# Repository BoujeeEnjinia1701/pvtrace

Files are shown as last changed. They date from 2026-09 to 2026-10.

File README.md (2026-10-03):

# PVTrace

     

**Area:** CleanTech · **TRL:** 3 of 9 (proof of concept on paper) · **Prototype cost:** about USD 192 (value-engineering target USD 165) · **Difficulty:** 3 of 5

A handheld solar panel IV curve tracer that sweeps a panel's current and voltage in the field, flags shading, cracked cells and degraded strings, and helps grade second-life panels.

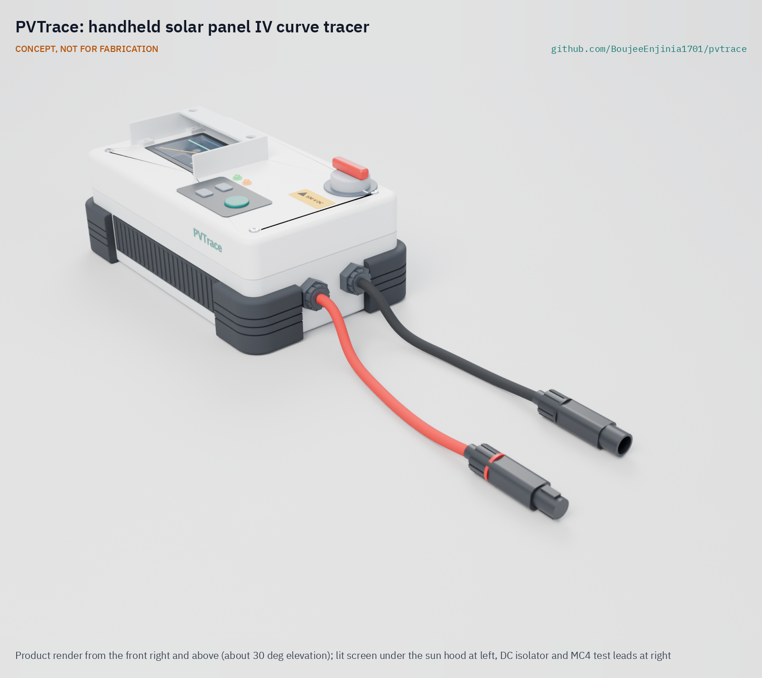
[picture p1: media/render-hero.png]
PVTrace: handheld solar panel IV curve tracer, product render


[Exploded render](media/render-exploded.png) · [Interactive 3D model](media/viewer.html) · [Concept blueprint (PDF)](media/concept-blueprint.pdf) · [General arrangement PVT-DWG-001 (PDF)](cad/drawings/PVT-DWG-001.pdf) · [Sizing calculations](docs/04-calcs/01-sizing.md) · [Prototype build plan](docs/05-build-plan.md) · [Design decisions](docs/06-design-decisions.md) · [Review note](docs/REVIEW.md)

## Concept rationale

An IV curve is the most informative single test of a solar module: one sweep from short circuit to open circuit shows its power, and the shape of the curve points to shading, a failed bypass diode, cracked cells, corroded connections or plain wear. PVTrace uses the simplest load that can trace that curve, a capacitor bank that the module charges in a few tens of milliseconds, as proven open designs such as [IV Swinger 2](https://github.com/csatt/IV_Swinger) and [Cáceres et al. (2020)](https://doi.org/10.3390/en13174320) have done. It adds what a field user needs: a handheld case with a screen, an irradiance reference cell and temperature probe, translation to standard test conditions and a transparent grading rule.

Keeping it open and garage-buildable matters because the people who most need to grade panels, small installers, repair shops and second-life programs in lower-income markets, are the least able to buy a commercial tracer. PVTrace stays below 100 V so it remains an extra-low-voltage instrument for single modules and short strings, uses about USD 178 of common parts, and writes every sweep to an open CSV file that anyone can check or reprocess.

## Burning platform

Solar is being installed faster than ever: global capacity rose to nearly 3 TW at the end of 2025, with about 698 GW added in that year ([IEA PVPS, 2026](https://iea-pvps.org/snapshot-reports/snapshot-2026/)). Panel waste could reach 78 million tonnes by 2050 ([IRENA and IEA PVPS, 2016](https://www.irena.org/publications/2016/Jun/End-of-life-management-Solar-Photovoltaic-Panels)), yet about 70 % of modules are taken down before the end of their 25 to 30 year design life ([Huang and Long, *Nature Communications*, 2026](https://www.nature.com/articles/s41467-026-69171-z)), and field data show a median power loss of only about 0.5 % a year ([Jordan and Kurtz, 2013](https://onlinelibrary.wiley.com/doi/abs/10.1002/pip.1182)). Many removed modules could work for years more.

The obstacle is trust. Refurbished modules exported to secondary markets show 10 to 20 % power loss and inconsistent quality ([Huang and Long, 2026](https://www.nature.com/articles/s41467-026-69171-z)), and a buyer cannot see that by eye. A commercial tracer that would show it costs thousands of dollars; a single-module kit lists at $3,799 ([Transcat](https://www.transcat.com/seaward-pv210-solar-kit-389a912)).

## Where it could be used

### By industry

| Industry | Use |
| --- | --- |
| Panel reuse and recycling | Grade removed modules as A, B, C or reject before resale or recycling, with a logged curve for each |
| Solar installation and maintenance | Find the underperforming module, bypass diode or connector in a small rooftop or off-grid array |
| Off-grid and mini-grid operators | Check modules on delivery and during annual maintenance in remote sites |
| Technical and vocational training | Teach how curve shape reveals faults, with an instrument students can build and repair |
| Research | Log low-cost outdoor curves over months for degradation studies |
| Used-panel trade and consumer protection | Let a buyer or inspector check a seller's power claim on the spot |

### By country or region

| Country or region | Why it matters there |
| --- | --- |
| Sub-Saharan Africa and the Middle East | Projected PV waste of about 1.6 and 1.7 million tonnes by 2050, over 90 % from imported modules, many of them second-hand ([Huang and Long, 2026](https://www.nature.com/articles/s41467-026-69171-z)). |
| India | Cumulative solar waste could reach up to 600 kilotonnes by 2030 ([CEEW, 2024](https://www.ceew.in/press-releases/robust-recycling-increasing-solar-waste-critical-indias-energy-security-ceew)); a large repair and resale trade can use cheap grading. |
| Australia | World-leading rooftop solar per person and about 280,000 tonnes of end-of-life panels by the end of 2025; researchers propose a resale certification with simple grades ([UniSA, 2025](https://unisa.edu.au/media-centre/Releases/2025/old-solar-panels-can-power-new-future/)). |
| United States | Up to 1 million tons of panel waste expected by 2030 and up to 10 million tons by 2050 ([US EPA](https://www.epa.gov/hw/end-life-solar-panels-regulations-and-management)); reuse programs need test data per module. |
| European Union | PV panels are category 4 equipment under the WEEE Directive ([Directive 2012/19/EU, Annex I and II](https://eur-lex.europa.eu/legal-content/EN/TXT/HTML/?uri=CELEX:32012L0019)), so a logged test per module helps decide between reuse and recycling. |

## What sparked the idea

The starting point was the hailstorm of March 15, 2024, which damaged thousands of modules at the 350 MW Fighting Jays solar farm in Fort Bend County, Texas ([*Newsweek*, 2024](https://www.newsweek.com/thousands-solar-panels-texas-destroyed-hailstorm-1883546); [VDE Americas, 2025](https://www.vde.com/en/vde-americas/newsroom/250114-reevaluating-fighting-jays)). Shattered glass is easy to see after a storm like that, but a module with intact glass can still carry cracked cells, and every module that comes off a damaged array needs a call: back on the rack, resale, or recycling. A glance or a single voltage reading cannot make that call; an IV curve taken at the module, with the result logged, can. PVTrace is sized for that job: one module or a short string at a time, on the ground next to the array or at a reuse yard.

## Problem

Installers and reuse programs judge panels by eye or by a single voltage reading, missing faults that an IV curve shows at once. Commercial tracers cost thousands of dollars.

Full problem statement: [docs/01-problem.md](docs/01-problem.md)

## Concept

A handheld tracer for single modules and short strings up to 100 V and 20 A. The module charges a 6.6 mF capacitor bank in about 20 to 68 ms (calculated) while the tracer samples 400 or more voltage and current pairs. A reference cell and a probe on the module back give irradiance and temperature, so the curve can be translated to standard test conditions (IEC 60891). A digital isolator separates the measurement side from the controller and USB port. The tracer flags shading or bypass diode steps, high series resistance, low shunt resistance and current loss, grades second-life modules against nameplate, and saves every sweep as CSV. A printed sun hood shades the display. Calculated mass is about 1.49 kg and battery life about 10 h. Value-engineering target: USD 165; estimated cost of the constructable design: USD 178 (USD 13 over the target).

Full design precis: [docs/02-concept.md](docs/02-concept.md) · Requirements: [docs/03-requirements.md](docs/03-requirements.md) · Sizing: [docs/04-calcs/01-sizing.md](docs/04-calcs/01-sizing.md) · Decisions: [docs/decisions/0001-trl2-review-decisions.md](docs/decisions/0001-trl2-review-decisions.md), [docs/decisions/0002-recommendations-accepted.md](docs/decisions/0002-recommendations-accepted.md), [docs/decisions/0003-design-for-construction.md](docs/decisions/0003-design-for-construction.md)

The 20 ms minimum sweep time for high-current modules is met on paper because the capacitors are measured at build and a bank of 6.45 mF or more is selected (Amish decided on 2026-10-02 on at least 6.4 mF and on 2026-10-03 that the minimum is 6.45 mF, because 6.4 mF gives 19.9 ms). Not met on paper at TRL 3: sunlight readability of the display (a sun hood is now fitted, but readability cannot be shown until a field check), and insulation screening of second-life modules (out of scope; use an insulation tester alongside). The estimated cost, USD 192 (with a keypad, status LEDs and a spare capacitor), is USD 27 over the USD 165 value-engineering target; savings worth trying are in the [design decisions register](docs/06-design-decisions.md). Details are in the [review note](docs/REVIEW.md).

## Key components

- Capacitive load: 3 x 2200 µF 160 V capacitors (6.6 mF), load and discharge MOSFETs, 22 ohm 50 W dump resistor
- Measurement board: 4 milliohm shunt, current-sense amplifier, voltage divider, dual 12-bit ADC
- Isolation barrier: digital isolator and isolated DC-DC converter between the measurement side and the controller
- Reference cell and module temperature probe in a clip-on sensor pod
- ESP32 controller with 2.8 in display, microSD logging and Wi-Fi export
- 20 A DC fuse, 2-pole DC isolator and MC4 test leads
- Protected 18650 Li-ion cell with USB-C charging and a temperature cut-off
- IP54 light grey handheld case, about 220 x 130 x 80 mm, with a printed display sun hood, a polycarbonate chassis plate inside and a USB-C charging socket

The priced bill of materials is in [bom/bom.csv](bom/bom.csv); the parametric model is `cad/src/model.py`, with STEP and STL exports in `cad/step` and `cad/stl`.

## Building the prototype

The prototype build plan ([docs/05-build-plan.md](docs/05-build-plan.md)) shows how to make and fit every component, with a making sketch for each made part, close-ups of the joints and a picture for each of the 12 assembly steps. Every part in the case body is screwed to a clear polycarbonate chassis plate that is built on the bench and lowered in as one unit; the display board hangs under the lid on the same four screws that hold the sun hood. Eight parts are made with hand tools and a 3D printer; the rest are bought. Making the concept buildable changed no function and is recorded in [PVT-DDR-003](docs/decisions/0003-design-for-construction.md). It is a plan only: building and testing to it is TRL 4 work.

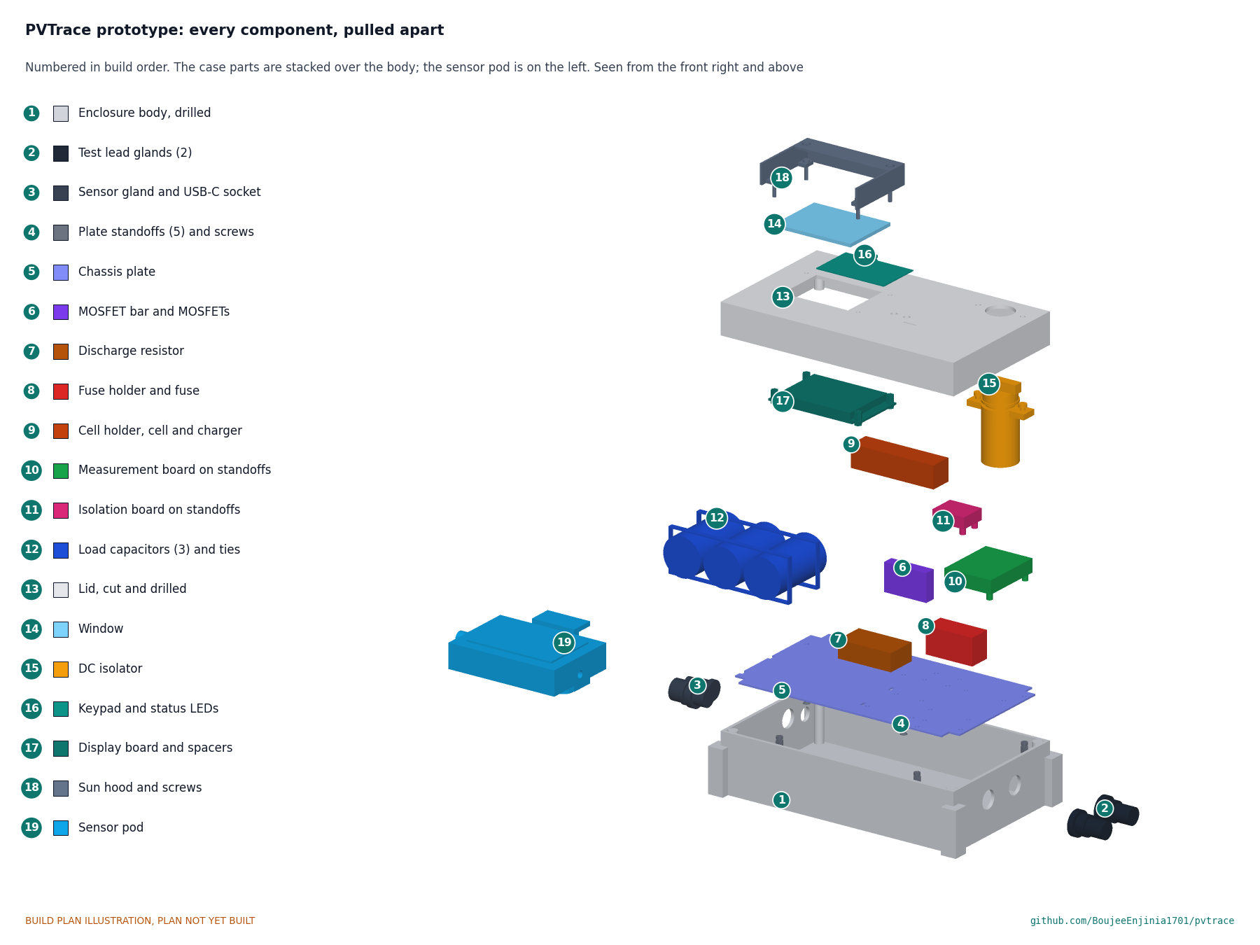
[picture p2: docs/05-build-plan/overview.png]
PVTrace prototype: every component, pulled apart and numbered in build order


## Safety

> Solar panels produce dangerous DC voltage whenever light falls on them and cannot be switched off. Rate leads and switching for the full voltage and current, mate and unmate MC4 connectors only with the isolator open, and never break a DC circuit under load. PVTrace is limited to 100 V DC; never connect it to a longer string. The load capacitors store up to 33 J and must be discharged before the case is opened. The instrument contains a Li-ion cell; charge it in shade on a non-flammable surface and not while connected to a module. In full sun the case can get hot inside; keep it in shade between sweeps. Handle modules with gloves: frames are sharp and broken glass can cut.

## Repository layout

| Folder | Contents |
| --- | --- |
| `docs/` | Problem, concept, requirements, calculations, prototype build plan and design decisions |
| `cad/src/` | build123d Python source, the source of truth for all geometry |
| `cad/step/`, `cad/stl/` | Exported models for FreeCAD, other CAD tools and printing |
| `cad/drawings/` | 2D sketches and dimensioned drawings |
| `bom/` | Bill of materials |
| `electronics/` | KiCad schematics and PCB layouts |
| `firmware/` | Microcontroller code |
| `media/` | Renders, perspectives and photos |
| `build-log/` | Dated prototyping notes |

## Documentation

Controlled documents follow the portfolio [documentation standard](.kit/STANDARDS.md). Each carries a document ID (PVT-PRC-001 for the precis), a version and a revision history. Branded PDFs are built with `python .kit/render.py` and attached to GitHub Releases when a document is tagged, for example `PVT-PRC-001/v1.0`.

## Credits

Designed by Amish Chadha. See [CONTRIBUTORS.md](CONTRIBUTORS.md) for roles. To cite this design, use [CITATION.cff](CITATION.cff) (GitHub shows it as "Cite this repository").

AI assistance (Claude) was used to accelerate concept renders, prototype documentation and first-pass sizing calculations. Design direction and all decisions are Amish Chadha's, recorded in this repository's decision records (`docs/decisions/`).

## Licenses

- **Hardware** (CAD, drawings, BOM, electronics): [CERN-OHL-S v2](LICENSE)
- **Software** (firmware, scripts, notebooks): [MIT](LICENSE-SOFTWARE)

A project of the [Design Molecule](https://designmolecule.com) lab.

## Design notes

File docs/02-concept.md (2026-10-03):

---
doc_id: PVT-PRC-001
title: PVTrace design precis
project: PVTrace
doc_type: Design precis
version: "0.8"
status: Draft
date: '2026-10-03'
author: Amish Chadha
license: CERN-OHL-S-2.0
revisions:
- version: "0.1"
  date: '2026-09-25'
  author: Amish Chadha
  change: Initial scaffold
- version: "0.2"
  date: '2026-09-25'
  author: Amish Chadha
  change: Concept for TRL 2; how it works, components, first-order numbers, proposed choices, safety, open questions
- version: "0.3"
  date: '2026-09-25'
  author: Amish Chadha
  change: TRL 3 update; design choices adopted per PVT-DDR-001 (6.6 mF, isolation barrier, TFT, reference cell, ESP32, grades); numbers from PVT-CAL-001; larger case; 33 J safety figure
- version: "0.4"
  date: '2026-09-25'
  author: Amish Chadha
  change: Recommendations accepted by Amish (DDR-002)
- version: "0.5"
  date: '2026-10-01'
  author: Amish Chadha
  change: "Constructable design (PVT-DDR-003): chassis plate, USB-C socket, fixings, pod clip; mass and cost updated; budget as a value-engineering target"
- version: "0.6"
  date: '2026-10-02'
  author: Amish Chadha
  change: 'Decisions of 2026-10-02 carried in (PVT-DEC-001 items 2 to 6): capacitor selection for R3, pod read on the controller side, mass margin, partner type, keypad and status LEDs'
- version: "0.7"
  date: '2026-10-02'
  author: Amish Chadha
  change: "Keypad and status LEDs added to the model and BOM (line 18); capacitor selection calculated (R3 met on paper); cost USD 192 (USD 27 over the target); mass margin about 6 g"
- version: "0.8"
  date: '2026-10-03'
  author: Amish Chadha
  change: "Capacitor bank minimum restated as 6.45 mF, decided by Amish on 2026-10-03; 'proposed, awaiting Amish' removed"
---

# PVTrace design precis

## Summary

PVTrace is a handheld, battery-powered IV curve tracer for single PV modules and short strings up to 100 V and 20 A. It sweeps the module from short circuit to open circuit by letting it charge a 6.6 mF capacitor bank in about 20 to 68 ms, samples several hundred voltage and current pairs, reads irradiance from a reference cell and temperature from a probe on the module back, translates the curve to standard test conditions (STC) and shows fault flags and a second-life grade on its screen. A digital isolator and an isolated DC-DC converter separate the measurement side from the controller and USB port. Every sweep is saved as an open CSV file. Value-engineering target: USD 165. Estimated cost of the constructable design: USD 178 (USD 13 over the target). The capacitive load follows proven open designs (IV Swinger 2; Cáceres et al., 2020, see PVT-PRB-001); what is new is a standalone field instrument with sensing, translation and a transparent grading rule.

The design choices in this precis were decided by Amish on 2026-09-25 (go with recommendation; PVT-DDR-001 and PVT-DDR-002). Sizing is in PVT-CAL-001; the general arrangement is drawing PVT-DWG-001. The design was made constructable on 2026-10-01 (PVT-DDR-003): every part now has a fixing, and the prototype build plan PVT-BLD-001 shows how to make and fit each one.

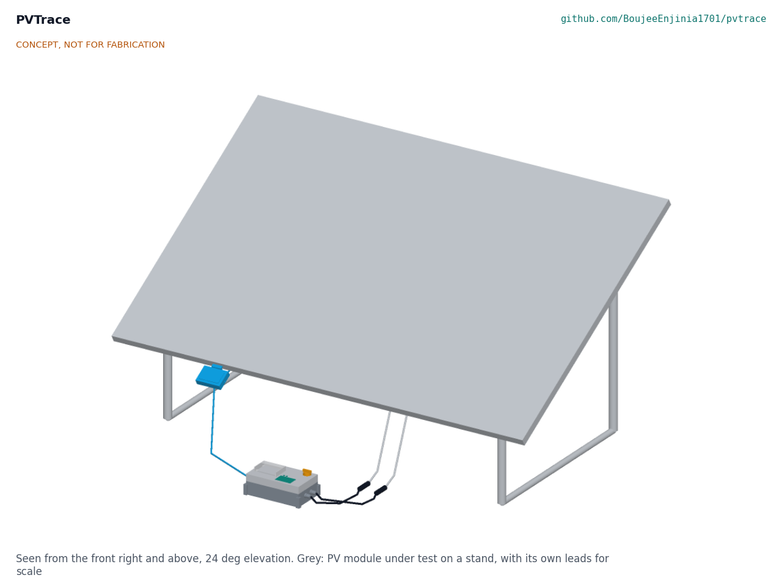
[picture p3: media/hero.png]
Figure 1. PVTrace in use: the tracer on the ground, test leads mated to the module's own MC4 leads and the sensor pod clipped to the lower frame edge.


Figure 1. PVTrace in use (concept massing model; grey module and stand for scale).

## How it works

1. **Connect.** The user mates the two MC4 test leads to the module's leads with the DC isolator open, clips the sensor pod to the module's lower frame so the reference cell lies in the module plane, and presses the probe onto the module back.
2. **Check.** With the isolator closed and the load switch off, the controller reads open-circuit voltage through the divider. It refuses to continue if the polarity is reversed or Voc exceeds 100 V.
3. **Sweep.** The load MOSFET closes onto the discharged capacitor bank. The module first delivers close to its short-circuit current, then the capacitor voltage rises through the knee to Voc. The ADC on the isolated measurement side samples voltage and current in pairs throughout and sends them to the controller through the digital isolator. The capacitor current decays toward zero near Voc; firmware keeps the MOSFET closed until the current is below 0.5 A, so it never opens a loaded DC circuit.
4. **Dump.** The load MOSFET opens and a second MOSFET discharges the bank through a 22 ohm aluminium-clad resistor, below 30 V in about 0.2 s. A permanent 10 kohm bleed resistor empties the bank if the controller fails.
5. **Analyze.** Firmware extracts Isc, Voc, Pmax, Vmp, Imp and fill factor, estimates series and shunt resistance from the slopes near Voc and Isc, and looks for steps that show bypass diode conduction.
6. **Translate and grade.** Using irradiance, module temperature and the datasheet coefficients the user selects, it translates the curve to STC with IEC 60891 procedure 1 and compares Pmax with nameplate to give a grade.
7. **Log.** The sweep, conditions, flags and grade go to microSD and can be exported by USB or to a phone over Wi-Fi.

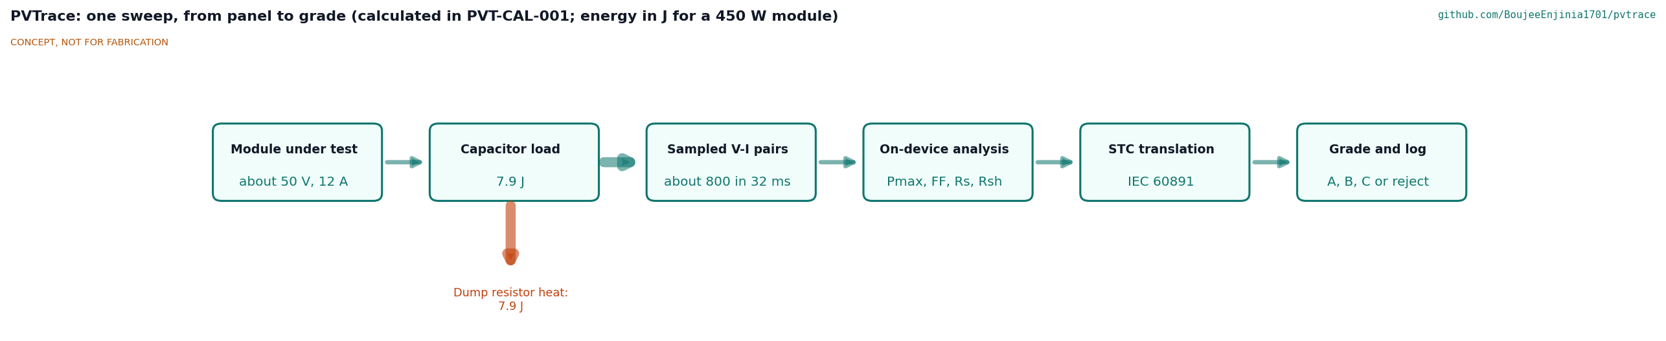
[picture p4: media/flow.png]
Figure 2. One sweep from module to grade, with estimated energy per sweep for the reference module.


Figure 2. Measurement and energy flow for one sweep (estimates).

## Main components

Numbers match `bom/bom.csv` and the exploded view (Figure 3).

Table 1. Main components

| No. | Component | Role |
| --- | --- | --- |
| 1 | Enclosure body, IP54 ABS handheld case about 220 x 130 x 80 mm, light grey, with rubber corner bumpers and three cable glands | Houses and protects the electronics |
| 2 | Enclosure lid with a 72 x 54 mm polycarbonate window bonded over a 62 x 46 mm opening | Closes the case; window for the display |
| 3 | Controller and 2.8 in display board (ESP32 class, microSD) | Runs the sweep, analysis, grading, logging, Wi-Fi export |
| 4 | Measurement board: 4 milliohm shunt, current-sense amplifier (INA240 class), voltage divider, dual 12-bit ADC with precision reference, MOSFET gate driver supply | Measures V and I during the sweep, on the PV side of the isolation barrier |
| 5 | Load capacitors, 3 x 2200 µF 160 V electrolytic (6.6 mF) | The sweep load |
| 6 | Load and discharge MOSFETs (150 V class) with gate driver on an aluminium bar | Connects and empties the load |
| 7 | Discharge resistor, 22 ohm 50 W aluminium clad, plus 10 kohm 3 W passive bleed | Absorbs the stored energy |
| 8 | DC fuse, 20 A gPV 10 x 38 mm, in a DC-rated holder | Protects the leads and switch from a fault |
| 9 | DC isolator, 2-pole, rated 20 A at 250 V DC or more | Separates the instrument from the module when not sweeping |
| 10 | Li-ion 18650 protected cell, holder, USB-C charger with temperature cut-off, 5 V boost and protection | Powers the controller, display and, through item 14, the measurement side |
| 11 | Test leads, 2 x 1 m, 4 mm² double-insulated PV cable with MC4 connectors | Connects to the module |
| 12 | Sensor pod: reference cell and shaded temperature probe, frame clip, 3 m cable | Measures irradiance and module temperature |
| 13 | Hardware and consumables (not modeled) | Screws, standoffs, wire, gaskets |
| 14 | Isolation barrier: 4-channel digital isolator and 1 W isolated DC-DC converter | Separates the PV-side measurement board from the controller, USB port and battery |
| 15 | Display sun hood, printed light grey PETG, 92 x 64 x 18 mm, three walls, a 20 mm roof lip and four screw tabs, open toward the user | Shades the display window to improve contrast in sun (PVT-DDR-002 item 12); its screws also hold the display board |
| 16 | Chassis plate, 1.5 mm polycarbonate on five standoffs | Carries every part in the case body; lifts out as one unit (PVT-DDR-003) |
| 17 | USB-C charging socket, IP65 with cap, in the left end | Charges the cell with the case closed (R14; PVT-DDR-003) |
| 18 | Keypad, 3-key membrane, and two status LEDs on the lid, controller side | Starts a sweep and steps through menus; shows ready and live DC (PVT-DEC-001 item 6) |

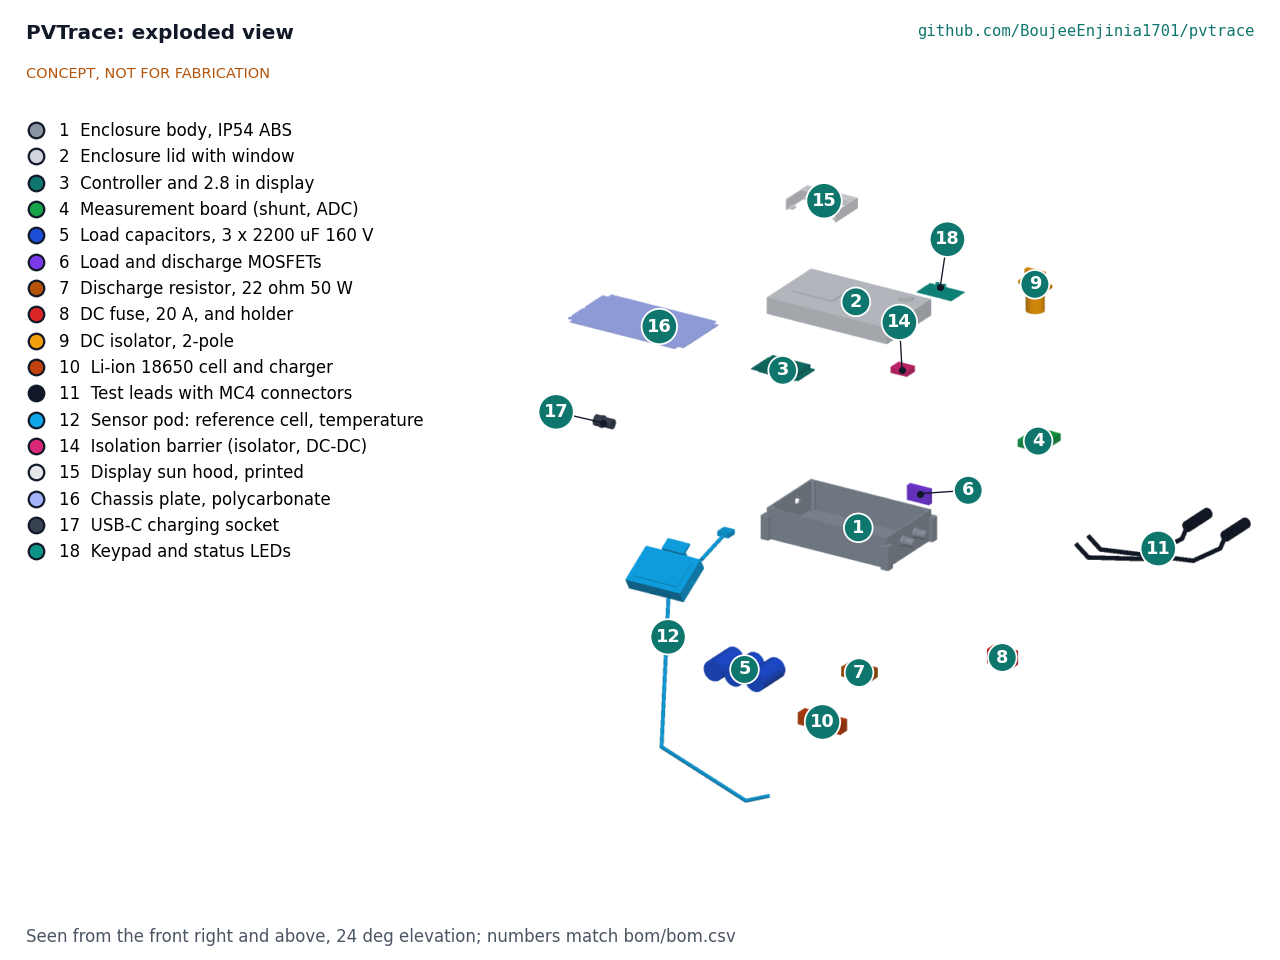
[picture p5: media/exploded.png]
Figure 3. Exploded view with BOM callouts.


Figure 3. Exploded view; callouts match Table 1.

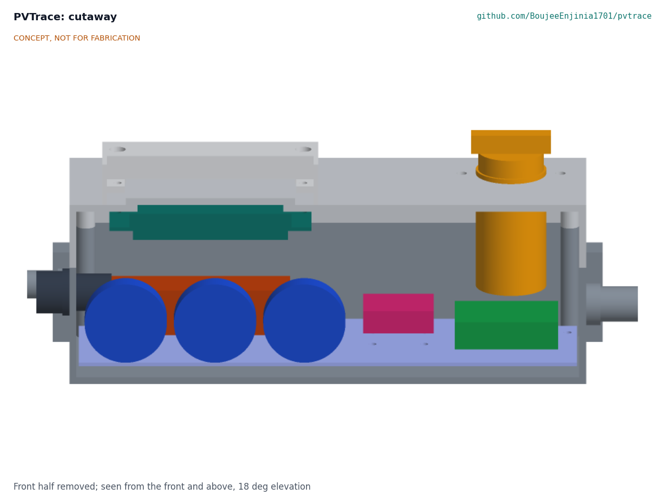
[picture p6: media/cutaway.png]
Figure 4. Section through the enclosure.


Figure 4. Cutaway looking toward the back wall: the three capacitors (blue) in front of the battery (orange), isolation board (pink) and measurement board (green) on the floor, DC isolator (amber) through the lid, controller and display (teal) under the window.

## Key numbers

All values are calculated in PVT-CAL-001 and are estimates for a paper design.

Table 2. Sweep with a 6.6 mF load (single-diode model, time from 0 V to 99 % of Voc)

| Case | Voc (V) | Isc (A) | Sweep, nominal (ms) | Sweep, -20 % capacitance (ms) | Energy stored (J) |
| --- | --- | --- | --- | --- | --- |
| 36-cell 100 W | 22.0 | 6.0 | 28.9 | 23.1 | 1.6 |
| 108 half-cell 410 W (high current) | 37.5 | 13.9 | 20.5 | 16.4 | 4.5 |
| 144 half-cell 450 W (reference) | 49.5 | 11.6 | 32.2 | 25.8 | 7.9 |
| 2 x 60-cell 250 W in series (high voltage) | 75.2 | 8.9 | 67.5 | 54.0 | 18.3 |
| Rating limit | 100 | 20 | 37.7 | 30.1 | 33 at 100 V |

Assumptions: datasheet-class values; 56.6 mΩ loop resistance; module capacitance ignored (see PVT-CAL-001 section 2).

- **Sweep time.** The high-current case meets the 20 ms lower bound of R3 at nominal capacitance (20.5 ms) but not at -20 % tolerance (16.4 ms). R3 is not met with capacitors as bought. Amish decided on 2026-10-02 (PVT-DEC-001, item 4) that each capacitor is measured at build and a set giving at least 6.4 mF is selected; because 6.4 mF gives 19.9 ms, Amish decided on 2026-10-03 that the minimum is 6.45 mF, which holds about 20 ms (20.05 ms on the high-current case, PVT-CAL-001 v0.5). R3 is met on paper with the selected bank; the 20 ms bound is relaxed later only if TOPCon and HJT capacitance data justify it.
- **Samples.** At 25,000 pairs per second a sweep yields 410 pairs or more (R4). Firmware interpolates each voltage to the time of its current sample, which removes up to 0.16 % error in Pmax.
- **Resolution.** Voltage full scale 109.1 V, 26.6 mV per count; current full scale 20.48 A, 5.00 mA per count. After calibration about ±0.2 % of reading ±0.03 % of full scale (R5).
- **Discharge.** 22 ohm with 6.6 mF gives a 145 ms time constant: 100 V falls below 30 V in 0.21 s with +20 % capacitance. Peak dump power is 455 W for milliseconds; at one sweep every 5 s the average is 1.6 W for the reference module and 6.6 W at 100 V. The 10 kohm bleed takes 100 V below 60 V in 40 s and draws 10 mA at 100 V, which firmware subtracts.
- **Opening current.** At 99 % of Voc the module still delivers up to 2.5 A, so the load switch stays closed up to 6 ms longer until the current is below 0.5 A.
- **Battery.** 0.85 W at 5 V (controller, display and isolated side), 0.94 W from the cell: about 10.3 h from a 3,000 mAh 18650.
- **Heat.** In full sun at 45 °C ambient the inside of a light grey case reaches about 56 °C, a dark case about 73 °C. The case is therefore light grey, the charger has a temperature cut-off, a printed hood shades the display, and the tracer should stay in shade between sweeps.
- **STC uncertainty.** Root-sum-square ±3.7 to ±5.4 %; R8 (±5 %) needs a reference cell calibrated within ±4.5 %.
- **Mass.** About 1.49 kg with leads, sensor pod, sun hood and chassis plate (R12 met, about 6 g to spare after the keypad and LEDs).
- **Cost.** Value-engineering target: USD 165 (`budget_usd`, a hypothetical control target, not a limit). Estimated cost of the constructable design: USD 192 (USD 27 over the target; see `bom/bom.csv`), including a spare load capacitor for selection and the keypad and status LEDs.

## Fault flags and grading (draft rules)

Table 3. Draft fault rules

| Flag | Curve symptom | Draft rule |
| --- | --- | --- |
| Shading or bypass diode active | Step or plateau in the curve | Local minimum in dI/dV, or current drop of 10 % or more within 3 % of Voc, below Vmp |
| High series resistance | Shallow slope near Voc | Estimated Rs more than 1.5 times the model value for the module type |
| Low shunt resistance | Steep slope near Isc | Estimated Rsh below 10 times Vmp/Imp |
| Current deficit (soiling, degradation, cracks) | Isc low against irradiance | Isc at STC below 90 % of nameplate |
| Missing substring | Voc about one third low | Voc at STC below 70 % of nameplate |

Grades from STC Pmax against nameplate (decided by Amish, PVT-DDR-001 item 8): A 90 % or more, B 80 to 90 %, C 70 to 80 %, reject below 70 % or with any safety defect found by visual inspection (broken glass, burnt junction box, delaminated backsheet). Grades are indicative; they are not a certification.

## Key design choices

Items 1 to 8 were decided by Amish on 2026-09-25: go with recommendation (PVT-DDR-001, PVT-DDR-002). The options considered are in PVT-PRC-001 v0.2 and `docs/REVIEW.md`.

1. **Load type.** Capacitive load: simple, fast, low heat, proven in open designs.
2. **Voltage and current rating.** 100 V, 20 A: single modules and two in series, below the 120 V DC extra-low-voltage limit. Two 450 W modules in series exceed it when cold and are refused.
3. **Load capacitance.** 6.6 mF with three capacitors. It meets R3 at nominal capacitance but not at -20 % tolerance; the capacitors are measured at build and a set of at least 6.45 mF is selected (decided 2026-10-02 at 6.4 mF and restated to 6.45 mF on 2026-10-03, PVT-DEC-001 item 4).
4. **Isolation of the controller from the PV side.** Option B: a digital isolator and isolated DC-DC converter between the measurement board and the controller, so a laptop on USB is not tied to PV potential.
5. **Display and interface.** 2.8 in TFT plus phone export. A printed sun hood is fitted (item 12, decided); readability in direct sun is still not shown on paper (R13).
6. **Irradiance sensing.** A small reference cell measured at short circuit and calibrated once against a pyranometer.
7. **Controller.** ESP32 display board.
8. **Grade thresholds.** As in the grading rules above, held in an editable table and still to be agreed with a second-life partner; the first candidate type to approach is a refurbisher or recycler that tests used modules in volume (decided 2026-10-02, PVT-DEC-001 item 5).

Also decided by Amish on 2026-09-25: the $165 budget (a value-engineering target since 2026-10-01), the sun hood and the 220 x 130 x 80 mm case (items 9, 12 and 13). Decided by Amish on 2026-10-02 (PVT-DEC-001): the first co-design partner type (item 10) and the R3 shortfall at tolerance (item 11, capacitor selection at build). Also decided then: the pod is read on the controller side of the isolation barrier, the 14 g mass margin is accepted, and a keypad and status LEDs (BOM line 18, lid slot and two holes) are added for input, since the display's touch screen sits behind the bonded window.

## Links to other lab projects

- **CellCheck** grades salvaged lithium cells for rebuilt packs; PVTrace applies the same measure, grade and log approach to modules. A shared grade-label and CSV format would help both.
- **CalRig** can check PVTrace's module temperature probe from 10 to 40 °C (its reference is ±0.2 °C). It does not reach module temperatures of 60 °C or more and does not provide irradiance references, so the reference cell needs a separate calibration route.
- PVTrace does not use a SwapCell pack; a single 18650 cell is enough.

## Safety

> **Safety:** PV modules are live whenever light falls on them. The tracer handles up to 100 V DC and 20 A, which can cause burns and sustained DC arcs. Mate and unmate MC4 connectors only with the isolator open and never under load. Use brand-matched MC4 connectors from one maker; mixed brands can overheat.

> **Safety:** The load capacitors store up to 33 J at 100 V. Active and passive discharge paths are required; treat the capacitors as charged until the display reads below 30 V, and never open the case with the leads connected.

> **Safety:** The discharge resistor and MOSFET bar get hot under repeated sweeps; firmware limits the sweep rate to one every 5 s.

> **Safety:** The instrument contains a Li-ion cell. Use a protected cell, charge it only with the isolator open, in shade, on a non-flammable surface, within 0 to 45 °C, and never leave it charging unattended in a hot vehicle. In full sun the inside of the case can pass 45 °C (PVT-CAL-001); the charger's temperature cut-off must not be bypassed.

> **Safety:** Handling modules involves sharp frame edges, heavy glass (about 20 to 25 kg for large modules) and work at height on rooftops. Broken modules can cut and may still be live. Wear gloves and eye protection, and follow local rules for work at height.

> **Safety:** Do not connect PVTrace to a string of an installed grid-connected system unless the owner has isolated it from the inverter and the string Voc is below 100 V.

## Open questions

- [ ] Is 20 ms the right lower bound on sweep time for TOPCon and HJT modules, or is a longer sweep needed? Until capacitance data justify a change, the bound stays and the capacitor bank is selected to at least 6.45 mF (PVT-DEC-001, item 4).
- [x] How to capture true Isc: extrapolate from the first samples, which start 1 to 2 % of Voc above zero (PVT-CAL-001); no negative pre-charge.
- [ ] Which reference cell and calibration route give ±3 % or better at low cost?
- [ ] Is a commodity TFT with the sun hood readable in sun, or is a transflective display needed? (Field check, TRL 4.)
- [ ] What grade label format would buyers and a certification scheme accept?
- [ ] Should the firmware support two modules in parallel (current to 20 A at lower voltage) as well as in series?

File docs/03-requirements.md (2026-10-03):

---
doc_id: PVT-REQ-001
title: PVTrace requirements
project: PVTrace
doc_type: Requirements
version: "0.8"
status: Draft
date: '2026-10-03'
author: Amish Chadha
license: CERN-OHL-S-2.0
revisions:
- version: "0.1"
  date: '2026-09-25'
  author: Amish Chadha
  change: Initial scaffold
- version: "0.2"
  date: '2026-09-25'
  author: Amish Chadha
  change: First measurable requirements with concept status for TRL 2
- version: "0.3"
  date: '2026-09-25'
  author: Amish Chadha
  change: Status from PVT-CAL-001; decisions from PVT-DDR-001 (6.6 mF, isolation, grade thresholds); R10 and R17 wording; 33 J stored energy
- version: "0.4"
  date: '2026-09-25'
  author: Amish Chadha
  change: Recommendations accepted by Amish (DDR-002)
- version: "0.5"
  date: '2026-10-01'
  author: Amish Chadha
  change: Constructable design (PVT-DDR-003); R12 mass 1.49 kg; R17 reported against the value-engineering target
- version: "0.6"
  date: '2026-10-02'
  author: Amish Chadha
  change: R3 and R12 status notes record the 2026-10-02 decisions (PVT-DEC-001, items 3 and 4); no status changed
- version: "0.7"
  date: '2026-10-02'
  author: Amish Chadha
  change: "R3 now met on paper with the capacitor bank selected at build (PVT-CAL-001 v0.5); R17 restated to USD 192, USD 27 over the target; R12 margin about 6 g"
- version: "0.8"
  date: '2026-10-03'
  author: Amish Chadha
  change: "R3 wording: selected capacitor bank minimum of 6.45 mF decided by Amish on 2026-10-03"
---

# PVTrace requirements

These requirements are proposals for review, not yet agreed with users, and will be revised after co-design (see PVT-PRB-001). The status column gives the design's position against each target from the calculations in PVT-CAL-001 (TRL 3). Two requirements are **not met** on paper (R13 display readability, R16 out of scope), ten are met including R3 with the capacitor bank selected at build, two are at risk (R7, R8) and two cannot be verified until hardware exists (R6, R9). R17 is reported against the value-engineering target (`budget_usd`, USD 165, a hypothetical control target, not a limit; Amish, 2026-10-01): the constructable design of PVT-DDR-003 with the keypad, status LEDs and a spare capacitor is estimated at USD 192, USD 27 over the target. The design choices were decided by Amish on 2026-09-25 (go with recommendation; PVT-DDR-001 and PVT-DDR-002).

The **reference module** is a 144 half-cell module of about 450 W: open-circuit voltage (Voc) about 49.5 V, short-circuit current (Isc) about 11.6 A. The **high-current case** is a 108 half-cell 182 mm module of about 410 W (Voc about 37.5 V, Isc about 13.9 A). The **high-voltage case** is two older 60-cell 250 W modules in series (Voc about 75 V, Isc about 8.9 A).

Table 1. Requirements

| ID | Requirement | Target | Verification (TRL 3 or later) | Status (PVT-CAL-001) |
| --- | --- | --- | --- | --- |
| R1 | Voltage range | 0 to 100 V DC open circuit, including cold-weather Voc rise; hard limit below 120 V | Component ratings; calculation | Met by design review: high-voltage case 83 V at -10 °C; 160 V capacitors, 150 V MOSFETs. Two 450 W modules in series (109 V cold) are refused |
| R2 | Current range | 0 to 20 A short circuit | Shunt and switch ratings | Met by design review: 20.48 A full scale; shunt 1.6 W of 3 W |
| R3 | Sweep duration, to limit capacitive error in high-efficiency cells | 20 to 200 ms from Isc to Voc for any module in range | Sweep model; later bench sweep | **Met on paper with a selected bank** (changed from not met on 2026-10-02): Amish decided to measure the capacitors at build and select a set of at least 6.4 mF (PVT-DEC-001, item 4); on 2026-10-03 he decided the minimum is 6.45 mF. The high-current case then sweeps in 20.1 ms at 6.45 mF (19.9 ms at exactly 6.4 mF); longest 81 ms. Capacitors as bought reach only 16.4 ms at -20 % |
| R4 | Curve resolution | 200 or more V-I pairs per sweep | Sample-rate calculation | Met: 410 pairs or more |
| R5 | Measurement accuracy after calibration | Voltage and current within ±1 % of reading ±0.1 % of full scale | Error budget; later check against a calibrated meter | Met on paper: about ±0.2 % of reading ±0.03 % of full scale after calibration |
| R6 | Repeatability | Pmax within ±1 % over 3 consecutive sweeps at stable irradiance (±1 % change) | Later field test | Not verifiable at TRL 3; instrument noise about 0.08 % per sample |
| R7 | Irradiance and temperature | Plane-of-array irradiance within ±5 % from a reference cell; module back temperature within ±2 °C | Calibration plan; CalRig for the temperature probe | At risk: needs a reference cell calibrated within ±4.6 % |
| R8 | STC translation | Pmax translated to STC per IEC 60891 with an expanded uncertainty of ±5 % or better at 700 W/m² or more | Uncertainty budget | At risk: ±3.7 to ±5.4 %; met if the reference cell is within ±4.5 % |
| R9 | Fault flags | Flag steps from bypass diode conduction (loss of one substring or more), raised series resistance, lowered shunt resistance and an Isc deficit against irradiance; shown within 5 s of the sweep | Rule definitions; later tests on modules with known faults | Not verifiable at TRL 3; about 7 or more samples per volt resolve a substring step |
| R10 | Second-life grading | Grade A, B, C or reject from STC Pmax against nameplate, with thresholds held in an editable table that a partner can change | Rule review with partner | Met by design review; thresholds decided by Amish (PVT-DDR-001 item 8); a partner can still tune the table |
| R11 | Safe connection and disconnection | Reverse polarity and over-voltage detected before the load connects; the circuit is never opened above 0.5 A; load capacitors below 30 V within 2 s after each sweep and below 60 V within 60 s if the controller fails | Circuit review; discharge calculation | Met: 0.21 s to 30 V; 40 s passive to 60 V; load switch held up to 6 ms past 99 % of Voc so it opens below 0.5 A |
| R12 | Handheld | Mass 1.5 kg or less including leads and sensor pod; enclosure 250 x 150 x 100 mm or less | Mass estimate; model | Met: 1.49 kg for the constructable design (PVT-DDR-003), about 6 g to spare after the keypad and LEDs (was 14 g), accepted by Amish on 2026-10-02 with the prototype weighed at TRL 4 (PVT-DEC-001, item 3); 234 x 144 x 80 mm over bumpers, 98 mm to the knob and hood tops |
| R13 | Field conditions | Operate at 0 to 45 °C ambient in full sun; IP54 when closed; display readable in direct sun | Datasheets; heat model; later field check | IP54 met by design; **display readability not met** on paper: sun hood fitted (PVT-DDR-002), readability to be shown in a field check (TRL 4); heat at risk (about 56 °C inside a light case at 45 °C in sun) |
| R14 | Battery life | 8 h of field use or 200 sweeps per charge; USB-C charging | Power budget | Met: 10.3 h |
| R15 | Open data | Every sweep saved as CSV (raw V-I pairs, irradiance, temperature, time, module ID, flags, grade); export by USB or Wi-Fi to a phone | Design review (no firmware at TRL 3) | Met by design review |
| R16 | Second-life safety screening | Detect insulation faults (cracked backsheet, wet leakage) before a module is resold | Not in this instrument | **Not met**: out of scope; an insulation tester is needed alongside PVTrace |
| R17 | Cost | Parts for one prototype against the value-engineering target in `budget_usd` (USD 165) | Priced BOM (`bom/bom.csv`) | Value-engineering target: USD 165. Estimated cost of the constructable design: USD 192 (USD 27 over the target) |

## Assumptions

- Module curves are modeled with a single-diode model fitted to datasheet Voc, Isc, Vmp and Imp; sweep times are the time for a 6.6 mF load (±20 %) to reach 99 % of Voc, with 56.6 mΩ loop resistance (PVT-CAL-001).
- The ADC delivers at least 25,000 V-I pairs per second in practice (half the rated rate of a 100 kS/s two-channel converter, to allow for SPI and firmware overhead).
- The reference cell is calibrated once against a pyranometer or a module of known power under clear sky; its uncertainty (about ±3 to 5 %) dominates R8.
- The 20 ms lower bound in R3 is a working figure for high-efficiency (PERC, TOPCon, HJT) cells, whose capacitance distorts fast sweeps; it could not be checked against literature at TRL 3 and stays a working figure. PVT-CAL-001 shows the capacitive current error is about C_module / C_load, so it depends on the load capacitance more than on the sweep time.
- 700 W/m² follows IEC 61829 guidance for converting to STC ([Seaward](https://www.seaward.com/gb/support/solar/faqs/29495-curve-tracing-faq-s/)).

> **Safety:** The tracer connects directly to energized PV modules at up to 100 V DC and 20 A, and stores up to 33 J in its load capacitors. R11 exists to keep the user safe; it must not be relaxed to meet cost.

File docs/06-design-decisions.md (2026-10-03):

---
doc_id: PVT-DEC-001
title: PVTrace design decisions register
project: PVTrace
doc_type: Design decisions register
version: "0.4"
status: Draft
date: '2026-10-03'
author: Amish Chadha
license: CERN-OHL-S-2.0
revisions:
  - version: "0.1"
    date: '2026-10-01'
    author: Amish Chadha
    change: Register opened with the open decisions from the review note, the decision records and the build plan work; budget treated as a value-engineering target
  - version: "0.2"
    date: '2026-10-02'
    author: Amish Chadha
    change: Amish approved the recommendations of open items 1 to 6 on 2026-10-02; all moved to decisions made; capacitor selection added to the items to confirm; keypad cost noted
  - version: "0.3"
    date: '2026-10-02'
    author: Amish Chadha
    change: "Cost USD 192 (USD 27 over the target) with the keypad and status LEDs (BOM line 18) and a spare capacitor; R3 met on paper with the selected bank"
  - version: "0.4"
    date: '2026-10-03'
    author: Amish Chadha
    change: "Selected capacitor bank minimum recorded as 6.45 mF, accepted by Amish on 2026-10-03; row added; item 9 of the parts to confirm updated"
---

# PVTrace design decisions register

Every design decision still to be made, and every decision made, in one place. Each decision is argued in full in its decision record under `docs/decisions/`; this register is the index Amish works from. The build plan (`docs/05-build-plan.md`) describes the design as it stands and does not list open decisions.

## Open decisions

None. All open decisions were decided on 2026-10-02.

## To confirm when parts are bought

| # | What to confirm | Why it matters | Source |
| --- | --- | --- | --- |
| 1 | The case model: outside size, flat floor, corner pillar positions and size, lid depth of at least 25 mm inside | Sets the plate size and notches, the floor holes and the room for the display and isolator | PVT-DDR-003 C5, C6 |
| 2 | The display board's size (86 x 50 mm), hole centres (79 x 43 mm) and screen height above the board | Sets the four lid holes and the 7 mm spacer length | PVT-DDR-003 C4 |
| 3 | The DC isolator's panel cut-out, flange and screw pattern, and depth below the lid (47 mm or less) | Sets the lid holes and the 2.5 mm clearance above the measurement board | PVT-DDR-003 C8, C9 |
| 4 | The discharge resistor's free-air (unmounted) rating is at least 7 W; if not, mount it on a small aluminium heat spreader | The resistor now sits on a plastic plate; average dump power is 6.6 W at 100 V and one sweep every 5 s | PVT-DDR-003 Table 2; PVT-CAL-001 section 5 |
| 5 | The fuse holder's base is 44 x 20 mm or less and its DC rating covers 100 V | It sits between the discharge resistor, a corner pillar and the gland nuts with 0.5 to 2 mm to spare | PVT-DDR-003 C1, C6 |
| 6 | The isolation barrier parts' working voltage and test rating | The barrier must withstand module voltage with margin; checked by the 500 V insulation test | `docs/REVIEW.md`, TRL 3 safety concerns |
| 7 | The USB-C socket has an M16 thread, IP65 or better with a tethered cap | Sets the left end hole and keeps IP54 | PVT-DDR-003 C10 |
| 8 | The modules to be tested have frames 30 to 40 mm deep with a bottom flange | The pod clip grips the frame between its top jaw and thumb screw | PVT-DDR-003 C11 |
| 9 | The three load capacitors, measured one by one, give at least 6.45 mF together; if not, select others from a larger batch | R3 at the 20 ms lower bound (decided 2026-10-02) | Decision of 2026-10-02 (open item 4); PVT-CAL-001 section 2 |

## Value engineering

Value-engineering target: USD 165 (a hypothetical control target, not a limit). Estimated cost of the constructable design: USD 192 (USD 27 over the target). Main cost drivers and savings worth trying:

- The largest lines are the display board with its ADC module (USD 21), the four load capacitors, three fitted and one spare (USD 24), the DC isolator (USD 16), the measurement board parts (USD 16), the test leads (USD 16) and the sensor pod (USD 16).
- The decisions of 2026-10-02 added USD 14: the keypad and status LEDs (open item 6, new BOM line 18, USD 8) and a spare load capacitor for selecting the bank (open item 4, USD 6).
- Making the design constructable added USD 14: the chassis plate (USD 3), the USB-C socket (USD 5), the pod ADC module (USD 3), the pod clip and gland (USD 1) and fixings (USD 2).
- Savings worth trying: a fused two-pole DC isolator in one body in place of the separate fuse holder and isolator (about USD 5 to 8, if one fits the lid); test leads made from one 2 m pair of PV cable with crimped MC4 connectors (about USD 4); buying the ESP32 board and ADC module as one bundle (about USD 2).

## Decisions made

| Date | Decision | Decided by | Record |
| --- | --- | --- | --- |
| 2026-09-25 | TRL 2 review items 1 to 8: capacitive load; 100 V, 20 A rating; 6.6 mF; isolation option B; 2.8 in TFT plus phone export; once-calibrated reference cell; ESP32 controller; grade thresholds A 90 %, B 80 %, C 70 % | Amish: "i accept all your recommendations, go with them across all repos." | PVT-DDR-001, PVT-DDR-002 |
| 2026-09-25 | `budget_usd` set to 165 (item 9); display sun hood and light grey case (item 12); 220 x 130 x 80 mm case (item 13); pitch and problem unchanged | Amish, same instruction | PVT-DDR-002 |
| 2026-09-26 | PVTrace chosen for the first batch of product renders | Amish | `docs/REVIEW.md`, 2026-09-26 session |
| 2026-10-01 | `budget_usd` is a value-engineering target, not a limit | Amish: "the budgets are a hypothethical control target to ensure we are thinking along a value engineering lens. its ok to ensure wording reflects that the hypothesis budget was x - the real cost being accrued is y" | `.kit/STANDARDS.md` section 18; this register |
| 2026-10-01 | Design changed so it can be built (PVT-DDR-003 C1 to C11), under Amish's 2026-09-30 instruction: "If you are realising that the design cannot be built as per concept - fix the design assumptions to match and be physically feasible as you draw the illustrations." Accepted on 2026-10-02 (below) | Made under Amish's instruction | PVT-DDR-003 |
| 2026-10-02 | Open item 1: design for construction accepted: C1 to C11 and their knock-on changes, as made | Amish: "i approve your recommendations for all 555 open decisions." | PVT-DDR-003, Tables 1 and 2 |
| 2026-10-02 | Open item 2: the sensor pod is read on the controller side of the isolation barrier through its own 16-bit ADC (about USD 3, as modelled) | Amish: "i approve your recommendations for all 555 open decisions." | PVT-DDR-003, A1 |
| 2026-10-02 | Open item 3: the R12 mass margin of about 14 g is accepted, and the prototype is weighed at TRL 4 | Amish: "i approve your recommendations for all 555 open decisions." | PVT-DDR-003, A2 |
| 2026-10-02 | Open item 4: R3 at worst-case tolerance: each capacitor is measured at build and a set is selected that gives at least 6.4 mF (restated as 6.45 mF on 2026-10-03, below); the 20 ms bound is relaxed later only if TOPCon and HJT capacitance data justify it | Amish: "i approve your recommendations for all 555 open decisions." | PVT-DDR-001 item 11; PVT-DDR-002 Table 2 |
| 2026-10-02 | Open item 5: first co-design partner, the first candidate type to approach (not yet agreed): a second-life panel refurbisher or recycler that tests used modules in volume, with a TVET solar course as a good second partner for the teaching use | Amish: "i approve your recommendations for all 555 open decisions." | PVT-DDR-001 item 10; PVT-DDR-002 Table 2 |
| 2026-10-02 | Open item 6: the case shape items of the appearance model are accepted (corner radii, corner boots, side grips, USB-C flap, labels, lead routing, pod fillets); the keypad and status LEDs are kept, and a BOM line is added for them | Amish: "i approve your recommendations for all 555 open decisions." | `docs/REVIEW.md`, 2026-09-26 session, items 1 to 4 |
| 2026-10-03 | Selected load capacitor bank of 6.45 mF or more (the 6.4 mF minimum of 2026-10-02 gives 19.9 ms on the high-current case against the 20 ms bound; 6.45 mF gives 20.05 ms), as recommended | Amish: "TIght Margins - i accept the margins" | PVT-DEC-001 item 4 of 2026-10-02; PVT-CAL-001 section 2; [REVIEW.md](REVIEW.md), session 2026-10-03 |

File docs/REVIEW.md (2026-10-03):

# Review note: PVTrace

## Session 2026-09-25: /populate to a strong TRL 2

### What was done

- `docs/01-problem.md` (PVT-PRB-001 v0.2): problem with cited evidence, users and context, prior work (IV Swinger 2, Cáceres et al. 2020, González et al. 2021, commercial tracers), constraints, out of scope, co-design checklist, open questions, safety.
- `docs/03-requirements.md` (PVT-REQ-001 v0.2): 17 measurable requirements (R1 to R17) with targets, verification and a concept status column, plus assumptions.
- `docs/02-concept.md` (PVT-PRC-001 v0.2): how it works, 13 numbered components, sweep time and energy table, resolution, discharge, battery, STC uncertainty, mass and cost estimates, draft fault and grading rules, proposed design choices, links to CellCheck and CalRig, safety, open questions.
- `cad/src/concept_media.py`: massing model of the handheld tracer (case, lid, controller and display, measurement board, capacitors, MOSFET bar, dump resistor, fuse, isolator, cell, MC4 leads, sensor pod). A grey 1,722 x 1,134 mm module on a 30° stand, with its own leads, is the context part for scale instead of the 1.75 m person, because the tracer is handheld.
- `media/`: hero, blueprint sheet (PNG, PDF, SVG), exploded view with callouts 1 to 12, cutaway, sweep flow diagram, `model.glb` and `viewer.html`. The script removes the temporary `_views` folders.
- `bom/bom.csv` (13 lines, indicative prices, numbered to match the exploded view) and `bom/bom-notes.md`.
- `README.md`: hero and links line; concept rationale, burning platform, industry and region tables and trigger expanded with cited sources; concept, key components and safety updated.
- `docs/pdf/`: branded PDFs of the three controlled documents.

### Key results (estimates, to be checked at TRL 3)

| Quantity | Estimate | Requirement |
| --- | --- | --- |
| Range | 0 to 100 V, 0 to 20 A | R1, R2 met by design |
| Sweep time, 4.4 mF load | about 13 ms (410 W high-current) to 43 ms (2 x 250 W in series) | **R3 not met** for high-current, lower-voltage modules |
| V-I pairs per sweep | about 325 to 1,070 | R4 met |
| Stored energy per sweep | 1.1 to 12.4 J typical; 22 J at the 100 V limit | |
| Discharge | below 30 V in about 0.12 s active; below 60 V in about 23 s passive | R11 met |
| STC Pmax uncertainty | about ±5 to 6 % | R8 at risk |
| Mass | about 1.35 kg | R12 met |
| Battery life | about 16 h | R14 met |
| Parts cost | about $149 | R17 met, margin about $1 |

Requirements not met or at risk:

- **R3 (sweep 20 ms or longer) not met** for high-current modules (about 13 ms). A third capacitor would fix it (item 3 below) but breaks the budget.
- **R13 sunlight readability not met** with a commodity TFT (unverified; the display type is item 5).
- **R16 insulation screening not met**; it is out of scope for this instrument, and second-life resale also needs an insulation test.
- **R8 at risk** until the reference cell calibration route (item 6) is chosen; R5 to R7 and R9 are unverified.

### Proposed at TRL 2

Items 1 to 9 and 11: Decided by Amish, 2026-09-25: go with recommendation (PVT-DDR-002). Item 10: still proposed, awaiting Amish.

1. **Load type.** Capacitive (recommended), electronic MOSFET load, or relay-switched resistor bank.
2. **Rating.** 100 V, 20 A (recommended; stays below the 120 V DC extra-low-voltage limit), 60 V, 15 A single-module only, or high-voltage strings (not recommended).
3. **Load capacitance.** 4.4 mF (baseline, fits budget, misses R3) or 6.6 mF (recommended, about +$6).
4. **Galvanic isolation** of the controller and USB from the PV side. Option A procedural lockout (baseline), option B digital isolator and isolated DC-DC (recommended, about +$8).
5. **Display.** 2.8 in TFT plus phone export (recommended), phone only, or transflective display (about +$10).
6. **Irradiance reference.** Reference cell calibrated once against a pyranometer (recommended), silicon pyranometer, or known-good module.
7. **Controller.** ESP32 display board (recommended) or RP2040 with a separate display.
8. **Grade thresholds.** A 90 % or more of nameplate, B 80 to 90 %, C 70 to 80 %, reject below 70 % or with a visible safety defect; to be agreed with a partner.
9. **Budget.** Items 3 and 4 together take parts to about $163. Proposed: raise `budget_usd` from 150 to 165. Decided by Amish, 2026-09-25: go with recommendation; `budget_usd` is now 165.
10. **First partner** for co-design: a second-life panel refurbisher or recycler, or a TVET solar course.
11. `pitch` and `problem` in `project.yaml` were left unchanged; the evidence supports them.

### Safety concerns

- Live DC at up to 100 V and 20 A from a source that cannot be switched off; sustained DC arcs if a connector is pulled under load. The design only opens the circuit near zero current and uses a DC-rated isolator and fuse.
- Up to 22 J stored in the load capacitors; active and passive discharge are both required.
- Without isolation (item 4), the controller ground is the PV negative, so a laptop on USB could be exposed to PV potential; option A relies on a firmware lockout.
- Li-ion cell inside a case that may sit in full sun.
- Mixed-brand MC4 connectors can overheat; heavy, sharp and possibly broken modules; rooftop work at height.

### Problems and notes

- The kit places the context part only in the hero, so the blueprint's orthographic views show the tracer with its leads and sensor pod and are small at the sheet scale; the isometric view shows the full scene.
- The cutaway excludes the leads and sensor pod so the section centers on the enclosure.
- The flow diagram's only numeric value is the energy per sweep for the reference module (5.4 J); the kit scales arrow widths from it, so the arrow after the capacitor is drawn wider.
- The legacy `cad/src/model.py` placeholder is untouched (TRL 3 work).
- The EU WEEE Directive text could not be fetched in this session. Its coverage of PV panels is cited from the EUR-Lex entry but was not re-read; check it at TRL 3. The Jordan and Kurtz figure was confirmed from the NREL research hub record.
- The web search budget ran out partway through research, so the Pakistan and Kenya used-panel markets were not added to the region table.

### Recommended next step

Review this note and the media, then decide items 2 to 4, 6 and 9. If approved, run `/advance-trl3` to check the sweep model with cell capacitance, the discharge and thermal loads, the error budget and the grading rules by calculation, and to produce the parametric model and drawing sheet.

## Session 2026-09-25: TRL 3

### What was done

- `docs/decisions/0001-trl2-review-decisions.md` (PVT-DDR-001 v0.1): items 1 to 8 of the TRL 2 review were adopted for TRL 3 pending Amish's review; items 9 to 13 stayed open. (Since then Decided by Amish, 2026-09-25: go with recommendation for items 1 to 9, 12 and 13; see PVT-DDR-002.)
- `docs/04-calcs/01-sizing.md` (PVT-CAL-001 v0.1) with `docs/04-calcs/sizing.py` and `docs/04-calcs/results.csv`: single-diode sweep model with loop resistance and capacitor tolerance, range and cold Voc, resolution and error budget, STC uncertainty, discharge and opening current, heat in sun, battery, mass and cost. The script reads `cad/src/model.py` and `bom/bom.csv`.
- `cad/src/model.py`: parametric build123d model (case, lid and window, controller, measurement board, isolation board, three capacitors, MOSFET bar, dump resistor, fuse, isolator, battery, lead stubs, sensor pod) with an interference check (no clashes). Exports `cad/step/` and `cad/stl/` for the assembly, the enclosure and the sensor pod.
- `cad/src/sheets.py` and `cad/drawings/PVT-DWG-001` (SVG, PDF, PNG): general arrangement at Rev P1, marked "CONCEPT, NOT FOR FABRICATION" and "PRELIMINARY, NOT FOR FABRICATION". The concept blueprint keeps PVT-DWG-010, so DWG-001 was free.
- `bom/bom.csv`: 14 lines, all priced with supplier types; third capacitor, new line 14 (isolation barrier), light grey case, charger with temperature cut-off. `bom/bom-notes.md` updated.
- `cad/src/concept_media.py` now builds from `model.py`; all media refreshed (hero, blueprint Rev P2, exploded with callouts 1 to 12 and 14, cutaway, flow at 7.9 J, `model.glb`, `viewer.html`). No `_views` folders remain.
- PVT-PRB-001, PVT-PRC-001 and PVT-REQ-001 at v0.3; `README.md` and `project.yaml` (trl 3, trl_target 3, evidence list) updated. PDFs in `docs/pdf/`.

### Requirements (PVT-CAL-001)

Nine met, four not met, two at risk, two not verifiable at TRL 3.

| ID | Status | Value |
| --- | --- | --- |
| R3 | **Not met** (worst-case tolerance) | High-current module 20.5 ms at 6.6 mF nominal, 16.4 ms at -20 % |
| R13 | **Not met** (display readability); heat at risk | About 56 °C inside a light case, 73 °C dark, at 45 °C in sun |
| R16 | **Not met** (out of scope) | No insulation test |
| R17 | **Not met** at $150 | $163; met at the proposed $165 |
| R7, R8 | At risk | STC ±3.7 to ±5.4 %; needs a reference cell within ±4.5 % |
| R6, R9 | Not verifiable at TRL 3 | Instrument noise 0.08 %; about 7 or more samples per volt |
| R1, R2, R4, R5, R10, R11, R12, R14, R15 | Met (R1, R2, R10, R15 by design review; R5 on paper) | 410 pairs minimum; 0.21 s to 30 V, 40 s passive to 60 V; 1.41 kg; 10.3 h |

Corrections to TRL 2 figures: stored energy at 100 V is now 33 J (6.6 mF); battery life is 10.3 h, not 16 h, with the isolated side and boost counted; mass 1.41 kg, not 1.35 kg; the case grows to 220 x 130 x 80 mm; the module still delivers up to 2.5 A at 99 % of Voc, so the load switch must stay closed up to 6 ms longer to open below 0.5 A. The 4.4 mF sweep times from TRL 2 were reproduced within 2 ms.

### Decisions recorded

Decided by Amish, 2026-09-25: go with recommendation (was adopted for TRL 3 pending his review): capacitive load; 100 V, 20 A rating; 6.6 mF; isolation option B; 2.8 in TFT plus phone export; once-calibrated reference cell; ESP32 controller; grade thresholds A 90 %, B 80 %, C 70 %. Pitch and problem are unchanged, as the TRL 2 review recommended.

### Still awaiting Amish (as of the TRL 3 session)

- Budget: $165 recommended (PVT-DDR-001 item 9). Decided by Amish, 2026-09-25: go with recommendation; `budget_usd` now 165.
- First co-design partner: no preference stated (item 10). Still proposed, awaiting Amish.
- R3 at tolerance: fourth capacitor, capacitor selection, or relaxing the bound (item 11, no recommendation yet). Still proposed, awaiting Amish.
- Heat and sun: sun hood for the display (item 12). Decided by Amish, 2026-09-25: go with recommendation; hood added.
- Larger case, 220 x 130 x 80 mm (item 13). Decided by Amish, 2026-09-25: go with recommendation.

### Safety concerns

- 33 J stored at 100 V; both discharge paths are required, and the switch must not open a loaded DC circuit (hold until below 0.5 A).
- Inside temperature in sun can pass the Li-ion charging limit; charge only in shade with the isolator open; keep the temperature cut-off.
- Two 450 W modules in series reach about 109 V when cold; the 100 V check must refuse them and the manual must say so.
- The isolation barrier's working voltage and test rating must be confirmed from datasheets before any build.
- Unchanged from TRL 2: live DC that cannot be switched off, DC arcs, mixed MC4 brands, heavy and broken modules, work at height.

### Problems and notes

- Citations: the EU WEEE coverage of PV panels was verified with WebFetch against the directive text (Article 5(1), Annex I and II category 4) and the link updated. The 20 ms lower bound in R3 and the capacitance of TOPCon and HJT modules could not be checked (WebSearch exhausted), so R3's bound stays a working figure.
- CalRig covers the temperature probe only from 10 to 40 °C; PVTrace modules run at 60 °C or more. This is a range limit, not an interface conflict; CalRig was not edited.
- The kit's cutaway still cuts near the origin; the model is centered on the case, so the section passes through the capacitors. The leads and sensor pod stay excluded from the cutaway.
- The kit's concept sheet shows only the current revision row, so the blueprint shows Rev P2 without its P1 row.
- No TRL 4 material exists in the repo; none was created.

### Recommended next step

TRL 4 is on hold by Amish's instruction. Review PVT-DDR-001 and decide items 9 to 13, especially the budget and the R3 option. For the record only, TRL 4 would need a bench prototype, a lab test report (TST, `environment: lab`) covering sweep time against a known module, discharge, accuracy against a calibrated meter and isolation, and build log entries.

## Session 2026-09-25: recommendations accepted

### Decisions applied

Amish wrote on 2026-09-25: "i accept all your recommendations, go with them across all repos." Twelve PVTrace items are now "Decided by Amish, 2026-09-25: go with recommendation", recorded in `docs/decisions/0002-recommendations-accepted.md` (PVT-DDR-002 v0.1), with statuses updated in PVT-DDR-001 v0.2:

- Items 1 to 8 (capacitive load; 100 V, 20 A; 6.6 mF; isolation option B; TFT plus phone export; once-calibrated reference cell; ESP32; grade thresholds A 90 %, B 80 %, C 70 %) and item 13 (220 x 130 x 80 mm case): already in the design; status wording only.
- Item 9, budget: `budget_usd` in `project.yaml` from **150 to 165**. R17 from not met ($163 against $150) to **met** ($164 against $165, $1 margin).
- Item 12, heat and sun: printed PETG display sun hood added as `bom/bom.csv` line 15 ($1.00). Parts **$163 to $164**; mass **1.41 to 1.43 kg** (R12 still met); hood top at 98 mm, level with the isolator knob, so the envelope is unchanged. Model (`cad/src/model.py`, no clashes), STEP and STL, PVT-DWG-001 **Rev P1 to P2**, concept media (callout 15, blueprint PVT-DWG-010 Rev P3) and PVT-CAL-001 **v0.1 to v0.2** updated.
- TRL 2 note item 11: `pitch` and `problem` unchanged, as recommended.

Documents bumped: PVT-PRB-001 v0.4, PVT-PRC-001 v0.4, PVT-REQ-001 v0.4, PVT-CAL-001 v0.2, PVT-DDR-001 v0.2. README: budget line, concept paragraph, not-met list, and a rewritten "What sparked the idea" (the March 2024 Fighting Jays hailstorm in Fort Bend County, Texas, cited). The old personal-site domain in generated files was replaced with designmolecule.com by re-rendering all PDFs, the drawing and the media.

### Requirement status (PVT-CAL-001 v0.2)

- **Not met (3):** R3 sweep time at -20 % capacitor tolerance (16.4 ms against 20 ms); R13 display readability in sun (sun hood fitted; readability can only be shown in a field check), heat at risk (about 56 °C inside at 45 °C in sun); R16 insulation screening (out of scope).
- **At risk (2):** R7, R8 (reference cell calibration within ±4.5 %).
- **Not verifiable at TRL 3 (2):** R6, R9.
- **Met (10):** R1, R2, R4, R5, R10, R11, R12 (1.43 kg), R14 (10.3 h), R15, R17 ($164 of $165).

### Still awaiting Amish

- Item 10, first co-design partner: no preference stated.
- Item 11, R3 at worst-case tolerance: fourth capacitor (about +$6, which would break the $165 budget), capacitor selection, or relaxing the 20 ms bound. No recommendation was made.

### Cross-repo actions

None for PVTrace. The CalRig temperature range limit (10 to 40 °C) remains a note, not a requested change.

### TRL 4

TRL 4 remains on hold by Amish's instruction. `trl: 3` and `trl_target: 3` are unchanged. The reference cell calibration and the display readability field check follow from the decisions but are TRL 4 work and were not started.

## Session 2026-09-26: sources strengthened

- "What sparked the idea" (README): replaced the trade-press source Renewable Energy World (2024) with *Newsweek* (2024), which reports the March 15, 2024 hailstorm, the 350 MW Fighting Jays farm near Needville in Fort Bend County and the thousands of damaged panels. The VDE Americas (2025) analysis stays as the second source. The inspiration event is unchanged.
- No other weak sources were flagged; all region rows already carry citations. `docs/01-problem.md` did not cite the replaced source, so no controlled document changed.

## Session 2026-09-26: product appearance model and photoreal renders

Amish chose this repo for the first batch of product renders on 2026-09-26.

### What was done

- New `cad/src/product_model.py`: `product_parts()` returns 68 appearance parts (30 shell, 25 internal, 4 accessory, 9 context) with colour, material, BOM line, group and explode offset, plus `TITLE` and three `RENDER_VIEWS` (hero, exploded, in-use). It imports `PARAMS` and `build_parts()` from `cad/src/model.py`; `model.py` has no `derived()` function, so its envelopes are used directly. Every shape is valid and tessellates.
- Appearance detail added: filleted case and lid with a parting-line groove at Z 52; wrap-around rubber corner boots; ribbed rubber side grips; fluted M16 and M12 cable glands; a clear polycarbonate display window over a lit 2.8 in screen showing an IV curve, a power curve, a grade tile and the maximum power point; the printed sun hood with softened edges; a membrane keypad with a teal sweep key, two menu keys and green and amber status LEDs; lid screws; a raised "PVTrace" mark and a yellow "100 V DC" warning label; the DC isolator with base ring, ON/OFF ticks, grey knob and red handle; red and black PV test leads swept to the floor and ending in MC4 connectors; a USB-C port flap.
- Internals for the exploded view: controller board and display module, measurement board with shunt, isolation board, MOSFETs on an aluminium bar with fins, aluminium-clad discharge resistor, fuse holder with a 10 x 38 fuse, three blue capacitors with end discs, 18650 cell in its holder, isolator body. The sensor pod (item 12) is an accessory beside the case.
- Context for the "in-use" view only: the shared clay forearm and hand (grip pose) carrying the tracer by its -X end, fingers under the case floor and thumb round the front corner, beside a small framed 12-cell PV module lying face up; the module's own leads end in MC4 connectors mated to the tracer's leads. The hero view shows the tracer and its leads without context.
- README: hero image now points to `media/render-hero.png`, with an "Exploded render" link added; the orchestrator produces the render files.

### Differences from model.py (Proposed, awaiting Amish)

1. **Plan corner radius.** `model.py` has a square case; the appearance model rounds the vertical edges to R10 and adds top and bottom fillets. Recommendation: accept; real IP54 handheld cases have radiused corners and the main dimensions are unchanged.
2. **Corner bumpers.** `model.py` has 14 mm square bumpers centred on each vertical edge, 40 mm high. The appearance model uses wrap-around boots that stand the same 7 mm proud and reach 24 mm along each face. Recommendation: accept as the look to aim for when a case is chosen.
3. **Additions not in model.py:** keypad and status LEDs, side grips, USB-C flap, labels and the lead routing to the floor (model.py shows 60 mm straight stubs). Recommendation: accept as appearance only; the keypad and LEDs would need a line in the BOM (item 13 or a new line) if they survive to TRL 4.
4. **Sensor pod shape.** The pod keeps the `model.py` envelope, reference cell and clip size, with fillets and a slot in the clip. Recommendation: accept.

### Status

This is an appearance model only: no tolerances, no fabrication detail, nothing past TRL 3. `trl: 3` is unchanged, and TRL 4 remains on hold by Amish's instruction.
- The `in-use` view (clay hand carrying the tracer beside a module) is defined in RENDER_VIEWS but not published: the hand pose read poorly in the render. To revisit with a better carrying pose.

## Session 2026-09-27: kit 1.5.0 and image quality

- Kit 1.5.0 synced: STANDARDS v1.5 (sections 12 to 15: product renders, storefront images and image quality, public release, authorship and signing), `.kit/cards.py`, `.kit/image_qc.py`, `.kit/release_gate.py`, issue templates, and the `/render-product` and `/release` commands. `CLAUDE.md` now matches `.kit/CLAUDE.md`.
- Every `media/render-*.png` recaptioned from its original render with the new layout: the title, concept label and repository sit in a band above the render and the view note in a band below it, each line wrapped to the image width, so no text overlaps other text or the render or runs off the image. `media/card.png` and `media/social-preview.png` regenerated with the same rules.
- `python .kit/image_qc.py` and `python .kit/release_gate.py` pass. trl stays 3.

## Session 2026-10-01: design for construction and prototype build plan (kit 1.7.0)

### What was done

- Kit 1.7.0 installed (`.kit/`, `.claude/commands/`); `CLAUDE.md` now matches `.kit/CLAUDE.md`.
- Constructability review of every part with build123d checks, and the design made buildable under Amish's 2026-09-30 instruction ("If you are realising that the design cannot be built as per concept - fix the design assumptions to match and be physically feasible as you draw the illustrations."). Recorded in `docs/decisions/0003-design-for-construction.md` (PVT-DDR-003 v0.1, Draft, open for Amish's review).
- `cad/src/model.py` rewritten as the constructable design: `build_components()` and `build_pod()` give every part and fixing; `python cad/src/model.py --check` runs 183 checks (overlaps, contacts, clearances, screwdriver access, lid lift-off, R12 envelope); all pass. `build_parts()` is kept for `concept_media.py` and `product_model.py`. STEP (assembly, enclosure, sensor pod, chassis plate) and STL regenerated.
- `bom/bom.csv`: lines 1 to 4, 12, 13 and 15 respecified; new lines 16 (chassis plate) and 17 (USB-C socket). `bom/bom-notes.md` updated.
- `docs/04-calcs/sizing.py` and PVT-CAL-001 v0.3: mass 1.49 kg, cost USD 178; R17 reported against the value-engineering target. PVT-REQ-001 v0.5 and PVT-PRC-001 v0.5 updated to match.
- `cad/drawings/PVT-DWG-001` Rev P3 (general arrangement); new making sketches PVT-DWG-101 to 108 (body, chassis plate, MOSFET bar, lid, window, sun hood, pod housing, pod clip). Concept media regenerated (blueprint PVT-DWG-010 Rev P4, exploded view with callouts 16 and 17).
- `cad/src/build_plan_media.py`: overview, 8 making sketches, 3 hole layouts (case, plate, lid), 8 joint close-ups, 12 step pictures and the block wiring diagram, all drawn from the model.
- `docs/05-build-plan.md` (PVT-BLD-001 v0.1) and `docs/06-design-decisions.md` (PVT-DEC-001 v0.1) written; `project.yaml` has `design_state: constructable` and both in `trl_evidence`; README links line, cost wording and a "Building the prototype" section.

### Design changes made for construction (PVT-DDR-003)

1. C1. Gland holes and inside locknuts; lead glands 18 mm (was 20) each side of centre, sensor gland 45 mm (was 35) toward the back, so the locknuts clear the fuse holder.
2. C2. Window 72 x 54 mm bonded on top of the lid over a 62 x 46 mm opening (it floated in a same-size opening).
3. C3. Sun hood given four inside screw tabs, widened to 92 mm outside, with screwdriver holes in the roof lip (it had no fixing).
4. C4. Display board modelled at its real 86 x 50 mm and hung on four 7 mm spacers on the hood screws.
5. C5. Polycarbonate chassis plate, 1.5 mm, on five standoffs; every internal part screwed to it; boards on 6 mm standoffs.
6. C6. Bought case's corner pillars added; capacitor bank moved clear of them; plate corners notched; fuse holder specified at 44 mm long and moved 2.5 mm forward.
7. C7. Capacitors held by a silicone bed and two cable ties through plate slots.
8. C8. MOSFET bar drilled and tapped, MOSFETs on insulating pads; isolator given its maker's flange and screws; two screws for each holder.
9. C9. Measurement board turned 90 degrees and moved to clear the gland nuts, MOSFET bar and isolator.
10. C10. IP65 USB-C charging socket added in the left end (R14 had no port through the case).
11. C11. Sensor pod given a C-clip with an M6 thumb screw, heat-set inserts and an M12 gland; the reference cell read by a 16-bit ADC on the controller side.

### Key results

- Requirements: R12 met at 1.49 kg (about 14 g to spare). R17: value-engineering target USD 165, estimated cost USD 178 (USD 13 over the target). Not met as before: R3 at worst-case tolerance, R13 display readability, R16 out of scope. At risk: R7, R8. Not verifiable at TRL 3: R6, R9. Sweep, discharge, heat and battery results unchanged.

### Proposed, awaiting Amish (see PVT-DEC-001)

- Accept the design-for-construction changes C1 to C11 (recommended).
- Sensor pod on the controller side through its own ADC (recommended) or on the PV side (PVT-DDR-003 A1).
- Accept the 14 g mass margin and weigh at TRL 4 (recommended) (A2).
- Still open from earlier: R3 at tolerance (no recommendation), first co-design partner, the appearance model differences of 2026-09-26.

### Stale on Amish's Mac

The design changed visibly (wider sun hood with tabs, smaller window, USB-C socket on the left end, glands moved, chassis plate and new internal layout, pod clip). These are now stale and are made on Amish's Mac: `media/render-*.png`, `media/card.png`, `media/social-preview.png`, and the appearance model `cad/src/product_model.py` (it still draws the concept internals and the narrower hood, although it imports the new `PARAMS`).

### Safety concerns

- Unchanged: live DC to 100 V and 20 A that cannot be switched off, 33 J in the capacitors, a Li-ion cell in a case that can pass 45 °C inside in sun.
- New from this work: the MOSFET tabs are live and sit on an aluminium bar, so the insulating pads and bushings are safety parts (checked at stop S2); the discharge resistor now sits on a plastic plate, so its free-air rating must be confirmed (register item to confirm 4); the sensor pod must stay on the controller side (A1). The build plan has eight safety stops, with the first live connection on a small module only after bench checks.

### Recommended next step

Review PVT-DDR-003 and the design decisions register, decide open decisions 1 to 3, then update the renders on the Mac. TRL 4 (building to this plan) stays on hold until Amish says otherwise.

## Session 2026-10-02 (later): approved follow-ups carried out

Amish approved on 2026-10-02 that every follow-up action from the open-decision sign-off be carried out. Of the 6 follow-ups listed in the section below, 5 are done and 1 is not done (reason given).

### Approved follow-ups carried out

1. Decision 4, rerun the R3 calculation: done. `docs/04-calcs/sizing.py` now calculates the selected bank; `results.csv`, PVT-CAL-001, PVT-REQ-001 and the README are updated. R3 changes from not met to met on paper (20.1 ms high-current case at 6.45 mF), and R4 is 501 pairs.
2. Decision 4, spare capacitors: done. BOM line 5 buys four 2200 µF capacitors (one spare, USD 6, basis: the existing USD 6 unit price) and fits the best three. Three parts need an average of 2150 µF each, 2.3 % below rated, so one spare gives a reasonable choice; buy more from the same batch if no three reach 6.45 mF.
3. Decision 6, BOM line for the keypad and status LEDs: done. New line 18, USD 8, with the price basis in the notes column and in `bom/bom-notes.md`. The total is USD 192.
4. Decision 6, keypad and status LEDs in the model and drawings: done. `cad/src/model.py` has the keypad (bonded on the lid, tail through a 12 x 1.6 mm slot), two LEDs in 5.4 mm lid holes with clips and nuts, and 23 new constructability checks (206 of 206 pass). STEP and STL regenerated. Redrawn: PVT-DWG-001 Rev P4, the lid making sketch PVT-DWG-104, the lid hole layout, the overview (19 components), step 9, steps 10 and 11, and the wiring diagram. `docs/05-build-plan.md` v0.3 has the slot and holes in section 3.5, wiring item 11 and the bought-parts list.
5. Decision 6, appearance model: done. `cad/src/product_model.py` now stands the boards on the 1.5 mm chassis plate (plate and standoffs added), hangs the display board at its constructable height and takes the keypad and LED positions from the model; the wider hood already came from the model. Render scenes exported (below); the photoreal renders, card and social preview are made on Amish's Mac next.
6. Decision 3, weigh the prototype at TRL 4 against R12: not done, because TRL 4 is on hold by Amish's instruction.

### Key results

- Requirement status changes: R3 not met to met on paper with the selected bank; R4 value 410 to 501 pairs. R12 stays met but the margin falls from about 14 g to about 6 g (1,494 g) with the keypad and LEDs (8 g). No other change.
- Value-engineering target: USD 165. Estimated cost of the constructable design: USD 192 (USD 27 over the target); it was USD 178 (USD 13 over). The USD 14 rise is the keypad line (USD 8) and the spare capacitor (USD 6).
- Documents changed: PVT-CAL-001 v0.5, PVT-REQ-001 v0.7, PVT-PRC-001 v0.7, PVT-BLD-001 v0.3, PVT-DEC-001 v0.3, PVT-DDR-003 v0.3; `bom/bom.csv`, `bom/bom-notes.md`, `README.md`.
- Render scenes exported to `/home/claude/renders/pvtrace`: hero, exploded and in-use.

### Proposed, awaiting Amish

- Selected capacitor bank of 6.45 mF or more instead of 6.4 mF. At exactly 6.4 mF the high-current module sweeps in 19.9 ms, 0.1 ms short of the 20 ms bound; 6.44 mF is the break-even. Options: keep 6.4 mF and accept 19.9 ms (R3 then misses by 0.5 %), or use 6.45 mF (recommended; the same three capacitors, a slightly stricter selection).
- Mass margin is now about 6 g. If it matters, a thinner pod housing or shorter leads recover mass; otherwise weigh at TRL 4 as already decided.
- Appearance deviations from model.py: LED domes, key shapes and the screen artwork are drawn for realism and are not in the engineering model.

### Cross-repo actions

None for this repo.

### Not done

Item 6 above. TRL 4 remains on hold.

## Session 2026-10-02: open decisions decided

On 2026-10-02 Amish approved every recommendation written for the open decisions: "i approve your recommendations for all 555 open decisions." trl stays 3; nothing was built or tested.

### Decisions recorded

6 decisions recorded in the design decisions register (PVT-DEC-001, Decisions made, dated 2026-10-02): PVT-DDR-003 accepted as made (1); sensor pod read on the controller side through its own ADC (2); 14 g mass margin accepted, weighed at TRL 4 (3); capacitors measured and selected to at least 6.4 mF for R3 (4); first partner type (5), the first candidate to approach and not an agreed partner; case shape items accepted, keypad and status LEDs kept with a new BOM line (6).

### Documents changed

- `docs/06-design-decisions.md` (PVT-DEC-001 v0.2): all 6 open items moved to Decisions made; Open decisions now reads "None"; capacitor selection added to "To confirm when parts are bought" (item 9); keypad cost noted under Value engineering.
- `docs/decisions/0003-design-for-construction.md` (PVT-DDR-003 v0.2): status line and Table 3 record acceptance of Tables 1 and 2 and A1 and A2; status stays Draft.
- `docs/decisions/0002-recommendations-accepted.md` (PVT-DDR-002 v0.2): items 10 and 11 recorded as decided.
- `docs/decisions/0001-trl2-review-decisions.md` (PVT-DDR-001 v0.3): items 10 and 11 recorded as decided.
- `docs/01-problem.md` (PVT-PRB-001 v0.5): first partner type.
- `docs/02-concept.md` (PVT-PRC-001 v0.6): capacitor selection rule for R3, partner type, keypad and LEDs, pod side and mass margin.
- `docs/03-requirements.md` (PVT-REQ-001 v0.6): R3 and R12 status notes record the decisions; no status changed.
- `docs/04-calcs/01-sizing.md` (PVT-CAL-001 v0.4): R3 row notes the capacitor selection rule and section 7 the accepted mass margin; no number changed.
- `docs/05-build-plan.md` (PVT-BLD-001 v0.2): capacitor measurement and selection to at least 6.4 mF (section 3.11).
- `bom/bom-notes.md`: the fourth capacitor option replaced by capacitor selection; the keypad line noted as a follow-up.
- PDFs re-rendered with `python .kit/render.py`; superseded versions removed.

No CAD model, BOM quantity or price, or picture was changed. Requirement status is unchanged until the calculations are rerun: R3, R13 and R16 not met, R7 and R8 at risk, R6 and R9 not verifiable at TRL 3, nine met, R17 USD 13 over the value-engineering target.

### Follow-up actions to carry approved decisions into the design

1. Decision 4 (calcs): Rerun `docs/04-calcs/sizing.py` for R3 with a selected bank of at least 6.4 mF and update `results.csv`, the R3 status in PVT-CAL-001, PVT-REQ-001 and the README.
2. Decision 4 (bom): Decide whether BOM line 5 carries one or two spare capacitors for selection, and price them.
3. Decision 6 (bom): Add a BOM line for the keypad and status LEDs, with an estimated price, and update the cost in PVT-CAL-001 section 7 and the value-engineering figures.
4. Decision 6 (model): Add the keypad and status LEDs to `cad/src/model.py` (lid holes, wiring to the controller), regenerate the general arrangement, the lid making sketch and the build plan pictures and wiring list (sections 3.4.1 and 3.5).
5. Decision 6 (pictures): Update `cad/src/product_model.py` to the constructable design (internals, wider hood) with the accepted case shape items, and regenerate the photoreal renders, `media/card.png` and `media/social-preview.png` on Amish's Mac.
6. Decision 3 (docs): Weigh the prototype at TRL 4 against R12 (when TRL 4 is opened; on hold now).

### Points found in the review

- The constructable design has no usable input control: the display board's touch screen sits behind the bonded polycarbonate window (C2, C4), and no buttons are in the BOM. This affects open decision 6 and the build plan.
- The cost is USD 178 against the USD 165 value-engineering target (USD 13 over); the keypad in item 6 will add a little more.
- Renders still show the concept internals and the narrower hood.

### Safety

The sensor pod stays on the safe, low-voltage side of the isolation barrier. The keypad, once added, must also sit on the controller side. Capacitor selection does not change the discharge paths or the 33 J stored energy.

### Recommended next step

Add the keypad and status LEDs to the model and BOM, since without them the constructable design has no usable input control, then rerun R3 with the selection rule. TRL 4 remains on hold by Amish's instruction.

## 2026-10-02: photoreal renders redone on the constructable design

Rendered with Blender Cycles on Amish's Mac from the updated appearance model; captioned with `.kit/photo_caption.py`; `media/card.png` and `media/social-preview.png` regenerated with `.kit/cards.py`. Views: hero, exploded, in-use. image_qc passes. Appearance deviations are those logged above as proposed, awaiting Amish.

## 2026-10-03: decisions recorded

Amish decided on 2026-10-03: "TIght Margins - i accept the margins". For PVTrace the recommendation was a selected load capacitor bank of 6.45 mF or more, because 6.4 mF gives 19.9 ms against the 20 ms bound. The 6.45 mF minimum is recorded as decided; the BOM line, build plan, concept, requirements, README and calculation note no longer say 6.4 mF or "proposed", and `docs/04-calcs/sizing.py` was rerun (R3 20.1 ms, R4 501 pairs, unchanged).

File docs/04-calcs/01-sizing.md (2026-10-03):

---
doc_id: PVT-CAL-001
title: PVTrace sizing calculations
project: PVTrace
doc_type: Calculation note
version: "0.6"
status: Draft
date: '2026-10-03'
author: Amish Chadha
license: CERN-OHL-S-2.0
revisions:
- version: "0.1"
  date: '2026-09-25'
  author: Amish Chadha
  change: First TRL 3 sizing note (sweep model, range, resolution, error budget, STC uncertainty, discharge, heat, battery, mass, cost) for the 6.6 mF isolated design in PVT-DDR-001
- version: "0.2"
  date: '2026-09-25'
  author: Amish Chadha
  change: Recommendations accepted by Amish (DDR-002)
- version: "0.3"
  date: '2026-10-01'
  author: Amish Chadha
  change: Constructable design (PVT-DDR-003); mass and cost updated; R17 reported against the value-engineering target
- version: "0.4"
  date: '2026-10-02'
  author: Amish Chadha
  change: R3 row notes the capacitor selection rule and section 7 the accepted mass margin, decided on 2026-10-02 (PVT-DEC-001, items 3 and 4); no number changed
- version: "0.5"
  date: '2026-10-02'
  author: Amish Chadha
  change: "sizing.py rerun for the capacitor bank selected at build (6.45 mF; R3 and R4 met on paper), a spare capacitor and the keypad and status LEDs (BOM line 18): cost USD 192, USD 27 over the target; mass 1,494 g, margin about 6 g; results.csv regenerated"
- version: "0.6"
  date: '2026-10-03'
  author: Amish Chadha
  change: "Selected bank minimum of 6.45 mF recorded as decided by Amish on 2026-10-03; 'proposed' removed; sizing.py comment updated and rerun"
---

# PVTrace sizing calculations

On paper, PVTrace meets ten of its seventeen requirements (R1 to R5, R10, R11, R12, R14, R15); R3 is met with the capacitor bank selected at build (see section 2). R17 (cost) is reported against the value-engineering target and is USD 27 over it. Two are **not met**: R13 (display readability in sun, not shown even with the sun hood, with heat at risk) and R16 (insulation screening, out of scope). R7 and R8 are **at risk** because they rest on the reference cell calibration, and R6 and R9 cannot be verified until hardware exists.

Three TRL 2 figures change. With the third capacitor (6.6 mF, PVT-DDR-001 decision 3) the high-current module sweeps in 20.5 ms at nominal capacitance but only 16.4 ms at the -20 % tolerance of electrolytic capacitors, so R3 was not met in the worst case as first drawn; Amish's decision of 2026-10-02 to select the bank at build changes that (section 2). The stored energy at 100 V rises from 22 J to 33 J. Battery life falls from about 16 h to 10.3 h once the isolation barrier (decision 4) and a 5 V boost are counted; R14 is still met. The module current at 99 % of Voc is up to 2.5 A, so the load switch must stay closed a few milliseconds past the end of the sweep to open below 0.5 A (R11).

Version 0.2 applies Amish's decisions of 2026-09-25 (PVT-DDR-002): the budget in `project.yaml` rises from $150 to $165, and a printed display sun hood (BOM line 15, +$1, about 15 g) is added. The parts total goes from $163 to $164, so R17 changes from not met to met with a $1 margin. Mass goes from 1.41 kg to 1.43 kg (R12 still met); the hood top is level with the isolator knob at 98 mm, so the envelope does not change. No other result changes.

Version 0.3 follows the constructable design of PVT-DDR-003: a 1.5 mm polycarbonate chassis plate, a USB-C charging socket, a smaller bonded window, a wider sun hood with screw tabs, a 16-bit ADC for the reference cell and added fixings. Mass goes from 1.43 kg to 1.49 kg (R12 still met, about 14 g to spare) and the estimated cost from USD 164 to USD 178. Following Amish's instruction of 2026-10-01, `budget_usd` (USD 165) is treated as a value-engineering target, not a limit, so R17 is reported as USD 13 over the target. The sweep, discharge, heat and battery results do not change.

Every number here is printed by `docs/04-calcs/sizing.py` (run from the repo root: `python docs/04-calcs/sizing.py`), which also writes `docs/04-calcs/results.csv`. The script reads the case dimensions from `cad/src/model.py` and the costs from `bom/bom.csv`. All values are first-principles estimates for a paper design; nothing is measured.

## 1. Assumptions

Table 1. Inputs. All are assumptions for a paper design.

| Input | Value | Basis |
| --- | --- | --- |
| Module cases | 36-cell 100 W (22.0 V, 6.0 A); 108 half-cell 410 W (37.5 V, 13.9 A; MPP 31.4 V, 13.06 A); 144 half-cell 450 W reference (49.5 V, 11.6 A; MPP 41.5 V, 10.85 A); 2 x 60-cell 250 W in series (75.2 V, 8.9 A); rating limit, the reference curve scaled to 100 V and 20 A | Datasheet-class values, PVT-REQ-001 |
| Module model | Single-diode model, ideality 1.2 per cell, series and shunt resistance solved from Isc, Voc, MPP and zero dP/dV at MPP | Standard five-parameter fit |
| Load capacitance | 3 x 2200 µF 160 V = 6.6 mF, ±20 % | Decision 3, PVT-DDR-001; typical electrolytic tolerance |
| Loop resistance | 56.6 mΩ: leads 8.6, MC4 contacts 2.0, fuse 5.0, isolator 2.0, shunt 4.0, MOSFET 10.0, capacitor ESR 20.0, wiring 5.0 mΩ | Copper at 20 °C; typical part values |
| Sampling | 25,000 V-I pairs per second, voltage and current converted one after the other (20 µs apart) | Half the rate of a 100 kS/s two-channel ADC |
| Front end | 1 MΩ and 39 kΩ divider (0.1 %, 25 ppm/°C), 4 mΩ shunt (50 ppm/°C), gain 50, 4.096 V reference (50 ppm/°C), 12-bit ADC with ±1 LSB INL, 30 °C between calibration and use | Typical parts in `bom/bom.csv` line 4 |
| Voc temperature coefficient | -0.30 %/°C; coldest cell -10 °C | Typical crystalline silicon |
| STC terms | Pmax coefficient -0.35 %/°C; module temperature ±2 °C; spectral and angle mismatch ±2 %; reference cell ±3 to ±5 % | PVT-PRC-001; decision 6 |
| Discharge | 22 Ω active dump, 10 kΩ passive bleed; one sweep every 5 s at most | PVT-PRC-001 |
| Power | Controller and lit TFT 0.60 W; isolated side 0.25 W; 5 V boost 90 %; 3,000 mAh 18650 at 3.6 V, 90 % usable; 20 s of controller time per sweep | TRL 2 estimate plus isolation |
| Heat | 9 W/(m² K) from the case outside; 1,000 W/m² on the lid; solar absorptance 0.30 (light grey) or 0.90 (dark); 45 °C ambient | Still air, natural convection plus radiation |

## 2. Sweep (R3, R4)

Table 2 gives the sweep for each case. The sweep time is the time for the capacitor to rise from 0 V to 99 % of Voc, integrated as t = ∫ C dV / I(V) along the fitted curve, with the loop resistance and the bleed and divider currents included. It scales in proportion to the load capacitance.

Table 2. Sweep with 6.6 mF (single-diode model)

| Case | Sweep, nominal (ms) | Sweep, -20 % C (ms) | Sweep, 4.4 mF (ms) | V-I pairs, nominal | Energy stored (J) | First sample (V) | Samples per volt near Isc, -20 % C |
| --- | --- | --- | --- | --- | --- | --- | --- |
| 36-cell 100 W | 28.9 | 23.1 | 19.3 | 722 | 1.6 | 0.34 | 22.0 |
| 108 half-cell 410 W (high current) | 20.5 | 16.4 | 13.7 | 513 | 4.5 | 0.79 | 9.5 |
| 144 half-cell 450 W (reference) | 32.2 | 25.8 | 21.5 | 805 | 7.9 | 0.66 | 11.4 |
| 2 x 60-cell 250 W (high voltage) | 67.5 | 54.0 | 45.0 | 1,687 | 18.3 | 0.50 | 14.8 |
| Rating limit, 100 V, 20 A | 37.7 | 30.1 | 25.1 | 942 | 32.3 | 1.13 | 6.6 |

- **R3 with capacitors as bought is not met at worst-case tolerance.** The shortest sweep is 20.5 ms at nominal capacitance but 16.4 ms if the three capacitors are 20 % low. Holding 20 ms at -20 % would need 8.0 mF rated, which is a fourth capacitor. Amish decided on 2026-10-02 (PVT-DEC-001, item 4) not to add one but to measure each capacitor at build and fit the best three.
- **R3 with the selected bank.** The bank decided on 2026-10-02 was 6.4 mF or more. On the high-current case 6.4 mF gives 19.9 ms, 0.1 ms short, and 20 ms needs 6.44 mF, so Amish decided on 2026-10-03 that the minimum is **6.45 mF**, which the calculation uses. At 6.45 mF the high-current case sweeps in 20.05 ms, the shortest sweep of any case is 20.1 ms and the minimum is 501 V-I pairs, so **R3 and R4 are met on paper** with a bank selected to 6.45 mF or more. Three 2200 µF parts need an average of 2150 µF each, 2.3 % below rated, so BOM line 5 buys four and fits the best three (one spare). The longest sweep, the high-voltage case with +20 % capacitance, is about 81 ms, well inside 200 ms. The 4.4 mF column reproduces the TRL 2 estimates (13, 21 and 43 ms) within 2 ms, which checks the TRL 2 scaling.
- **R4 is met.** The fewest pairs are 410 (high-current case, -20 % capacitance), against 200.
- **Isc.** Loop resistance holds the module at 0.34 to 1.13 V at the first sample, 1 to 2 % of Voc, so firmware extrapolates Isc from the first samples. Pre-charging the bank negative is not needed.
- **Module capacitance.** With a capacitive load dV/dt = I / C_load, so the module's own capacitance C_mod causes a current error of about C_mod / C_load, independent of the sweep time. An error of 0.5 % or less needs C_mod of 26 µF or less at the lowest load capacitance. The capacitance of TOPCon and HJT modules at MPP is not verified in this note; the 20 ms bound in R3 remains a working figure until a source or a measurement confirms it.
- **Sample skew.** Converting V and I 20 µs apart gives up to 0.13 % error in Pmax at nominal capacitance (0.16 % at -20 %), in the high-current case. Firmware removes it by interpolating each voltage to the time of its current sample.

## 3. Range, resolution and accuracy (R1, R2, R5, R6)

**Range (R1, R2).** Cold-weather Voc at a -10 °C cell temperature is 24.3 V, 41.4 V, 54.7 V and 83.1 V for the four cases, all below 100 V. Two 450 W reference modules in series reach 99.0 V at STC and 109.4 V at -10 °C, so the 100 V check refuses them; the manual must say so. At 100 V the capacitors have a 1.60 times voltage margin and the MOSFETs 1.50 times. At 20 A the shunt dissipates 1.6 W against its 3 W rating, and the load MOSFET conducts 0.15 J per sweep. Both are met by design review.

**Resolution.** The divider gives a voltage full scale of 109.1 V (26.6 mV per count); the shunt and amplifier give 20.48 A full scale (5.00 mA per count).

**Accuracy (R5).** After a two-point calibration, drift over 30 °C leaves ±0.17 % of reading ±0.024 % of full scale on voltage and ±0.21 % of reading ±0.026 % of full scale on current, inside ±1 % ±0.1 %. The amplifier offset before calibration is worth 6.25 mA, so the zero must be calibrated. R5 is met on paper; it depends on calibration against a meter and on the component grades in `bom/bom.csv` line 4.

**Repeatability (R6).** Quantization at the reference MPP is 0.079 % of Pmax per sample and the instrument contributes ±0.27 % to Pmax, so the ±1 % target will be set by irradiance drift between sweeps. R6 cannot be verified at TRL 3.

## 4. Irradiance and STC uncertainty (R7, R8)

Table 3. STC Pmax uncertainty (root sum square)

| Term | Value |
| --- | --- |
| Reference cell calibration | ±3 to ±5 % |
| Spectral and angle mismatch | ±2 % |
| Module temperature, ±2 °C at -0.35 %/°C | ±0.7 % |
| Instrument, V and I | ±0.27 % |
| Total | ±3.7 to ±5.4 % |

R8 (±5 %) is met only if the reference cell calibration is within ±4.5 %; R7 (±5 % irradiance) needs ±4.6 %. Both are **at risk** until the once-calibrated reference cell (decision 6) shows its uncertainty. CalRig (reference ±0.2 °C from 10 to 40 °C) can check the temperature probe in that range but not at module operating temperatures of 60 °C and more, and not the reference cell.

## 5. Discharge and heat (R11, R13)

**Discharge (R11, met).** The active path has a 145 ms time constant (174 ms at +20 % capacitance): 100 V falls below 30 V in 0.21 s and below 1 V in 0.80 s, against 2 s. The passive bleed has a 66 s time constant (79 s at +20 %): 100 V falls below 60 V in 40 s, against 60 s. Peak dump power is 455 W and peak dump current 4.5 A for milliseconds; the bleed draws 10 mA (1.0 W) at 100 V, which firmware subtracts from the current reading. At 99 % of Voc the module still delivers up to 2.51 A (rating limit case), more than the 0.5 A at which R11 allows the circuit to open. Firmware must keep the load switch closed until the current falls below 0.5 A, at most 6 ms more with +20 % capacitance. With that rule R11 is met.

**Stored energy.** 33 J at 100 V (22 J with 4.4 mF). At one sweep every 5 s the dump resistor averages 1.6 W for the reference module and 6.6 W at the 100 V limit.

**Heat (R13, at risk).** The case has 0.113 m² of outside area and a 0.0286 m² lid, so it sheds 1.02 W/K. In full sun at 45 °C ambient:

Table 4. Inside temperature, lumped model

| Case color | Reference module, one sweep per 5 s | 100 V limit, one sweep per 5 s |
| --- | --- | --- |
| Light grey (absorptance 0.30) | 11.0 W, about 56 °C | 16.0 W, about 61 °C |
| Dark (absorptance 0.90) | 28.2 W, about 73 °C | 33.2 W, about 78 °C |

Solar gain on the lid dominates. Even a light case reaches about 56 °C inside, above the usual 45 °C charging limit of a Li-ion cell and close to the limits of commodity display boards. The design therefore needs a light-colored case, a charger with a temperature cut-off (added to `bom/bom.csv` line 10), and the advice to keep the tracer in shade between sweeps. A printed sun hood over the display is now fitted (PVT-DDR-002 item 12). It shades the window on three sides and from above; its small shading of the lid is ignored here, so the figures above stay conservative. Display readability in direct sun is still **not met** on paper: a hood improves contrast but readability of the adopted TFT (decision 5) can only be shown in a field check, which is TRL 4 work.

## 6. Battery (R14)

The controller and display draw 0.60 W and the isolated side 0.25 W at 5 V, or 0.94 W from the cell through the boost. A 3,000 mAh cell with 90 % usable (9.7 Wh) gives **10.3 h**, about 1,853 sweeps at 20 s each. R14 (8 h or 200 sweeps) is met. The TRL 2 figure of 16 h left out the isolation and the boost.

## 7. Mass, size and cost (R12, R17)

Table 5. Mass estimate

| Item | Mass (g) |
| --- | --- |
| Enclosure body and lid, ABS 3 mm, with bumpers and glands | 402 |
| Load capacitors, 3 x 75 g | 225 |
| Test leads, 2 x 1 m 4 mm² with MC4 | 162 |
| Sensor pod with 3 m cable | 150 |
| DC isolator | 120 |
| Battery, holder, charger | 72 |
| Hardware and consumables | 50 |
| Controller and display | 45 |
| Dump and bleed resistors | 45 |
| Measurement board; MOSFETs and bar; fuse and holder | 40 each |
| Isolation board | 10 |
| Display sun hood, PETG, with screws | 17 |
| Window, PC 72 x 54 x 3 mm, and gasket | 16 |
| Chassis plate, PC 1.5 mm (model volume 37.8 cm³) | 45 |
| USB-C charging socket with lead | 8 |
| **Total** | **1,486** |

The window was 10 g in v0.2, too low for 3 mm polycarbonate; it is now computed from the model (16 g).

R12 is met: 1.49 kg (1,494 g with the keypad and LEDs, 8 g) against 1.5 kg, with about 6 g to spare on estimated masses (was 14 g) (accepted by Amish on 2026-10-02, with the prototype weighed at TRL 4; PVT-DEC-001, item 3). Over the bumpers the case is 234 x 144 x 80 mm, 244 mm over the glands and 98 mm to the top of the isolator knob and sun hood, inside 250 x 150 x 100 mm.

The priced BOM totals **USD 192.00**. Value-engineering target: USD 165 (`budget_usd`, a hypothetical control target, not a limit). Estimated cost of the constructable design: USD 192, **USD 27 over the target**. Since v0.3 (USD 178) the total has risen by USD 14 for decisions of 2026-10-02: a spare load capacitor for selection (USD 6) and the keypad and status LEDs, BOM line 18 (USD 8: membrane keypad with printed overlay about USD 4.50, two LEDs with clips about USD 2, header and lead USD 1.50). The increase over v0.2 (USD 164) is the parts added to make the design buildable (PVT-DDR-003): the chassis plate (USD 3), the USB-C socket (USD 5), the pod ADC module (USD 3), the pod clip and gland (USD 1) and fixings (USD 2). Savings worth trying are listed in the design decisions register.

## 8. Results

Table 6. Requirement status (from `docs/04-calcs/results.csv`)

| ID | Value | Target | Status |
| --- | --- | --- | --- |
| R1 | 0 to 100 V; high-voltage case 83 V at -10 °C; capacitors 160 V, MOSFETs 150 V | 0 to 100 V, below 120 V | Met (design review) |
| R2 | 0 to 20.48 A full scale; shunt 1.6 W of 3 W at 20 A | 0 to 20 A | Met (design review) |
| R3 | 20.1 ms high-current case with the bank selected to 6.45 mF (19.9 ms at the decided 6.4 mF); 32 ms reference; up to 81 ms | 20 to 200 ms | Met on paper with a selected bank (PVT-DEC-001 item 4) |
| R4 | 501 pairs minimum (high-current case, selected bank 6.45 mF) | 200 or more | Met |
| R5 | V ±0.17 % ±0.024 % FS; I ±0.21 % ±0.026 % FS | ±1 % of reading ±0.1 % FS | Met on paper (needs calibration) |
| R6 | Instrument noise 0.08 % per sample | Pmax ±1 % over 3 sweeps | Not verifiable at TRL 3 |
| R7 | Irradiance ±3.6 to ±5.4 %; temperature ±2 °C budget | ±5 %, ±2 °C | At risk |
| R8 | ±3.7 to ±5.4 % (needs reference cell within ±4.5 %) | ±5 % or better | At risk |
| R9 | About 7 or more samples per volt; rules drafted | Flags within 5 s | Not verifiable at TRL 3 |
| R10 | A, B, C, reject thresholds decided (PVT-DDR-002); editable table | Partner-editable grades | Met (design review) |
| R11 | 30 V in 0.21 s; 60 V passive in 40 s; opens below 0.5 A after up to 6 ms more | 30 V in 2 s; 60 V in 60 s; open below 0.5 A | Met |
| R12 | 1.49 kg; 234 x 144 x 80 mm over bumpers | 1.5 kg; 250 x 150 x 100 mm | Met |
| R13 | Inside about 56 °C (light case) to 73 °C (dark) at 45 °C in sun; TFT with sun hood, readability unproven; IP54 case | 0 to 45 °C, sun, IP54, readable | **Not met** (display); at risk (heat) |
| R14 | 10.3 h, about 1,853 sweeps | 8 h or 200 sweeps | Met |
| R15 | CSV fields defined in PVT-PRC-001; no firmware at TRL 3 | CSV per sweep, USB or Wi-Fi export | Met (design review) |
| R16 | No insulation test in this instrument | Detect insulation faults | **Not met** (out of scope) |
| R17 | USD 192 in parts | Value-engineering target USD 165 | Over the target by USD 27 |

> **Safety:** These calculations cover a live DC instrument at up to 100 V and 20 A that stores up to 33 J. The discharge times assume both the active and passive paths are fitted and working; never rely on one alone, and treat the capacitors as charged until the display reads below 30 V. The heat results show the Li-ion cell can exceed its charging limit in sun; charge only in shade with the isolator open.

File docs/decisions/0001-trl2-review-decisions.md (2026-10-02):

---
doc_id: PVT-DDR-001
title: PVTrace TRL 2 review decisions
project: PVTrace
doc_type: Design decision record
version: "0.3"
status: Draft
date: '2026-10-02'
author: Amish Chadha
license: CERN-OHL-S-2.0
revisions:
- version: "0.1"
  date: '2026-09-25'
  author: Amish Chadha
  change: Record the TRL 2 review recommendations adopted for TRL 3 work under Amish's 2026-09-25 instruction, and the items that remain open
- version: "0.2"
  date: '2026-09-25'
  author: Amish Chadha
  change: Recommendations accepted by Amish (DDR-002)
- version: "0.3"
  date: '2026-10-02'
  author: Amish Chadha
  change: Items 10 and 11 decided by Amish on 2026-10-02 (PVT-DEC-001, items 5 and 4)
---

# 0001: TRL 2 review decisions

- **Date:** 2026-09-25
- **Status:** items 1 to 9, 12 and 13 decided by Amish on 2026-09-25 (go with recommendation; see PVT-DDR-002). Items 10 and 11, which had no recommendation here, were decided by Amish on 2026-10-02 as recommended in the design decisions register (PVT-DEC-001, items 5 and 4).

## Context

The TRL 2 review note (`docs/REVIEW.md`, session of 2026-09-25, /populate) listed eleven items as "Proposed, awaiting Amish", most with a recommendation. On 2026-09-25 Amish asked for this batch of repos to be taken through the usual process with the instruction "you know the drill, nothing gets past TRL 3". He has not reviewed the PVTrace items one by one. Under that instruction, every item with a recommendation is adopted as recommended for TRL 3 work and stays open for his review. Items with no recommendation, and the budget figure, stay open. TRL 4 is on hold by Amish's instruction. Later on 2026-09-25 Amish wrote "i accept all your recommendations, go with them across all repos"; the statuses below were updated in v0.2 and the changes are recorded in PVT-DDR-002.

## Options considered

The options for each item are in `docs/REVIEW.md` (2026-09-25, /populate) and PVT-PRC-001 v0.2. They are not repeated here.

## Decision

Table 1. Items adopted for TRL 3 work

| # | Item | Status | Where it now lives |
| --- | --- | --- | --- |
| 1 | Load type: capacitive load | Decided by Amish, 2026-09-25: go with recommendation | PVT-PRC-001 v0.3 |
| 2 | Rating: 100 V, 20 A, single modules and two in series, below the 120 V DC extra-low-voltage limit | Decided by Amish, 2026-09-25: go with recommendation | PVT-PRC-001 v0.3, PVT-REQ-001 R1, R2 |
| 3 | Load capacitance: 6.6 mF with three 2200 µF 160 V capacitors | Decided by Amish, 2026-09-25: go with recommendation | `bom/bom.csv` line 5, `cad/src/model.py`, PVT-CAL-001 |
| 4 | Isolation: option B, a digital isolator and isolated DC-DC converter between the measurement side and the controller | Decided by Amish, 2026-09-25: go with recommendation | `bom/bom.csv` line 14, `cad/src/model.py`, PVT-PRC-001 v0.3 |
| 5 | Display: 2.8 in TFT plus phone export | Decided by Amish, 2026-09-25: go with recommendation | PVT-PRC-001 v0.3; R13 readability stays not met |
| 6 | Irradiance reference: small reference cell calibrated once against a pyranometer | Decided by Amish, 2026-09-25: go with recommendation | PVT-PRC-001 v0.3, PVT-CAL-001 section 4 |
| 7 | Controller: ESP32 display board | Decided by Amish, 2026-09-25: go with recommendation | `bom/bom.csv` line 3 |
| 8 | Grade thresholds: A 90 % or more of nameplate, B 80 to 90 %, C 70 to 80 %, reject below 70 % or with a visible safety defect; editable by a partner | Decided by Amish, 2026-09-25: go with recommendation; the partner may still tune the table | PVT-PRC-001 v0.3, PVT-REQ-001 R10 |

The TRL 2 review recommended no change to `pitch` or `problem` in `project.yaml`, so neither changes.

### Items that remain open

Table 2. Items open at v0.1 and their status now

| # | Item | Status |
| --- | --- | --- |
| 9 | Budget: the TRL 2 review recommends raising `budget_usd` from $150 to $165 to cover items 3 and 4. The priced BOM is $163 | Decided by Amish, 2026-09-25: go with recommendation. `budget_usd` is now 165 in `project.yaml`; R17 is met ($164 with the sun hood, PVT-DDR-002) |
| 10 | First co-design partner: a second-life panel refurbisher or recycler, or a TVET solar course | **Decided by Amish, 2026-10-02:** first candidate type to approach (not yet agreed), a second-life panel refurbisher or recycler that tests used modules in volume, with a TVET solar course as a good second partner for the teaching use (PVT-DEC-001, item 5) |
| 11 | R3 at worst-case tolerance (16.4 ms at -20 % capacitance, PVT-CAL-001). Options: a fourth capacitor (8.8 mF, about +$6, case layout to be checked); select or measure capacitors so the bank is at least 6.4 mF; or relax the lower bound once the module capacitance of TOPCon and HJT cells is known | **Decided by Amish, 2026-10-02:** each capacitor is measured at build and a set is selected that gives at least 6.4 mF; the 20 ms bound is relaxed later only if TOPCon and HJT capacitance data justify it (PVT-DEC-001, item 4) |
| 12 | Heat in sun (R13): light grey case, charger with temperature cut-off and a display sun hood. The first two are in the TRL 3 BOM at no added cost; the hood is not | Decided by Amish, 2026-09-25: go with recommendation. Printed sun hood added (`bom/bom.csv` line 15, `cad/src/model.py`, PVT-DWG-001 Rev P2) |
| 13 | Case size grows to 220 x 130 x 80 mm to fit the third capacitor and the isolation board | Decided by Amish, 2026-09-25: go with recommendation. Already in the model; still inside R12 |

## Consequences

- The design now carries 6.6 mF and an isolation barrier; parts totaled $163 at v0.1, $13 over the $150 budget. Amish raised the budget to $165 on 2026-09-25 (PVT-DDR-002); with the sun hood the parts total $164 and R17 is met.
- The stored energy at 100 V rises to 33 J, and every safety note now uses that figure.
- R3 is met at nominal capacitance but not at -20 % tolerance, so it stays not met until item 11 is decided.
- Battery life falls to about 10 h with the isolated side powered, still above R14.
- The controller ground is no longer the PV negative, so a laptop on USB is not exposed to PV potential in normal use; the barrier's rating is a TRL 4 check.

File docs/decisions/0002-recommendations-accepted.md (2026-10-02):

---
doc_id: PVT-DDR-002
title: PVTrace recommendations accepted
project: PVTrace
doc_type: Design decision record
version: "0.2"
status: Draft
date: '2026-10-02'
author: Amish Chadha
license: CERN-OHL-S-2.0
revisions:
- version: "0.1"
  date: '2026-09-25'
  author: Amish Chadha
  change: Record Amish's acceptance of all recommendations and the changes made in the repo
- version: "0.2"
  date: '2026-10-02'
  author: Amish Chadha
  change: Items 10 and 11 decided by Amish on 2026-10-02 as recommended in PVT-DEC-001
---

# 0002: Recommendations accepted

- **Date:** 2026-09-25
- **Status:** accepted. Every item with a recommendation is decided by Amish, 2026-09-25: go with recommendation. Items 10 and 11, which had no recommendation, were given recommendations in the design decisions register (PVT-DEC-001, items 5 and 4) and decided by Amish on 2026-10-02: "i approve your recommendations for all 555 open decisions."

## Context

On 2026-09-25 Amish wrote: "i accept all your recommendations, go with them across all repos." This record lists every PVTrace item that the decision closes, what changed in the repo because of it, and what stays open. The items come from the TRL 2 review note (`docs/REVIEW.md`, /populate session) and PVT-DDR-001. Where a recommendation offered several options, the recommended option is the decision. TRL 4 remains on hold by Amish's instruction, so nothing here is built, bought or tested.

## Decision

Table 1. Items decided by Amish, 2026-09-25: go with recommendation

| # | Item | Decision | What changed in the repo |
| --- | --- | --- | --- |
| 1 | Load type | Capacitive load | Status wording only; already in PVT-PRC-001 |
| 2 | Rating | 100 V, 20 A, below the 120 V DC extra-low-voltage limit | Status wording only; R1, R2 unchanged |
| 3 | Load capacitance | 6.6 mF, three 2200 µF 160 V capacitors | Status wording only; already in `bom/bom.csv` line 5 and the model |
| 4 | Isolation | Option B: digital isolator and isolated DC-DC converter | Status wording only; already in `bom/bom.csv` line 14 and the model |
| 5 | Display | 2.8 in TFT plus phone export | Status wording only |
| 6 | Irradiance reference | Reference cell calibrated once against a pyranometer | Status wording only; the calibration itself is TRL 4 work, on hold |
| 7 | Controller | ESP32 display board | Status wording only |
| 8 | Grade thresholds | A 90 % or more of nameplate, B 80 to 90 %, C 70 to 80 %, reject below 70 % or with a visible safety defect, in a partner-editable table | R10 wording in PVT-REQ-001 v0.4 and PVT-CAL-001 v0.2 |
| 9 | Budget | Raise `budget_usd` from $150 to $165 | `project.yaml` budget_usd 150 to 165; README budget line; R17 in PVT-REQ-001 v0.4 changes from not met ($163 against $150) to met ($164 against $165, $1 margin); PVT-PRB-001 v0.4 constraint |
| TRL 2 note item 11 | `pitch` and `problem` | No change, as recommended | None |
| 12 | Heat and sun (R13) | Light grey case, charger with temperature cut-off and a display sun hood | New BOM line 15, printed PETG sun hood, 86 x 64 x 18 mm, $1.00; hood added to `cad/src/model.py` (no clashes; top at Z 98, level with the isolator knob, so the R12 envelope is unchanged); STEP and STL re-exported; PVT-DWG-001 Rev P1 to P2; concept media refreshed with callout 15; PVT-CAL-001 v0.2: parts $163 to $164, mass 1.41 kg to 1.43 kg. R13 display readability stays not met on paper until a field check (TRL 4, on hold) |
| 13 | Case size | 220 x 130 x 80 mm | Status wording only; already in the model and drawing |

### Items left open by this record

Table 2. Items left open by this record, both decided on 2026-10-02

| # | Item | Decision |
| --- | --- | --- |
| 10 | First co-design partner: a second-life panel refurbisher or recycler, or a TVET solar course | **Decided by Amish, 2026-10-02:** first candidate type to approach (not yet agreed), a second-life panel refurbisher or recycler that tests used modules in volume, with a TVET solar course as a good second partner for the teaching use (PVT-DEC-001, item 5) |
| 11 | R3 at worst-case capacitor tolerance (16.4 ms at -20 %): a fourth capacitor, selected capacitors of 6.4 mF or more, or relaxing the 20 ms bound | **Decided by Amish, 2026-10-02:** each capacitor is measured at build and a set is selected that gives at least 6.4 mF; the 20 ms bound is relaxed later only if TOPCon and HJT capacitance data justify it (PVT-DEC-001, item 4) |

### Cross-repo actions

None. CalRig's 10 to 40 °C range limit for the temperature probe (PVT-CAL-001 section 4) was a note, not a recommendation to change CalRig.

### On hold (TRL 4)

Reference cell calibration, the display readability field check, any purchase, build or bench test. These follow from the decisions above but are TRL 4 work and stay on hold by Amish's instruction.

## Consequences

- The budget is $165 and the priced BOM is $164, so R17 is met with a $1 margin. Any later addition, such as a fourth capacitor for item 11 (about +$6), would break it again.
- Requirements now stand at ten met, three not met (R3 at tolerance, R13 display readability, R16 out of scope), two at risk (R7, R8) and two not verifiable at TRL 3 (R6, R9).
- The sun hood adds about 15 g; mass is 1.43 kg against 1.5 kg (R12).
- `trl` and `trl_target` stay at 3.

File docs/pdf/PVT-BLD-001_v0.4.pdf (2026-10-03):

P V T R AC E · B U I L D P L A N

# PVTrace prototype build plan

Design Molecule Lab · designmolecule.com

D O C U M E N T CO N T RO L

Document ID | PVT-BLD-001 | Version | 0.4
Status | Draft | Date | 2026-10-03
Author | Amish Chadha | License | CERN-OHL-S-2.0
Project TRL | TRL 3 | Proof of concept
Repository | github.com/BoujeeEnjinia1701/pvtrace
Source | docs/05-build-plan.md @ uncommitted

R EV I S I O N H I STO RY
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

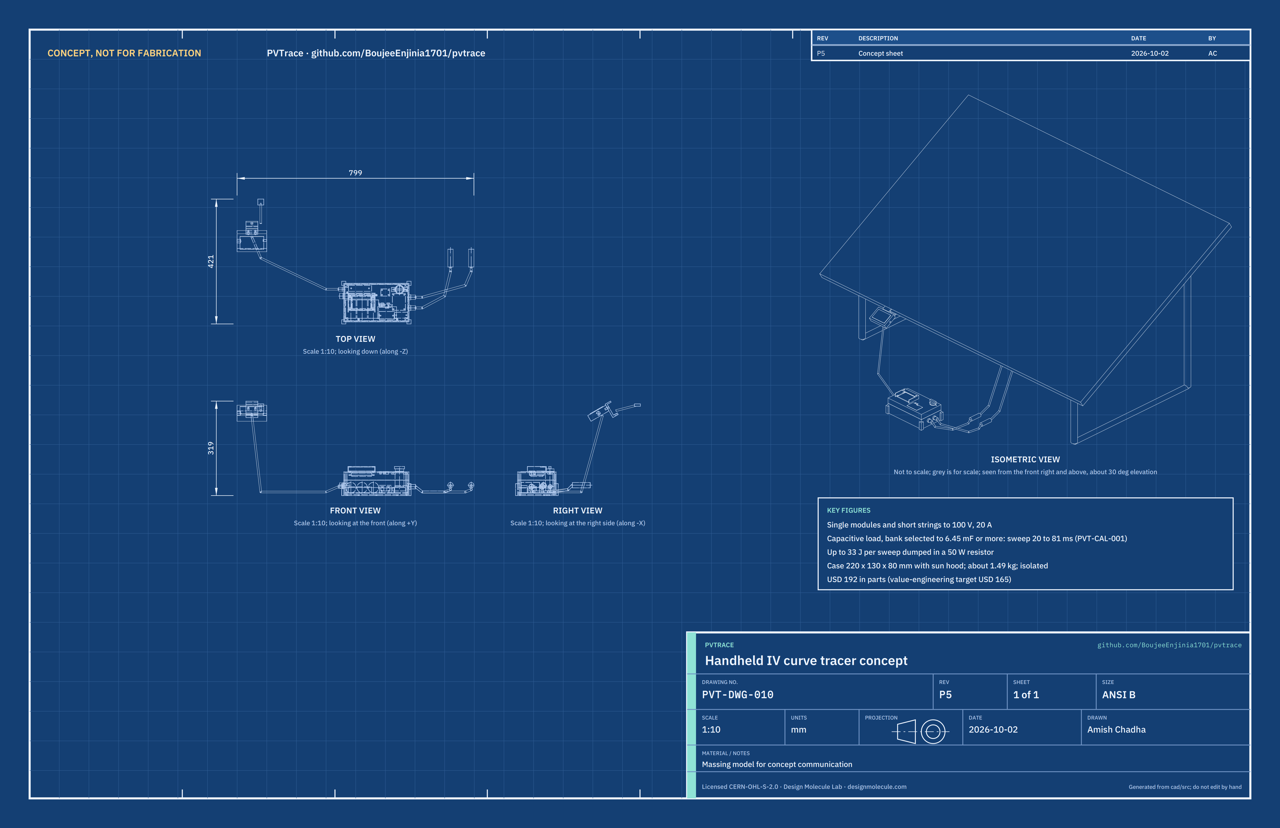
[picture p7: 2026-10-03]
media/concept-blueprint.png

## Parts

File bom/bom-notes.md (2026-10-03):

# BOM notes

- Line numbers match the callouts in `media/exploded.png` and Table 1 of `docs/02-concept.md`. Line 13 (hardware and consumables) is not modeled.
- Costs are indicative single-unit prices in USD from typical online and distributor listings in September 2026. They are estimates, not quotes. Supplier types are given for every line; named distributors are examples, not selections.
- Total: USD 192.00 (checked by `docs/04-calcs/sizing.py`). Value-engineering target: USD 165 (`budget_usd` in `project.yaml`, a hypothetical control target, not a limit; Amish, 2026-10-01). Estimated cost of the constructable design: USD 192, USD 27 over the target. Savings worth trying are in `docs/06-design-decisions.md`.
- Changes at TRL 3 (PVT-DDR-001): a third load capacitor on line 5 (+$6), the isolation barrier as new line 14 (+$8), a light grey case on line 1 and a charger with a temperature cut-off on line 10 at no added cost.
- Options that would change the total: a transflective display for R13 (about +$10). The fourth load capacitor for R3 is not used: Amish decided on 2026-10-02 (PVT-DEC-001, item 4) to measure the three capacitors at build and select a set of at least 6.4 mF; on 2026-10-03 Amish decided the minimum is 6.45 mF, so line 5 now buys four capacitors and fits the best three (one spare, USD 6; the spare is not modelled). 6.4 mF gives 19.9 ms, 0.1 ms short of the 20 ms bound, so the minimum of 6.45 mF is decided (Amish, 2026-10-03).
- Decided by Amish on 2026-10-02 (PVT-DEC-001, item 6): a keypad and status LEDs are kept from the appearance model. Line 18 (USD 8) covers a blank 3-key membrane switch (about USD 3.50), a printed overlay label (USD 1), two LED panel clips with LEDs (about USD 2) and a header and 6-way lead (USD 1.50); the lid slot and holes are in making sketch PVT-DWG-104. Prices are indicative distributor and online retailer listings, not quotes.
- Change from PVT-DDR-002: printed PETG display sun hood as new line 15 (+$1, material only), callout 15 in the exploded view.
- Brand-matched MC4 connectors are specified on purpose. Cheaper mixed-brand connectors can overheat when mated with a module's own connectors.
- The PV module, stand and module leads shown in grey in the media are not part of the kit.
- Changes from PVT-DDR-003 (design for construction, 2026-10-01): new line 16, the polycarbonate chassis plate (+$3); new line 17, the USB-C charging socket (+$5); line 3 adds a 16-bit ADC module for the reference cell (+$3); line 12 adds the pod clip's thumb screw and an M12 gland (+$1); line 13 adds standoffs, screws, ties and gasket tape (+$2); lines 1, 2, 4 and 15 respecified at no change in price. Lines 16 and 17 are callouts 16 and 17 in the exploded view.

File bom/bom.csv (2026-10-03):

item | qty | spec | supplier | unit_cost_usd | make_buy | notes
1 Enclosure body | 1 | IP54 ABS handheld case about 220 x 130 x 80 mm, light grey, with rubber corner bumpers and four moulded corner pillars for the lid screws; drilled for 2 x M16 test lead glands and 1 x M12 sensor gland (glands included), the USB-C socket (line 17) and five 3.4 mm floor holes for the chassis plate standoffs | Electronics distributor (Hammond or similar enclosure maker) | 12.00 | buy | Indicative price; lid supplied with case; light color for heat (PVT-CAL-001); holes per PVT-DDR-003 and drawing PVT-DWG-101
2 Enclosure lid window and gasket | 1 | 3 mm clear polycarbonate window, 72 x 54 mm, bonded on top of the lid with adhesive gasket tape over a 62 x 46 mm opening | Self (plastics stockist offcut) | 3.00 | make | Material cost only; size changed by PVT-DDR-003; drawing PVT-DWG-103
3 Controller and display board | 1 | ESP32 board 86 x 50 mm with 2.8 in 320 x 240 TFT and microSD socket (ESP32-2432S028 class), with 8 GB microSD card; hung under the lid on four M3 x 7 mm hex standoffs; plus a 16-bit I2C ADC module (ADS1115 class) for the reference cell, on the controller side | Online retailer (AliExpress or similar) | 21.00 | buy | Indicative price; decision 5 and 7 in PVT-DDR-001; fixing and pod ADC per PVT-DDR-003 (+$3)
4 Measurement board | 1 | 4 milliohm 3 W four-terminal shunt (50 ppm/°C), INA240A2-class current-sense amplifier, 1 Mohm and 39 kohm 0.1 % 25 ppm/°C divider, dual-channel 12-bit 100 kS/s SPI ADC (MCP3202 class), 4.096 V reference, protection diodes, perfboard 44 x 56 mm on four 6 mm nylon standoffs | Electronics distributor (Digi-Key, Mouser or similar) | 16.00 | buy | Indicative price; parts for hand wiring
5 Load capacitor | 4 | 2200 uF 160 V electrolytic, snap-in, about 35 x 60 mm, 105 °C | Electronics distributor (Digi-Key, Mouser or similar) | 6.00 | buy | Indicative price; four bought, three fitted: each is measured at build and the best three that give at least 6.45 mF together are fitted (PVT-DEC-001 item 4; one spare, USD 6; the spare is not modelled)
6 Load and discharge switches | 1 | 2 x 150 V N-channel MOSFETs (about 10 milliohm, TO-220), gate driver, aluminium bar | Electronics distributor (Digi-Key, Mouser or similar) | 9.00 | buy | Indicative price
7 Discharge resistors | 1 | 22 ohm 50 W aluminium-clad resistor plus 10 kohm 3 W passive bleed | Electronics distributor (Digi-Key, Mouser or similar) | 5.00 | buy | Indicative price
8 DC fuse and holder | 1 | 20 A gPV 10 x 38 mm fuse, 1,000 V DC, in a DC-rated holder | Solar or electrical wholesaler | 9.00 | buy | Indicative price
9 DC isolator | 1 | 2-pole rotary DC isolator, 20 A at 250 V DC or more | Solar or electrical wholesaler | 16.00 | buy | Indicative price; buy from a reputable brand
10 Battery and charger | 1 | Protected Li-ion 18650 cell about 3000 mAh, holder, USB-C charger with temperature cut-off, 5 V boost and protection board | Battery specialist or electronics distributor | 12.00 | buy | Indicative price
11 Test leads | 1 | 2 x 1 m, 4 mm2 double-insulated PV cable (red, black) with brand-matched MC4 connectors | Solar wholesaler | 16.00 | buy | Indicative price; mixed MC4 brands must not be used
12 Sensor pod | 1 | Encapsulated mono-Si reference cell about 80 x 50 mm with shunt, waterproof DS18B20 probe with foam shade, printed housing and C-clip with M6 thumb screw (PVT-DWG-106, 107), M12 cable gland, 3 m cable with connector | Online retailer and self (printed housing) | 16.00 | buy | Indicative price; calibration against a pyranometer per decision 6; clip and gland added by PVT-DDR-003 (+$1)
13 Hardware and consumables | 1 | Screws, standoffs, wire, heat-shrink, thermal pad, labels; five M3 x 5 mm nylon standoffs and M3 countersunk screws for the chassis plate; four M3 x 20 mm hood screws with sealing washers; two cable ties for the capacitor bank; neutral-cure silicone; insulating pads and bushings for the MOSFETs | Self (hardware store) | 8.00 | buy | Indicative price; fixings added by PVT-DDR-003 (+$2)
14 Isolation barrier | 1 | Digital isolator for SPI and gate control (4 channels, ISO7741 or ADuM1401 class) and 1 W isolated 5 V to 5 V DC-DC module, on a small perfboard | Electronics distributor (Digi-Key, Mouser or similar) | 8.00 | buy | Indicative price; decision 4 (option B) in PVT-DDR-001
15 Display sun hood | 1 | 3D-printed light grey PETG hood over the display window: three walls, a 20 mm roof lip and four inside screw tabs, 92 x 64 x 18 mm, about 15 g, held by the 4 M3 display screws (line 13) | Self (printed) | 1.00 | make | Material cost only; decision 12 in PVT-DDR-002; tabs and width per PVT-DDR-003; drawing PVT-DWG-104
16 Chassis plate | 1 | 1.5 mm polycarbonate sheet cut to 212 x 122 mm with corner notches, two pairs of cable tie slots and screw holes; carries every part in the case body | Self (plastics stockist offcut) | 3.00 | make | Material cost only; added by PVT-DDR-003; drawing PVT-DWG-102
17 USB-C charging socket | 1 | Panel-mount USB-C socket, IP65 or better with tethered cap, M16 thread with locknut, 0.3 m lead to the charger (controller side of the isolation barrier) | Electronics distributor or online retailer | 5.00 | buy | Indicative price; added by PVT-DDR-003 for USB-C charging with the case closed (R14)
18 Keypad and status LEDs | 1 | 3-key membrane keypad 64 x 40 mm (sweep key and two menu keys) with a flat tail and self-adhesive back, bonded on the lid; two 3 mm LEDs (green ready, amber live DC) in 5.4 mm panel clips; 6-way lead to a header on the display board (controller side of the isolation barrier) | Electronics distributor and online retailer | 8.00 | buy | Indicative price: blank 3-key membrane switch about USD 3.50 plus printed overlay label USD 1, two LED clips with LEDs about USD 2, header and lead USD 1.50; decided 2026-10-02 (PVT-DEC-001 item 6); lid slot and holes in making sketch PVT-DWG-104

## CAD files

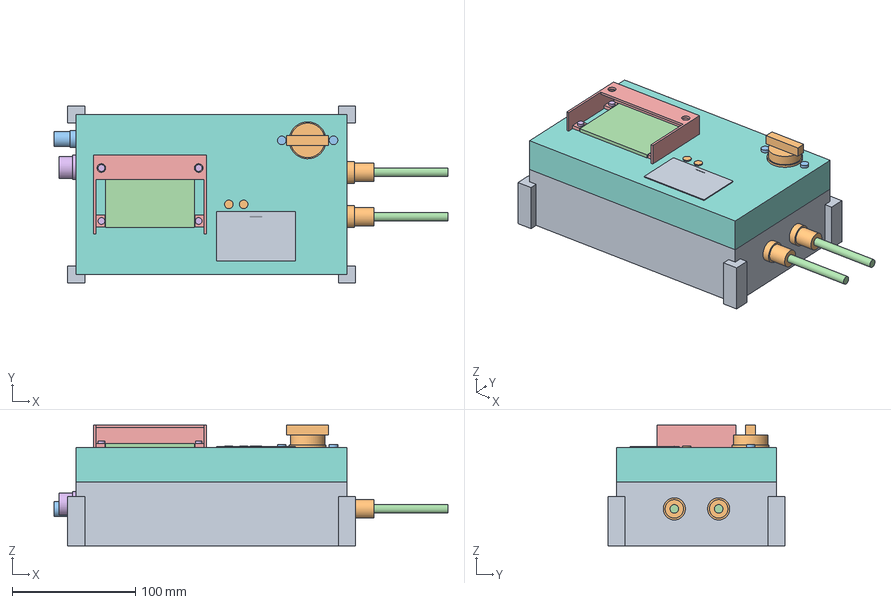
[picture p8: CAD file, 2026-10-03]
cad/step/pvtrace-assembly.step
320.0 x 144.0 x 98.0 mm

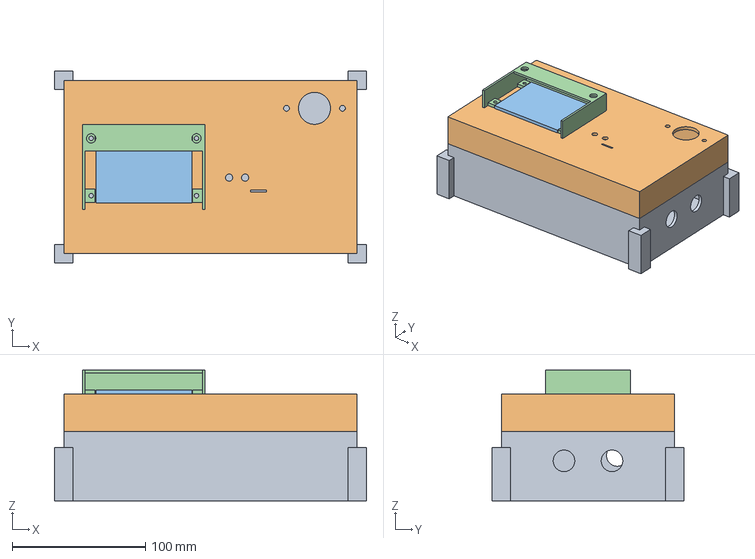
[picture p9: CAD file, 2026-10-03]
cad/step/pvtrace-enclosure.step
234.0 x 144.0 x 98.0 mm

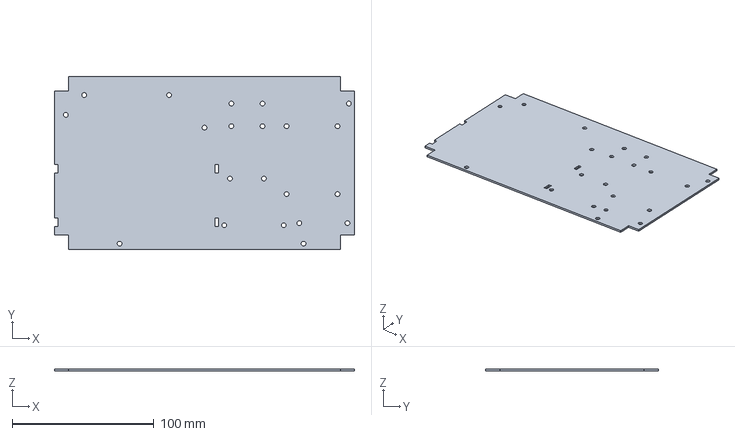
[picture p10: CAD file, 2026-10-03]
cad/step/pvtrace-chassis-plate.step
212.0 x 122.0 x 1.50 mm

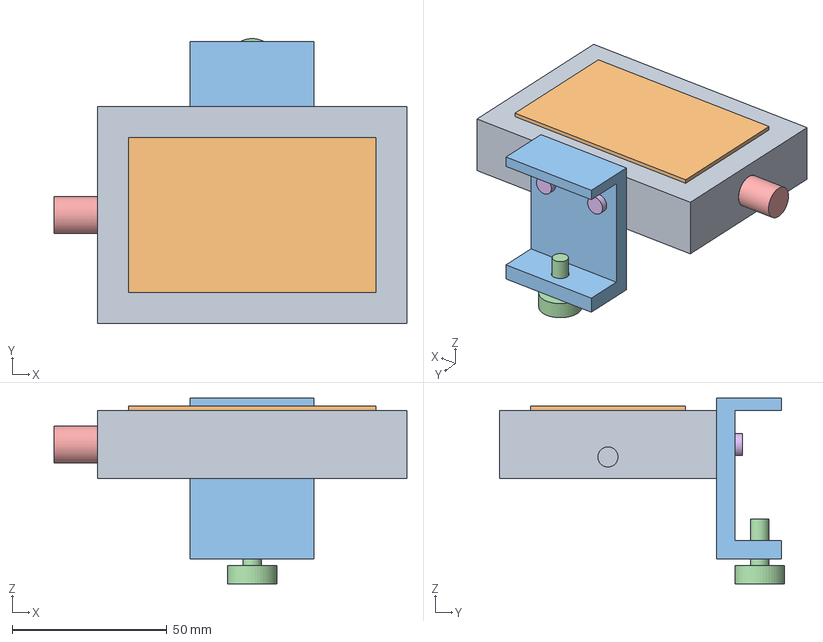
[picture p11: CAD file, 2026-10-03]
cad/step/pvtrace-sensor-pod.step
114.0 x 92.0 x 60.0 mm

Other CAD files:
cad/stl/pvtrace-assembly.stl
cad/stl/pvtrace-enclosure.stl
cad/stl/pvtrace-sensor-pod.stl

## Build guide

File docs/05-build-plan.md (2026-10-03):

---
doc_id: PVT-BLD-001
title: PVTrace prototype build plan
project: PVTrace
doc_type: Build plan
version: "0.4"
status: Draft
date: '2026-10-03'
author: Amish Chadha
license: CERN-OHL-S-2.0
revisions:
  - version: "0.1"
    date: '2026-10-01'
    author: Amish Chadha
    change: First build plan, with pictures by component and step; design made constructable (PVT-DDR-003)
  - version: "0.2"
    date: '2026-10-02'
    author: Amish Chadha
    change: Load capacitors measured and selected to at least 6.4 mF together (section 3.11; PVT-DEC-001, item 4)
  - version: "0.3"
    date: '2026-10-02'
    author: Amish Chadha
    change: "Keypad and status lights added (BOM line 18; lid slot and two holes, wiring item 11, step 9); capacitor buying changed to four with one spare; costs and figures brought into line; 19 components"
  - version: "0.4"
    date: '2026-10-03'
    author: Amish Chadha
    change: "Load capacitor selection minimum restated as 6.45 mF (section 3.11), decided by Amish on 2026-10-03"
---

# PVTrace prototype build plan

**Plan, not yet built.** How to build the first proof-of-concept prototype, component by component. Building and testing to it is TRL 4 work. Decisions still to be made are kept in the design decisions register ([docs/06-design-decisions.md](06-design-decisions.md)), not here.

## 1. What you are building

Figure 1. Every component, pulled apart and numbered in build order

*Figure 1. Every component pulled apart and numbered in build order. The case parts are stacked over the body; the sensor pod, 19, is on the left.*

The prototype is one handheld PVTrace: a light grey plastic case, 220 x 130 x 80 mm, with two test leads leaving its right end, a DC isolator knob, a three-key keypad with two status lights and a display under a small sun hood on its lid, and a sensor pod on a 3 m cable that clips to the frame of the module under test. Inside, a clear plastic chassis plate carries every part in the body: three large capacitors that form the sweep load, a bar with two switching transistors (MOSFETs), a discharge resistor, a fuse, a cell holder with its charger, and two hand-wired boards that measure the module and keep it electrically separate from the controller side. Figure 1 shows the 19 components in the order you make or fit them. Eight are made in a small workshop: the drilled case body, the chassis plate, the MOSFET bar, the cut and drilled lid, the window, and three 3D prints (the sun hood, the pod housing and the pod clip). Everything else is bought and fitted. The work is drilling a plastic case, cutting and drilling plastic sheet, drilling and tapping one aluminium bar, three prints, and wiring bought modules and perfboard. The parts cost about $192 from the bill of materials.

> **Safety:** PVTrace connects to solar modules that are live whenever light falls on them, at up to 100 V DC and 20 A, and its capacitors store up to 33 J. Build and check it on a bench supply first; connect it to a module only at stop S5 in section 6, with the isolator open while connecting, and never open the case with the leads connected. Treat the capacitors as charged until the display reads below 30 V and a meter confirms it. The cell is lithium-ion: keep it out of its holder until stop S1, and charge it only in shade, on a non-flammable surface, never unattended.

## 2. What changed to make it buildable

The concept showed what the tracer does; many of its parts had no fixing or could not be fitted as drawn. Each change below keeps what the tracer does, and all of them are recorded in decision record PVT-DDR-003, open for Amish's review.

*Table 1. Changes from the concept.*

| Component | The concept had | The buildable design has | Why |
| --- | --- | --- | --- |
| Cable glands | Drawn outside the end walls, no holes, no locknuts | Holes through the walls and locknuts inside; the lead glands 2 mm closer together, the sensor gland 10 mm further back (Figures 4 and 5) | A spanner reaches every nut; the nuts clear the fuse holder |
| Window | The same size as the lid opening, nothing to bond to | A 72 x 54 mm window bonded on top of the lid over a 62 x 46 mm opening (Figure 18) | A 4 to 5 mm bond land seals the opening |
| Sun hood | No fixing; walls too thin for the screws | Four screw tabs inside the side walls; 4 mm wider; screwdriver holes in the roof lip (Figures 19 and 21) | The hood screws down to the lid |
| Display board | Floating under the lid, drawn larger than the real board | The real 86 x 50 mm board on four spacers, held by the hood's four screws (Figures 20 and 21) | One set of screws holds the hood and the board |
| Parts in the body | Standing on the floor with no fixing | A clear chassis plate on five standoffs, every part screwed to it (Figures 6 to 8) | Five floor holes only; the fit-out is built on the bench and lowered in |
| Capacitors | Lying loose, one overlapping a lid screw pillar | Moved clear of the pillars; a bed of silicone and two cable ties through the plate (Figure 12) | Held down without a printed cradle |
| MOSFETs, isolator, holders | No fixings | A tapped aluminium bar for the MOSFETs on insulating pads; the isolator's own flange and screws; two screws for each holder (Figures 10 and 17) | Every fixing can be fitted with hand tools |
| Measurement board | On the floor, clear of nothing once raised | Turned 90 degrees on standoffs (Figure 7) | Clears the gland nuts, the MOSFET bar and the isolator body |
| USB-C charging | No port through the case | An IP65 USB-C socket with a cap in the left end (Figure 5) | Charges with the case closed and the isolator open |
| Sensor pod | A solid block for a clip, no cable entry | A C-clip with a thumb screw, screwed to the housing; a cable gland (Figures 23 and 24) | Grips frames 30 to 40 mm deep with the cell parallel to the glass |

## 3. Making the components

Make and check each component before the assembly step that needs it. Sizes are in millimetres. The **front** is the long side of the case toward the user, where the sun hood opens; the **left end** carries the sensor gland and the USB-C socket and the **right end** the test leads. Workshop tolerance is 0.5 mm unless a step says otherwise; drawings do not carry tolerances before TRL 4.

### 3.1 Enclosure body, drilled, with its glands and USB-C socket

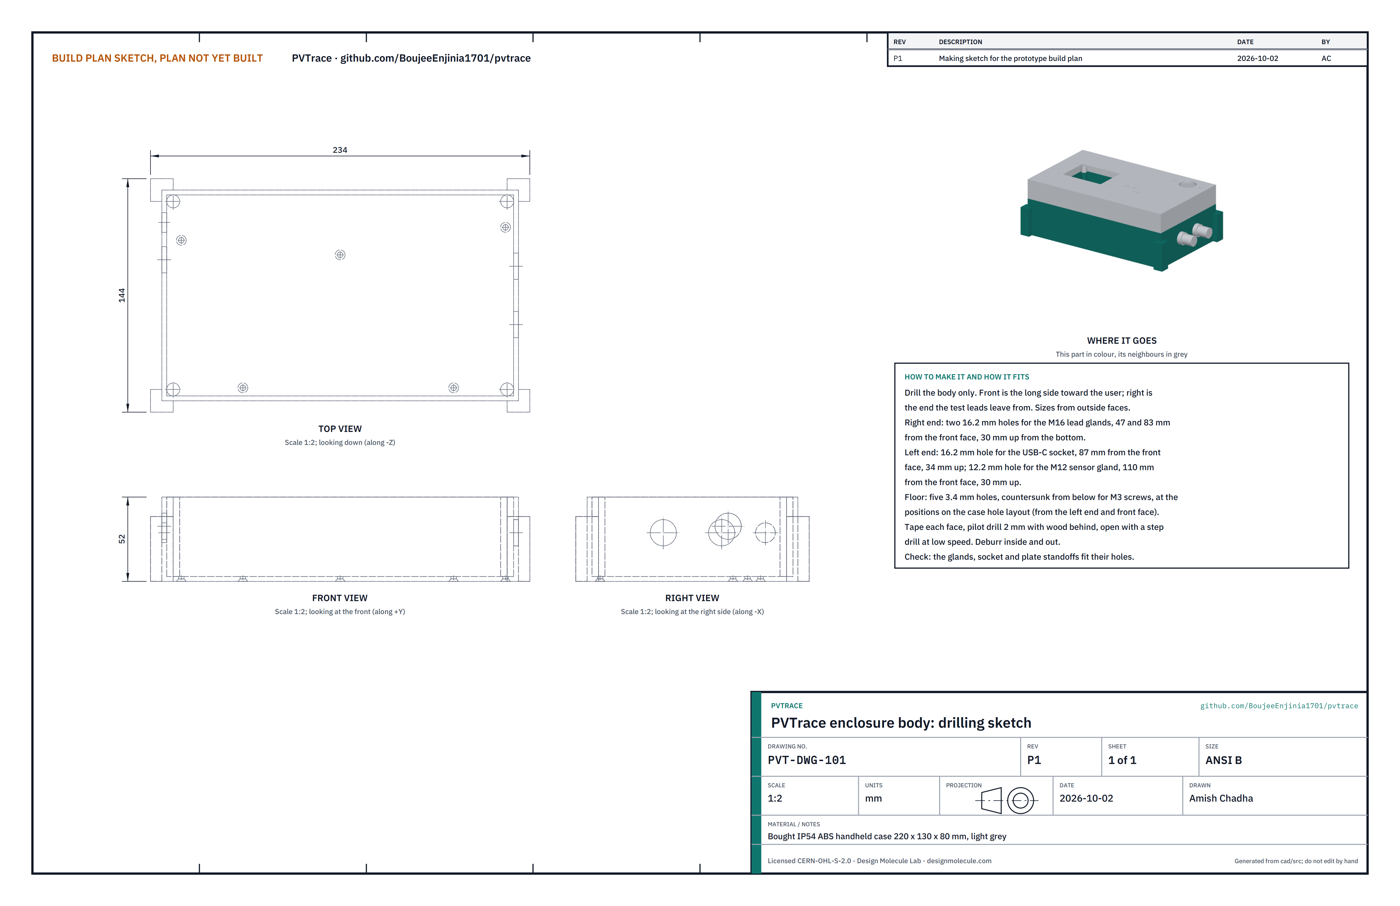
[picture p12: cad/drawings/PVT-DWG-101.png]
Figure 2. Drilling sketch of the enclosure body


*Figure 2. Enclosure body drilling sketch (PVT-DWG-101).*

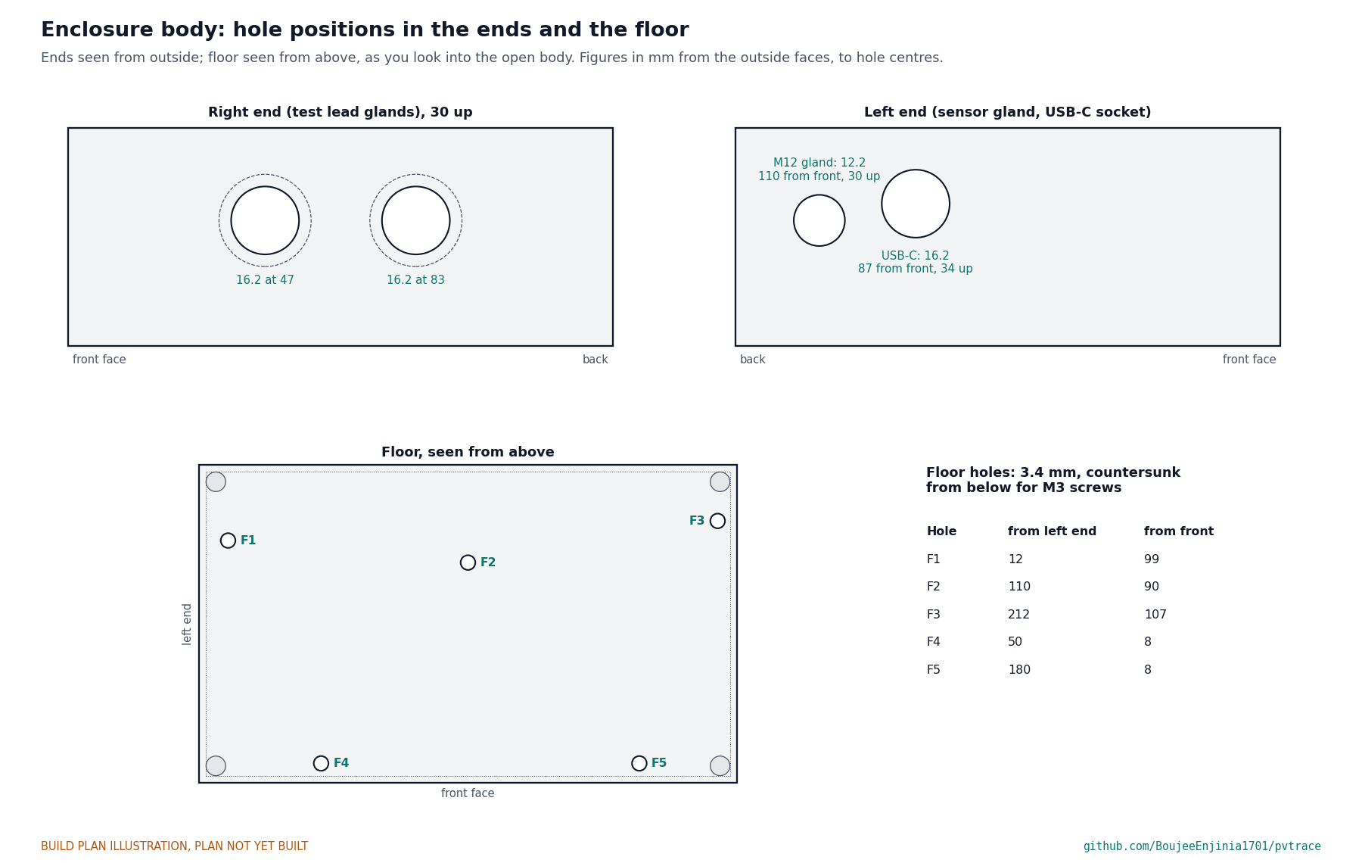
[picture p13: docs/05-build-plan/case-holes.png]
Figure 3. Hole positions in the ends and floor


*Figure 3. Every hole in the two ends and the floor, measured from the outside faces.*

**What it is and what it is made from.** A bought IP54 handheld case in light grey ABS, 220 x 130 x 80 mm, with rubber corner bumpers, a gasketed lid that screws into four moulded corner pillars, and three cable glands. Nine holes are drilled in the body.

**How to make it.**

1. Cover the ends and floor with masking tape. Mark the holes from Figure 3, measuring from the outside faces.
2. Right end: two holes for the M16 lead glands, 47 and 83 mm from the front face, 30 mm up from the bottom.
3. Left end: one hole for the USB-C socket, 87 mm from the front face and 34 mm up; one hole for the M12 sensor gland, 110 mm from the front face and 30 mm up.
4. Floor: five holes for the chassis plate standoffs, at F1 to F5 in Figure 3. Countersink each from below for an M3 countersunk screw.
5. Put a block of wood behind each face. Pilot drill every hole 2 mm at low speed, then open with a step drill: 16.2 mm for the two lead glands and the USB-C socket, 12.2 mm for the sensor gland, 3.4 mm in the floor. Check the gland and socket sizes on their datasheets before the last step.
6. Deburr inside and out, peel the tape and clean with soap and water.

**How it fits the parts next to it.**

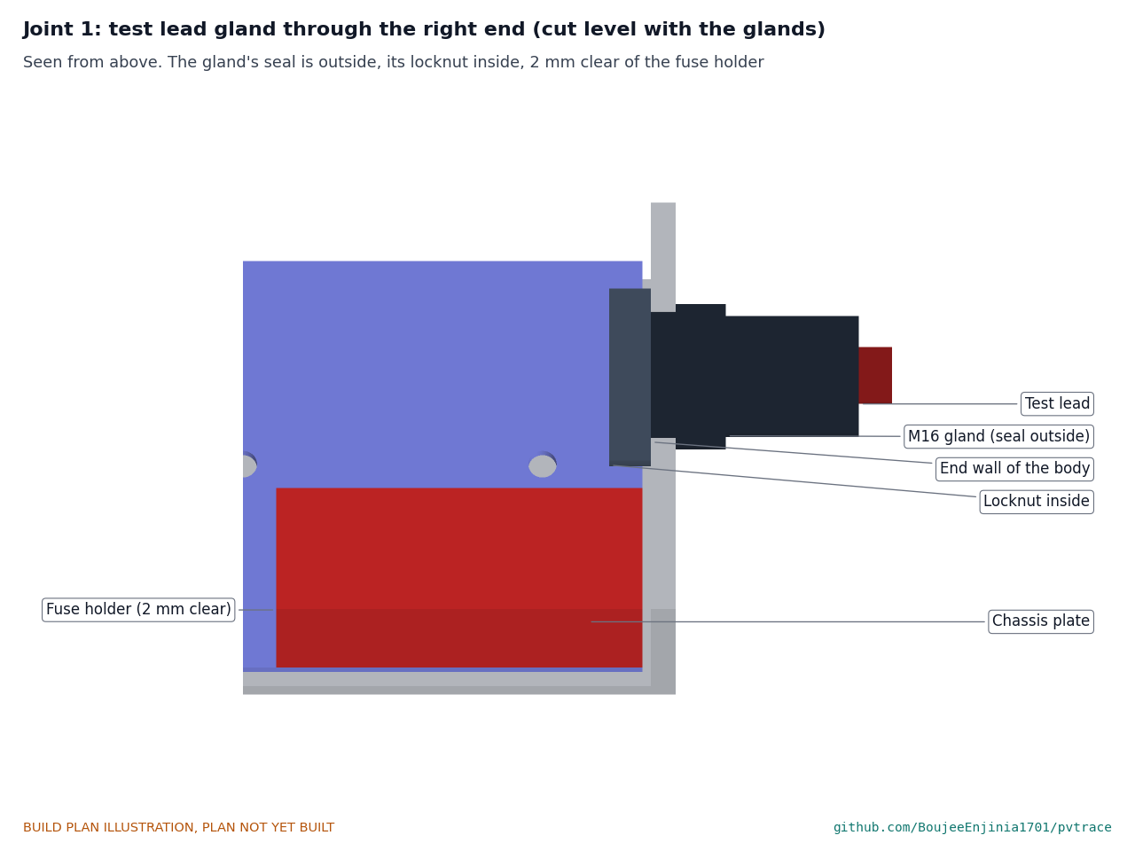
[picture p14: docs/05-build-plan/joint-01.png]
Figure 4. Joint 1: a test lead gland through the right end


*Figure 4. The gland's seal is outside and its locknut inside; the nut is 2 mm clear of the fuse holder.*

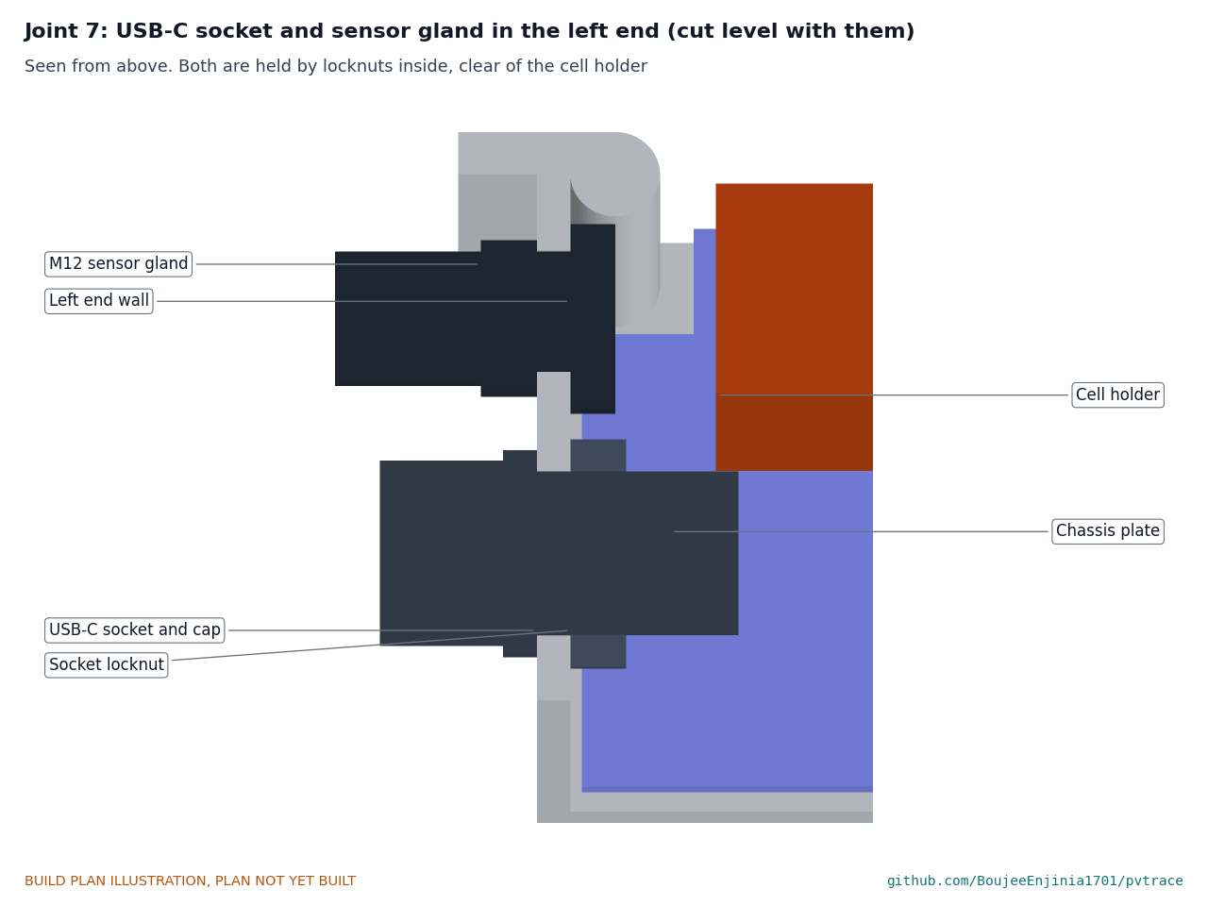
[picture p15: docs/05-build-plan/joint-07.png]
Figure 5. Joint 7: USB-C socket and sensor gland in the left end


*Figure 5. The socket and the sensor gland, each held by a locknut inside, clear of the cell holder.*

Each gland and the socket go in from outside with their sealing washers outside and their locknuts inside, hand tight plus a quarter turn (step 2). The chassis plate sits 1 mm in from every wall on five standoffs screwed up through the floor (Figure 6).

**Check before moving on.** Each gland and the socket seat flat on their washers; no crack runs out from any hole under a bright lamp; the five floor screws sit flush or just below the floor.

### 3.2 Chassis plate

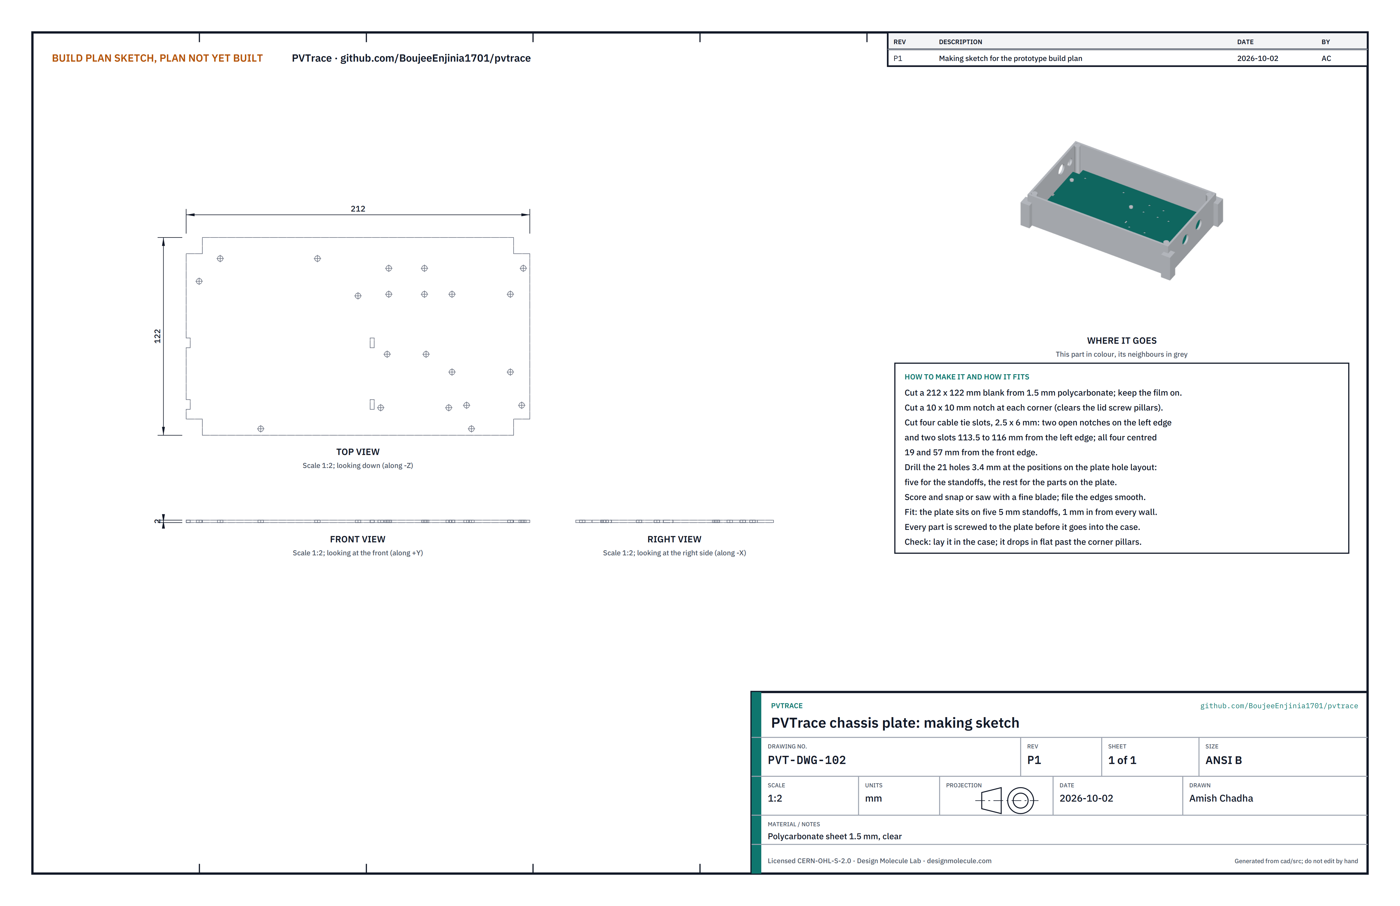
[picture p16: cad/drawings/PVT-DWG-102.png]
Figure 6. Making sketch of the chassis plate


*Figure 6. Chassis plate making sketch (PVT-DWG-102).*

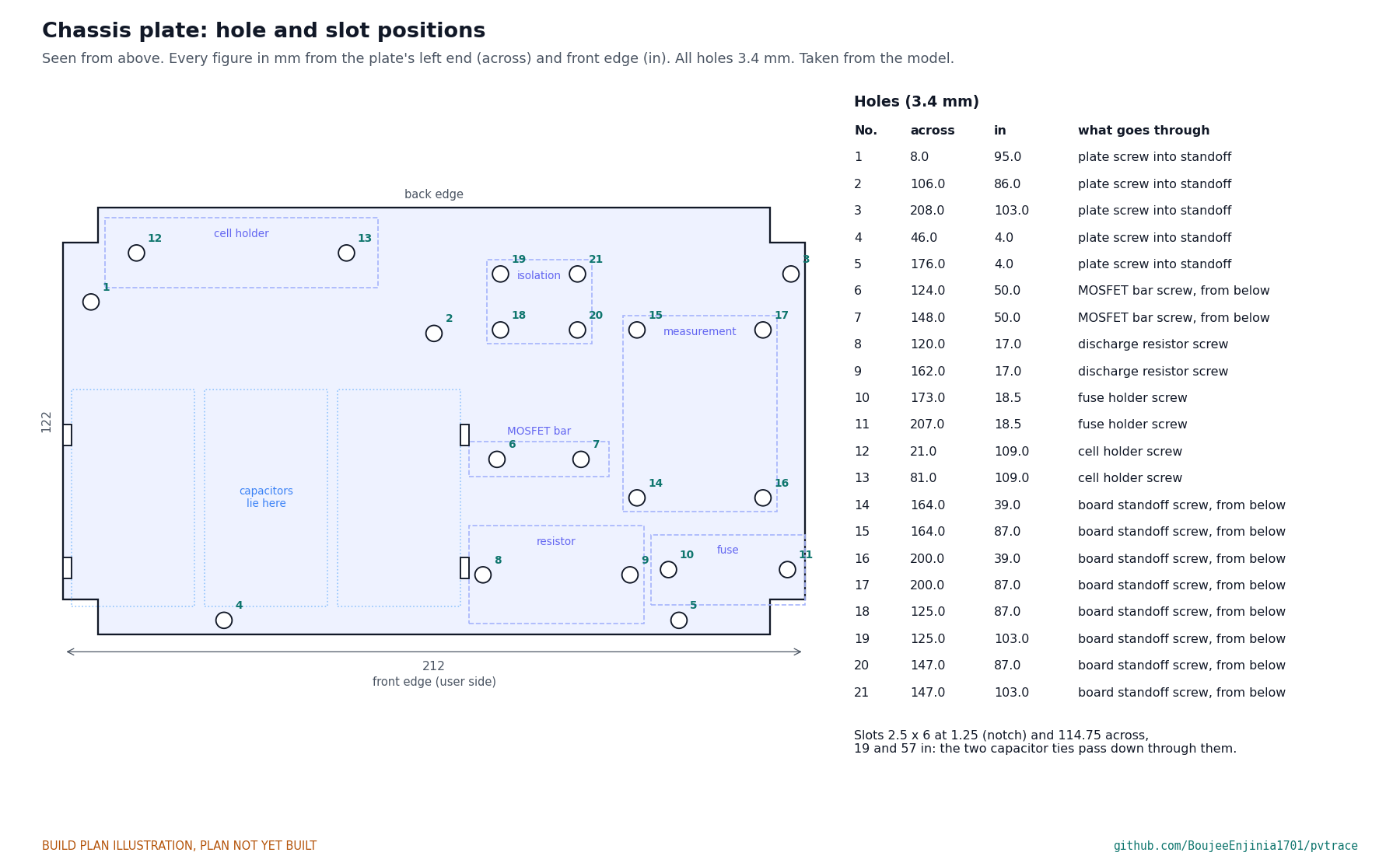
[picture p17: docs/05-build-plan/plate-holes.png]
Figure 7. Hole and slot positions in the chassis plate


*Figure 7. All 21 holes and the four tie slots, with the footprint of each part that sits on the plate.*

**What it is and what it is made from.** The flat plate that carries every part in the body and lifts out as one unit. Clear polycarbonate sheet 1.5 mm, an insulator.

**How to make it.**

1. Cut a 212 x 122 mm blank; keep the protective film on.
2. Cut a 10 x 10 mm notch at each corner; these clear the lid screw pillars.
3. Cut the four 2.5 x 6 mm tie slots: two as open notches on the left edge and two 113.5 to 116 mm from the left edge, all centred 19 and 57 mm from the front edge.
4. Mark the 21 holes from the table in Figure 7, measured from the left edge and the front edge. Drill each 3.4 mm.
5. File every edge smooth and peel the film.

**How it fits the parts next to it.**

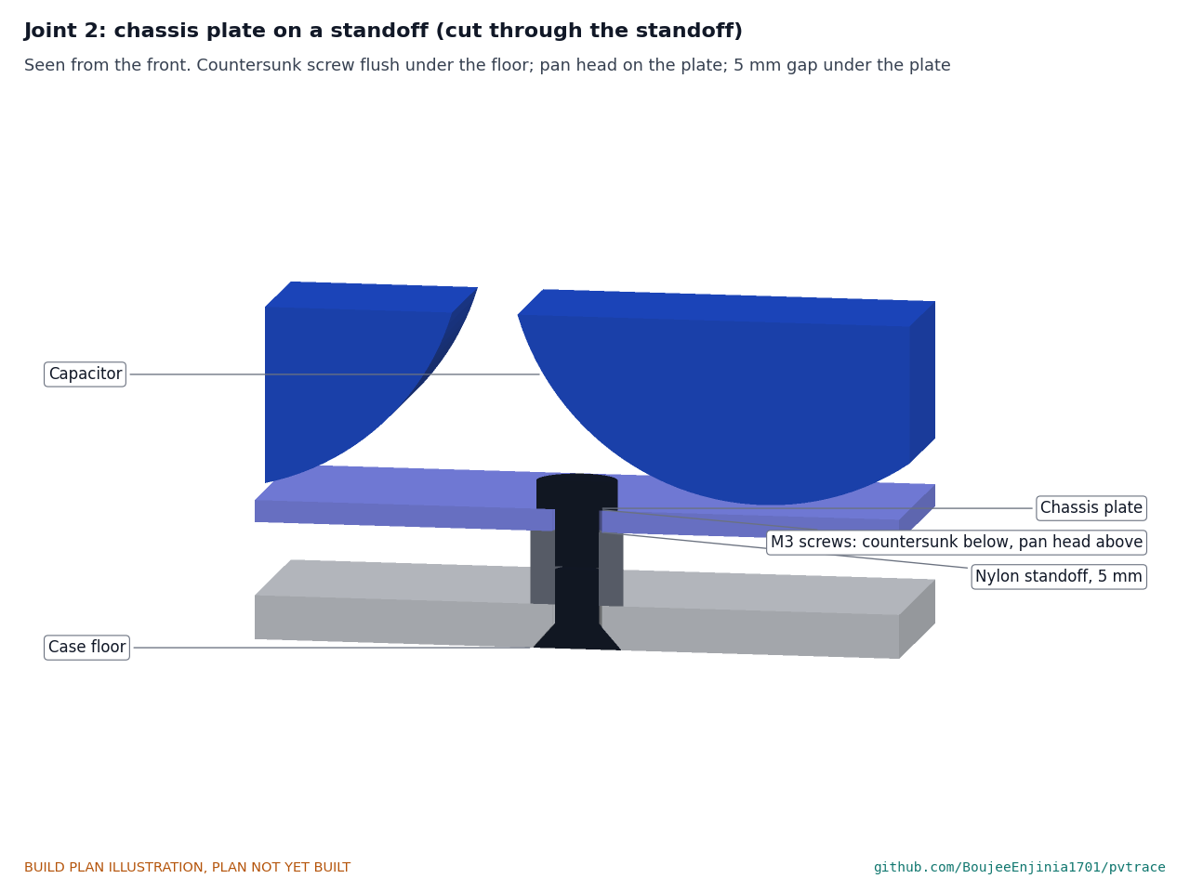
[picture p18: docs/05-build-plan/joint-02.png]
Figure 8. Joint 2: the chassis plate on a standoff


*Figure 8. A countersunk M3 screw comes up through the floor into a 5 mm nylon standoff; a pan-head M3 screw holds the plate on top. The gap under the plate leaves room for the nuts and ties.*

The plate sits on the five standoffs, 5 mm above the floor. Every part on it is fixed by M3 screws through its holes, with the nuts or screw heads in the gap underneath. All five plate screws can be reached from above with every part fitted, so the plate goes in and out as one unit.

**Check before moving on.** Lay the plate in the empty case: it drops in flat past the four pillars with about 1 mm all round.

### 3.3 MOSFET bar

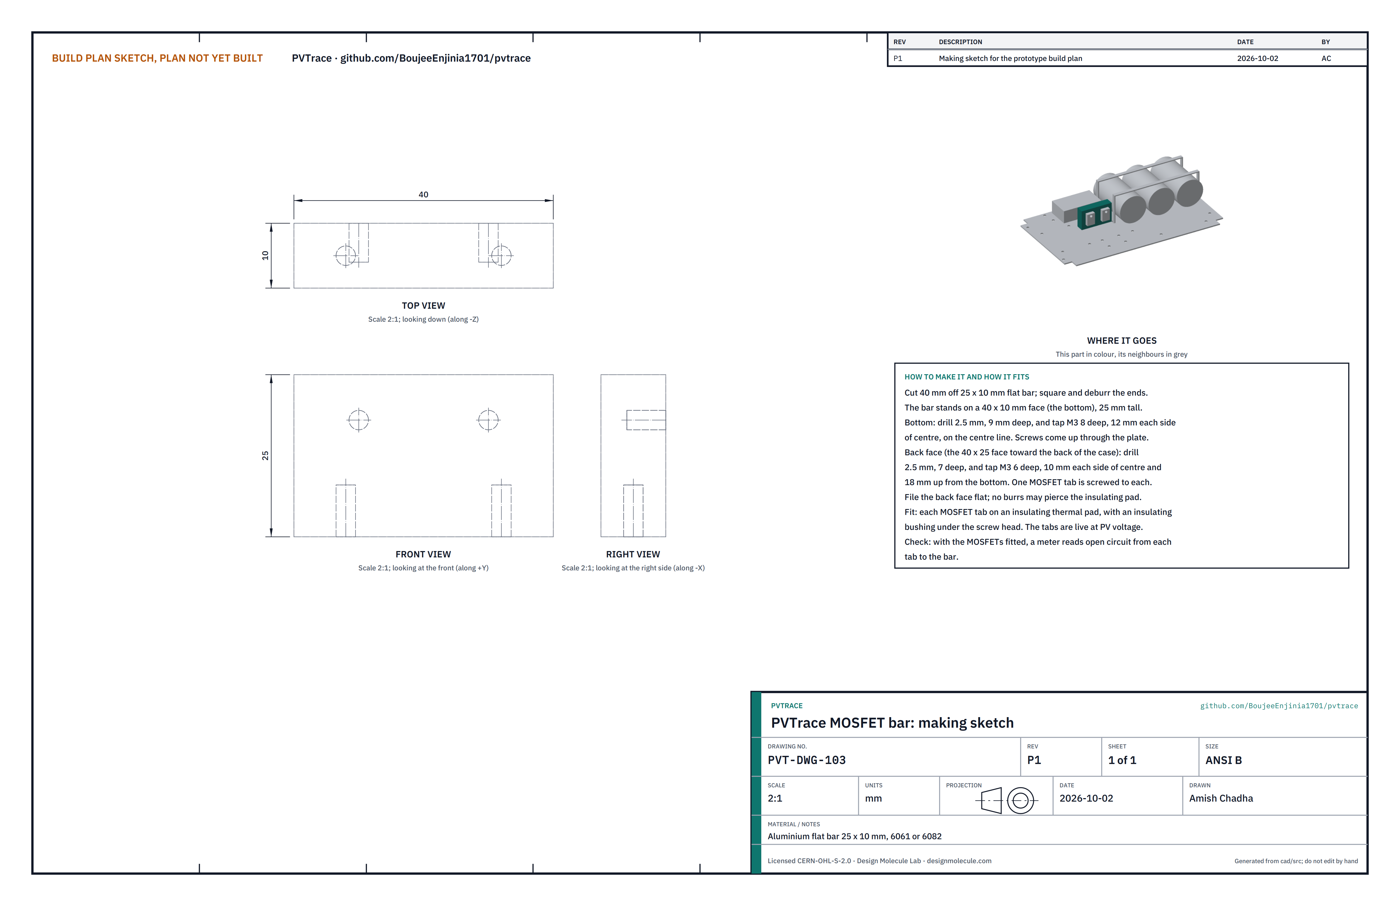
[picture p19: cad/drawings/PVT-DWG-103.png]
Figure 9. Making sketch of the MOSFET bar


*Figure 9. MOSFET bar making sketch (PVT-DWG-103).*

**What it is and what it is made from.** A small aluminium bar that carries the load and discharge MOSFETs and spreads their heat. Aluminium flat bar 25 x 10 mm, 6061 or 6082 class.

**How to make it.**

1. Cut 40 mm off the bar; square and deburr the ends. It stands on a 40 x 10 mm face, 25 mm tall.
2. Bottom face: on the centre line, 12 mm each side of centre, drill 2.5 mm 9 deep and tap M3 8 deep.
3. Back face (the 40 x 25 face toward the back of the case): 10 mm each side of centre and 18 mm up from the bottom, drill 2.5 mm 7 deep and tap M3 6 deep.
4. File the back face flat so no burr can pierce the insulating pads.

**How it fits the parts next to it.**

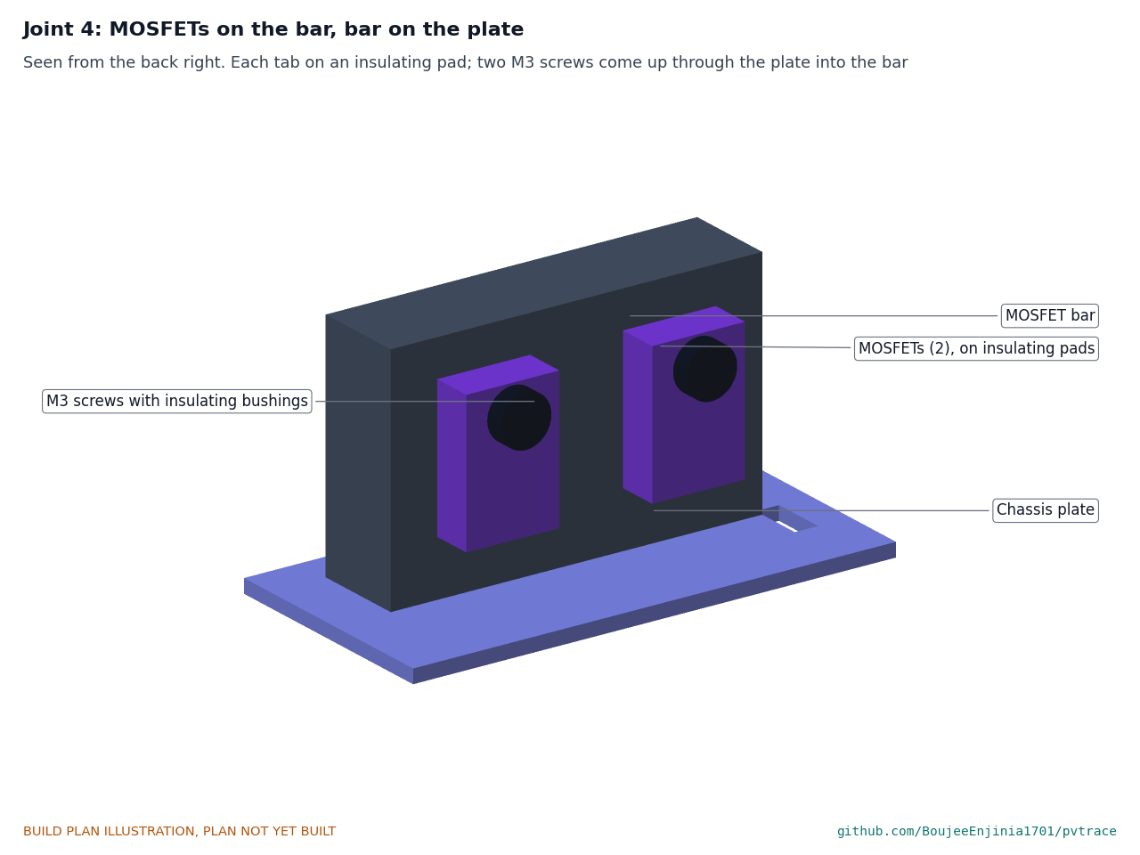
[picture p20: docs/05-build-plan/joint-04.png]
Figure 10. Joint 4: MOSFETs on the bar, bar on the plate


*Figure 10. Each MOSFET tab sits on an insulating thermal pad, screwed to the bar through an insulating bushing.*

The MOSFET tabs are live at module voltage; the pad and bushing keep them off the bar. Two M3 screws come up through the plate into the bar's bottom.

**Check before moving on.** With both MOSFETs fitted, a meter reads open circuit from each tab to the bar.

### 3.4 Parts on the plate

**What they are.** The discharge resistor (22 ohm, 50 W, aluminium clad), the fuse holder with its 20 A fuse, the cell holder with the charger and boost modules, the measurement board, the isolation board and the three load capacitors. All are bought (section 3.11); the two boards are hand-wired on perfboard.

**How to fit them.**

1. Resistor, fuse holder and cell holder: two M3 screws each through the plate, nuts underneath (step 4). No cell in the holder and no fuse in the fuse holder yet.
2. Measurement board (44 x 56 mm, turned with its long side front to back) and isolation board (30 x 24 mm): each on four 6 mm nylon standoffs, M3 screws from under the plate (step 5).
3. Capacitors: lie each on a bed of neutral-cure silicone, pins toward the front, then pass two cable ties down through the slots, under the plate and round all three (step 6).

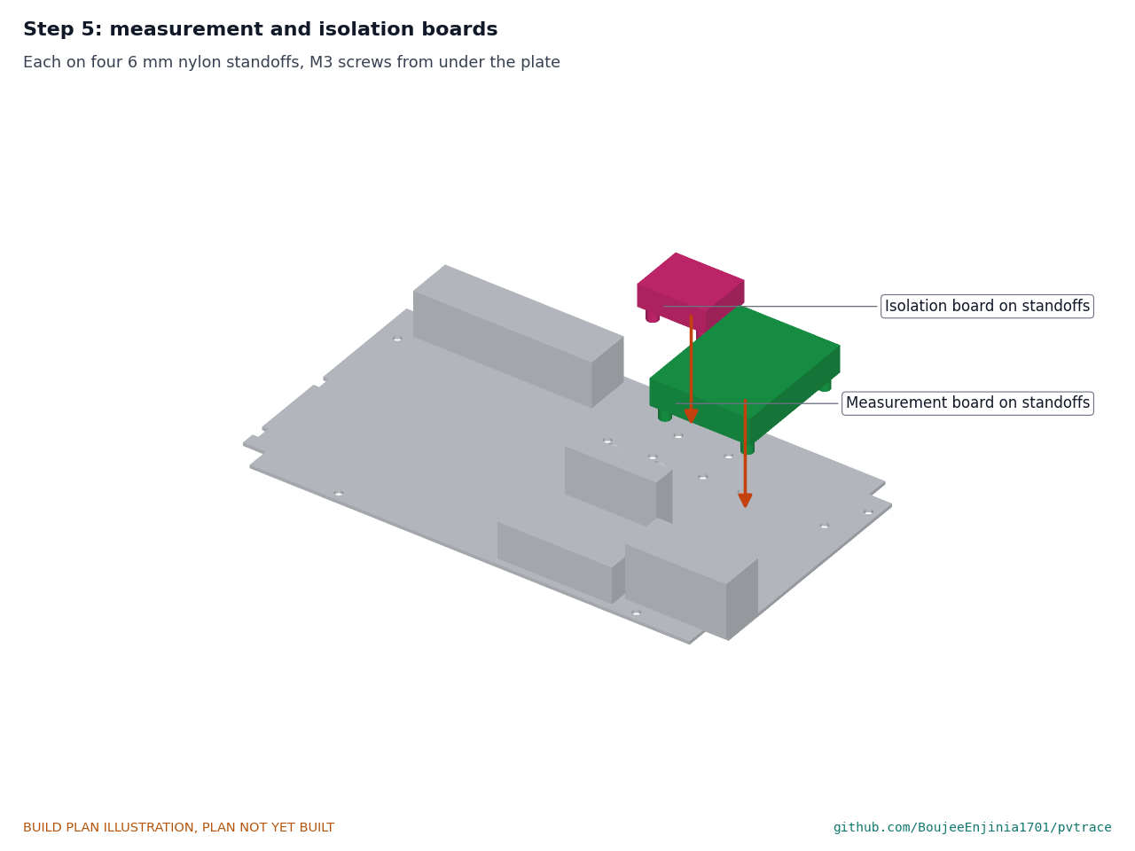
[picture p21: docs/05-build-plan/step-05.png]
Figure 11. Step 5 picture: the boards on their standoffs


*Figure 11. Where the measurement and isolation boards go.*

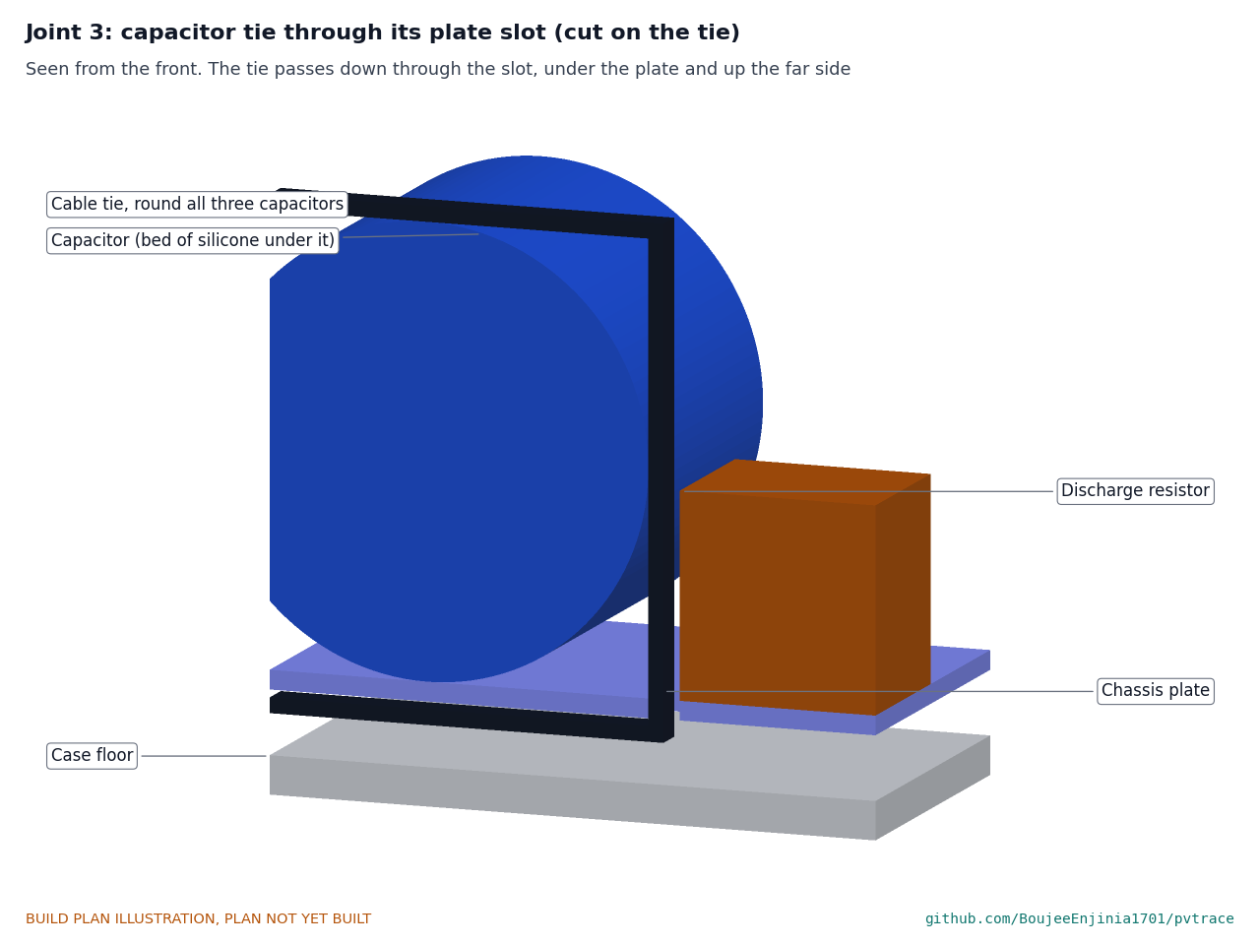
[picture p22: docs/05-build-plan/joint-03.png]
Figure 12. Joint 3: a capacitor tie through its plate slot


*Figure 12. Each tie passes down through a slot at one end of the bank, under the plate and up the other end.*

**Check before moving on.** Nothing on the plate rocks when pushed by hand; the capacitors cannot roll; the ties are pulled tight and trimmed flush.

#### 3.4.1 Wiring

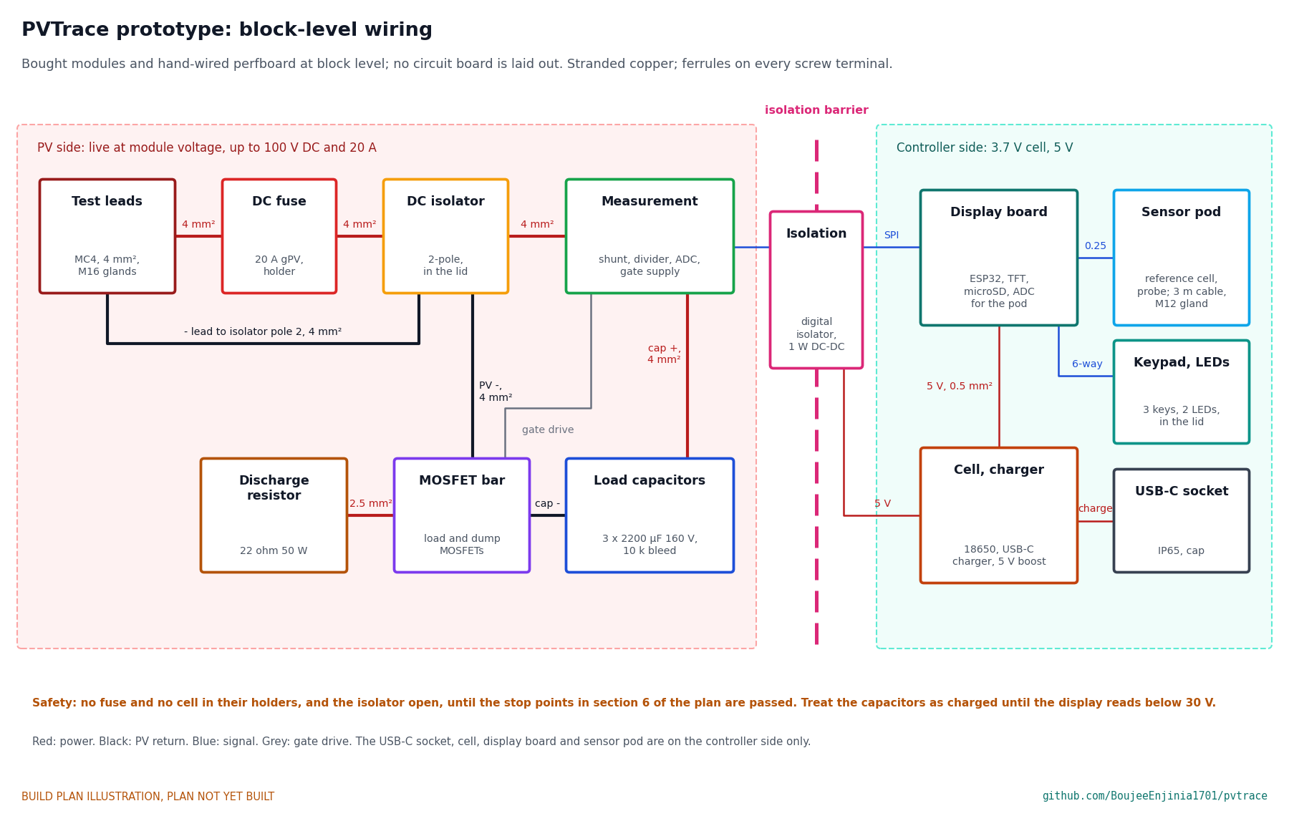
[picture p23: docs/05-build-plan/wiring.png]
Figure 13. Block-level wiring


*Figure 13. Block-level wiring with wire sizes. No circuit board is laid out at this stage; bought modules and perfboard stand in for it.*

The isolation barrier divides the tracer in two. Everything on the PV side can be at module voltage; everything on the controller side stays at the cell's 3.7 V and 5 V. Only the isolation board crosses the line.

Wire it like this, with stranded copper, ferrules on every screw terminal and heat-shrink on every soldered joint:

1. Positive test lead through its gland to the fuse holder, then to pole 1 of the DC isolator: 4 mm².
2. Negative test lead through its gland to pole 2 of the DC isolator: 4 mm².
3. Isolator pole 1 to the measurement board's shunt, and from the shunt to the capacitors' positive pins: 4 mm².
4. Capacitors' negative pins to the load MOSFET, and the MOSFET to isolator pole 2: 4 mm².
5. Discharge MOSFET and discharge resistor across the capacitors, and the 10 kohm bleed resistor directly across the capacitors' pins: 2.5 mm².
6. Measurement board to the MOSFET gates: 0.25 mm², twisted with their returns.
7. Measurement board to the isolation board (signals and the isolated supply), and the isolation board to the display board: 0.25 mm².
8. Cell and charger to the isolation board and the display board: 0.5 mm², through the 5 V boost.
9. USB-C socket to the charger input: 0.5 mm².
10. Sensor pod cable through its gland to the display board's ADC module and the probe input: 0.25 mm².
11. The keypad and its two status lights go to the display board on a 6-way lead of 0.25 mm² wire: three keys, two lights and a common return. Fit a header on the display board's spare pins and a matching plug on the lead; the keypad's own flat tail plugs into a 6-way socket at the end of the lead. This is on the controller side of the isolation barrier.
12. The isolator, the keypad, the lights and the display board are in the lid. Leave a 150 mm service loop on every lead to the lid so it can be laid beside the case open.

Keep the PV-side wires and the controller-side wires apart, at least 8 mm on the plate, and cross the barrier only at the isolation board.

**Check before moving on.** With no cell, no fuse and the isolator open: every wire continues end to end; the test leads read open to the USB-C socket shell; every wire is labelled.

### 3.5 Lid, cut and drilled, with the DC isolator, keypad and status lights

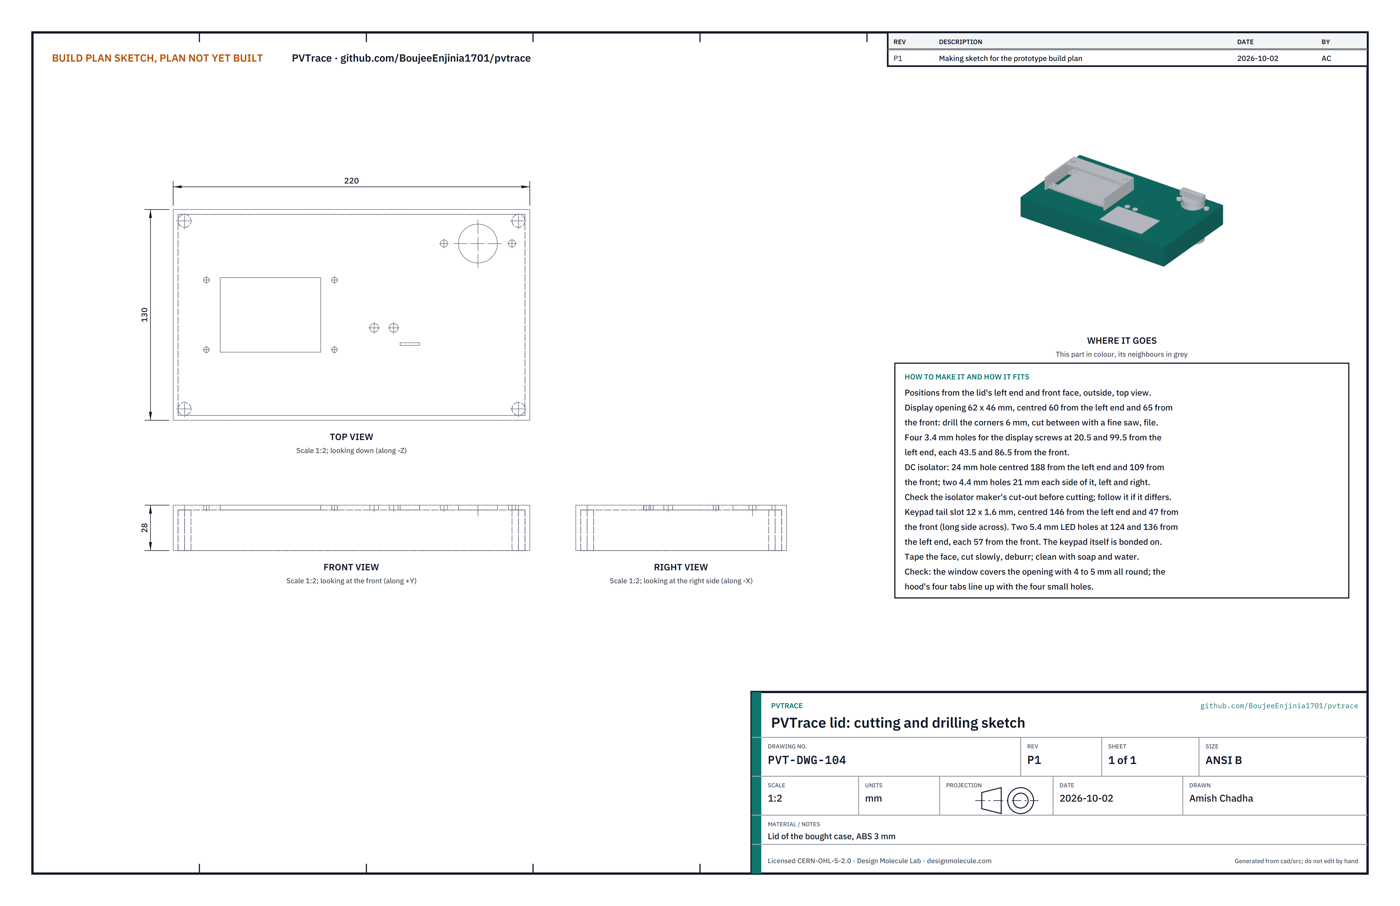
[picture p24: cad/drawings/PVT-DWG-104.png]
Figure 14. Cutting and drilling sketch of the lid


*Figure 14. Lid cutting and drilling sketch (PVT-DWG-104).*

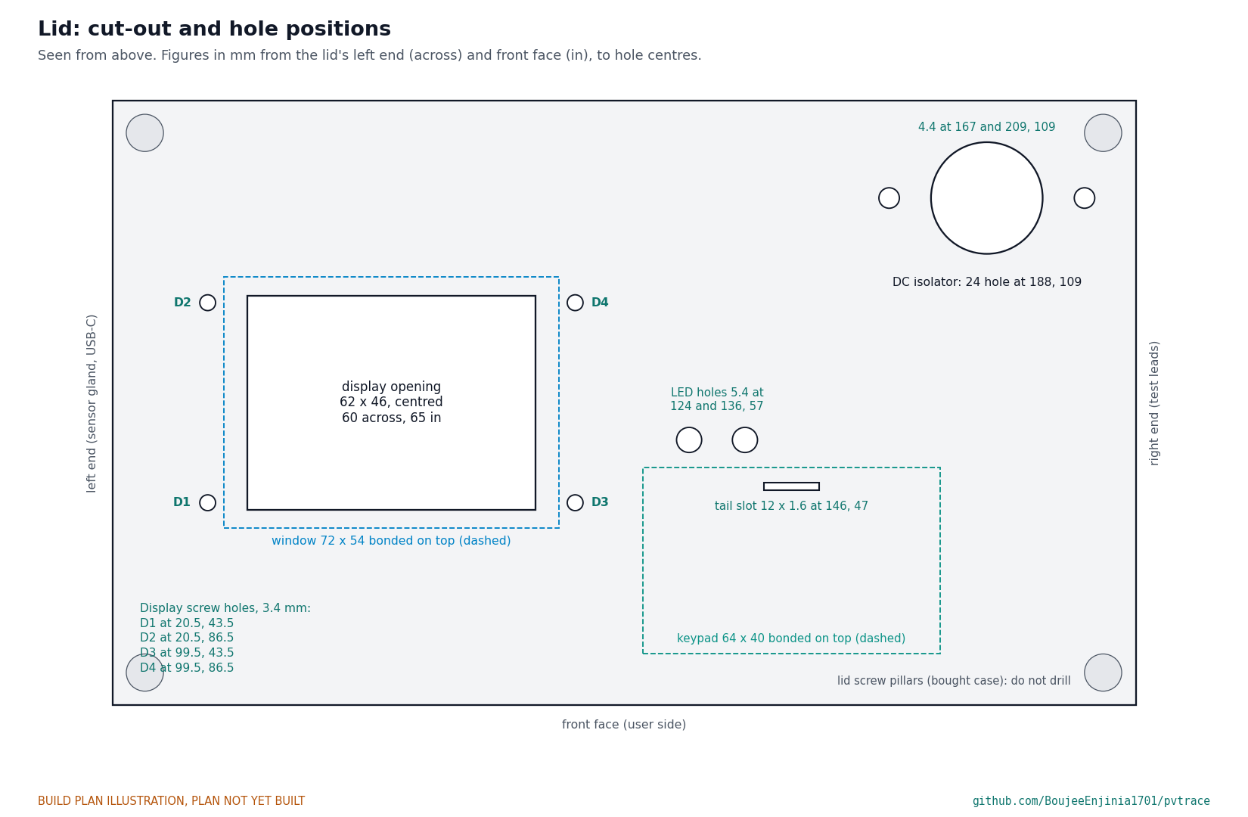
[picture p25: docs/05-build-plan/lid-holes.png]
Figure 15. Lid cut-out and hole positions


*Figure 15. The display opening, the four display screw holes, the isolator holes, the keypad slot and the two status light holes, measured from the left end and the front face.*

**What it is and what it is made from.** The case's own lid, 3 mm ABS, with a display opening, a narrow slot for the keypad tail and nine holes.

**How to make it.**

1. Tape the top. Mark the display opening, 62 x 46 mm, centred 60 mm from the left end and 65 mm from the front.
2. Drill a 6 mm hole in each corner of the opening, cut between them with a fine saw, and file the edges straight.
3. Drill the four 3.4 mm display screw holes at D1 to D4 in Figure 15.
4. DC isolator: a 24 mm hole centred 188 mm from the left end and 109 mm from the front, and two 4.4 mm holes 21 mm left and right of it. Check the isolator maker's cut-out drawing first and follow it if it differs.
5. Keypad tail slot: a 12 x 1.6 mm slot centred 146 mm from the left end and 47 mm from the front, long side across the lid. Drill a 2 mm hole at each end, cut between them with a fine saw and file it smooth.
6. Two 5.4 mm holes for the status lights, 124 mm and 136 mm from the left end and 57 mm from the front.
7. Deburr, peel the tape and clean with soap and water.

**How it fits the parts next to it.**

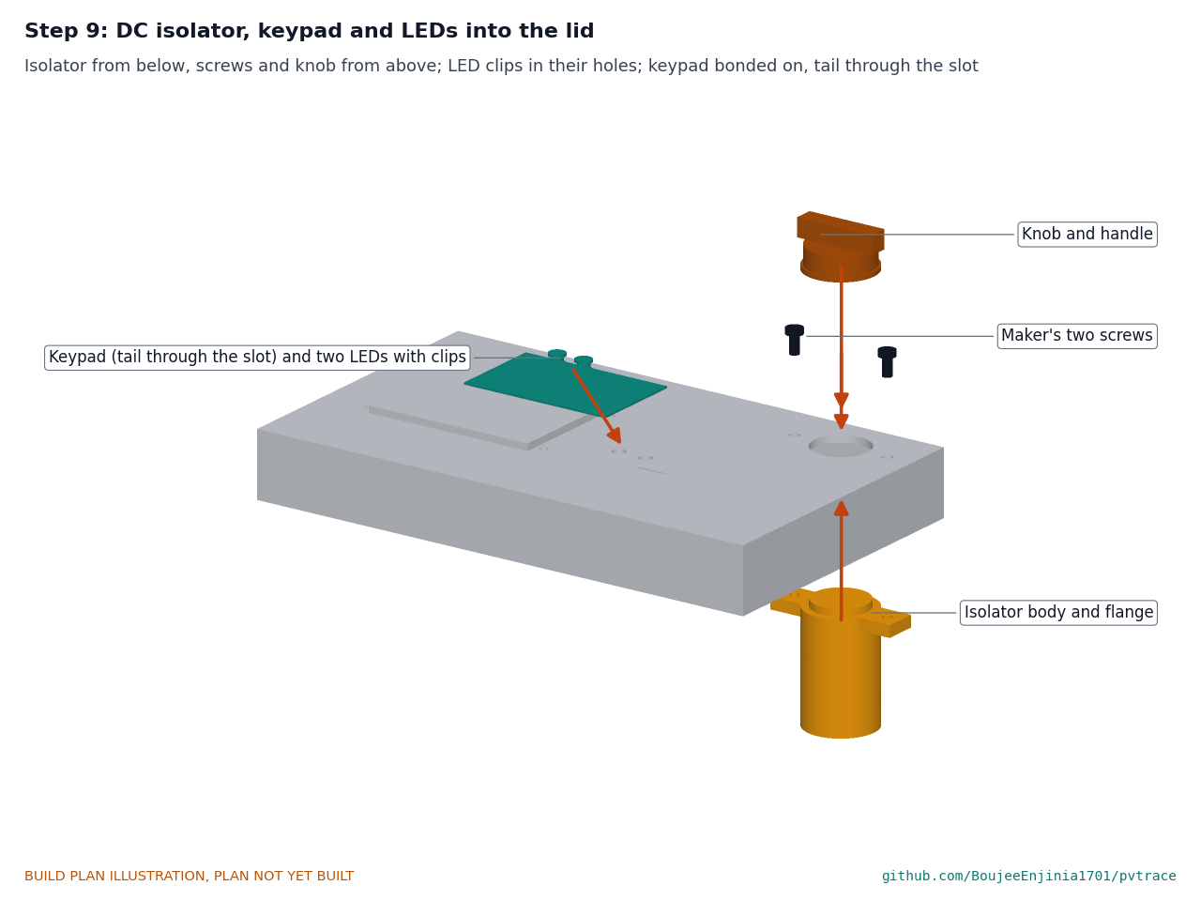
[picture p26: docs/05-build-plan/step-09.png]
Figure 16. Step 9 picture: the isolator into the lid


*Figure 16. The isolator body goes up from below until its flange meets the lid; the maker's two screws go down from above; then the knob and handle. The two status lights clip into their holes and the keypad is bonded on with its tail through the slot.*

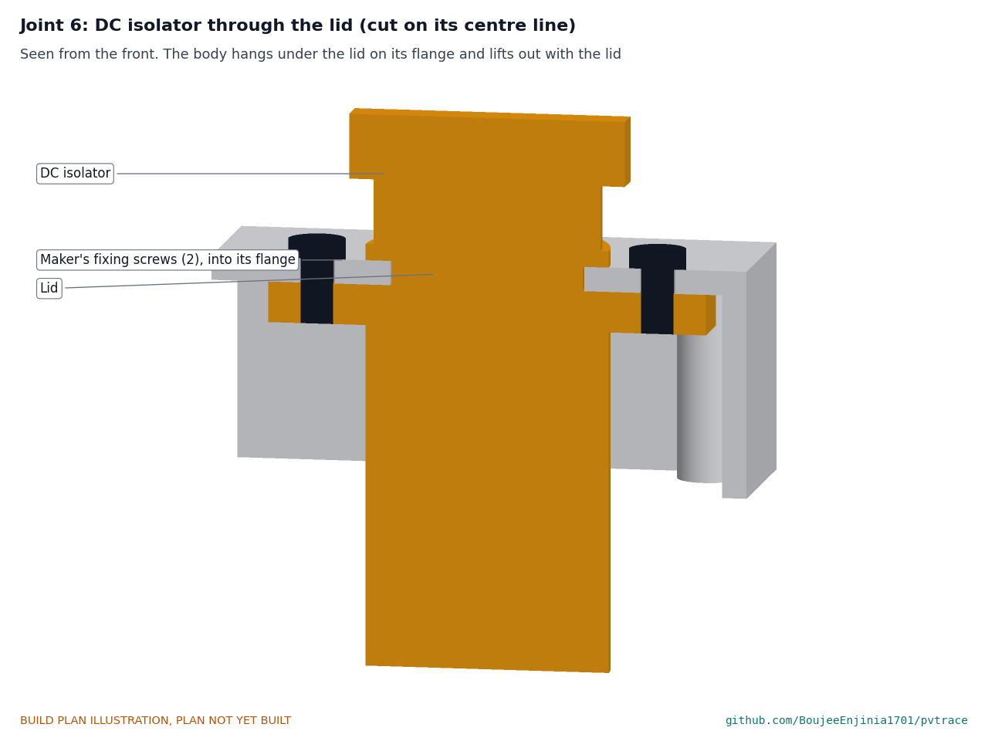
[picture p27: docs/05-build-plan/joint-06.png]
Figure 17. Joint 6: the DC isolator through the lid


*Figure 17. The isolator hangs from the lid on its own flange and lifts out with the lid.*

**Check before moving on.** The isolator turns cleanly between its two positions; the lid closes on the body with the isolator 2.5 mm above the measurement board; the keypad lies flat with its tail through the slot and clear of the sun hood and the isolator; the two lights sit flush.

### 3.6 Window

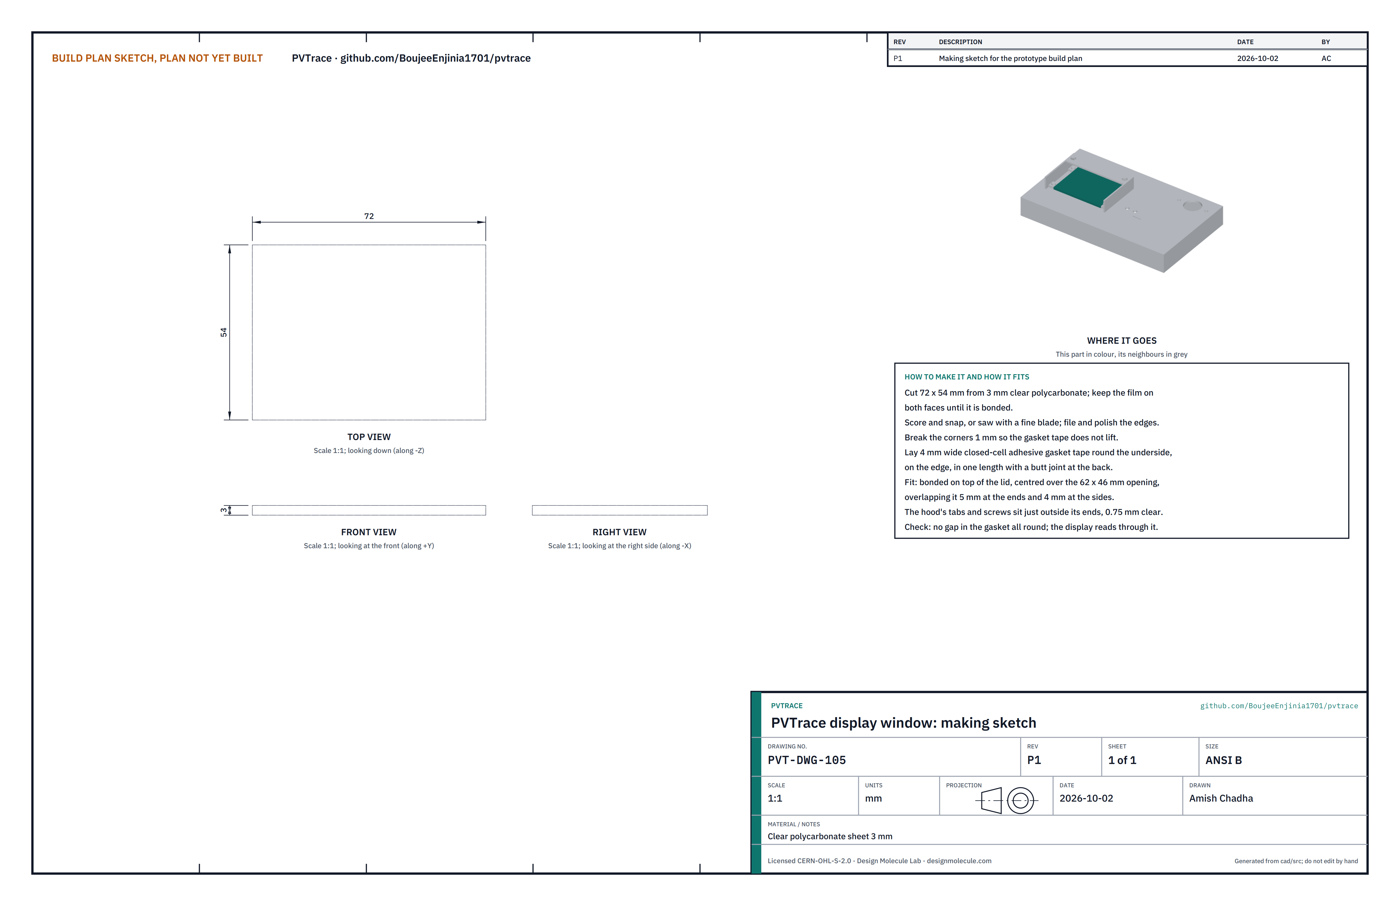
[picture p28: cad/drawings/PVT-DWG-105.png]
Figure 18. Making sketch of the window


*Figure 18. Window making sketch (PVT-DWG-105).*

**What it is and what it is made from.** The clear cover over the display. Clear polycarbonate sheet 3 mm.

**How to make it.**

1. Cut 72 x 54 mm; keep the film on both faces until it is bonded.
2. File and polish the edges; break the corners 1 mm.
3. Lay 4 mm wide closed-cell adhesive gasket tape round the edge of the underside in one length, with the butt joint at the back.

**How it fits the parts next to it.** It is bonded on top of the lid, centred over the opening, overlapping it 5 mm at the ends and 4 mm at the sides (step 8). The display screws sit just outside its ends.

**Check before moving on.** The gasket is unbroken all round; the display can be read through the window.

### 3.7 Sun hood

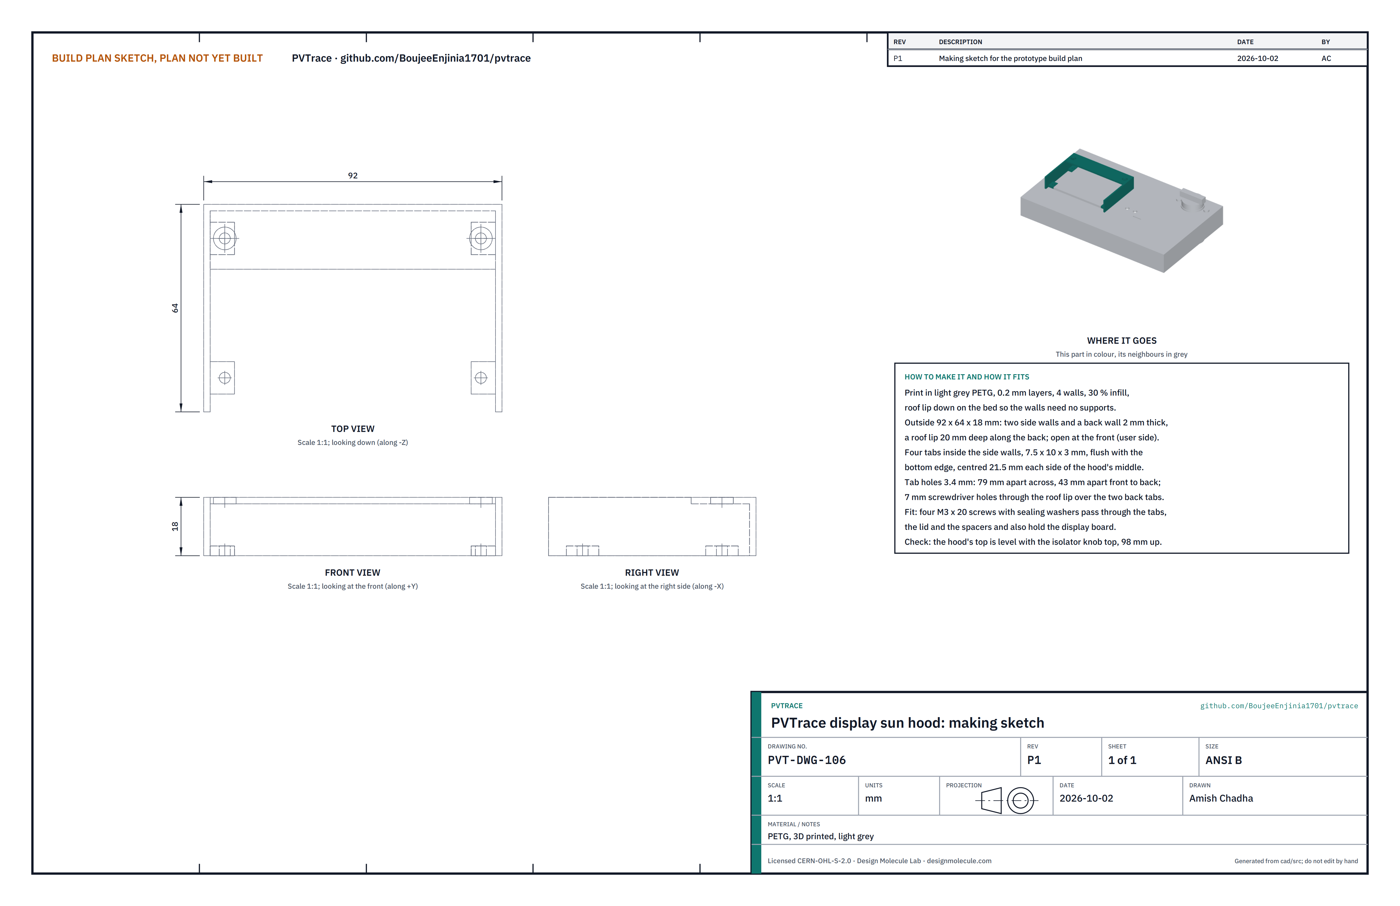
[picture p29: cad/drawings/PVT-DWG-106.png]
Figure 19. Making sketch of the sun hood


*Figure 19. Sun hood making sketch (PVT-DWG-106).*

**What it is and what it is made from.** A three-sided shade with a roof lip over the display, open toward the user. Light grey PETG, 3D printed.

**How to make it.**

1. Print with the roof lip down on the bed: 0.2 mm layers, 4 walls, 30 % infill. Outside 92 x 64 x 18 mm, walls 2 mm.
2. The four tabs inside the side walls, 7.5 x 10 x 3 mm, are flush with the bottom edge, with 3.4 mm holes 79 mm apart across and 43 mm apart front to back.
3. The roof lip has two 7 mm holes over the back tabs, so a screwdriver reaches those screws.

**How it fits the parts next to it.**

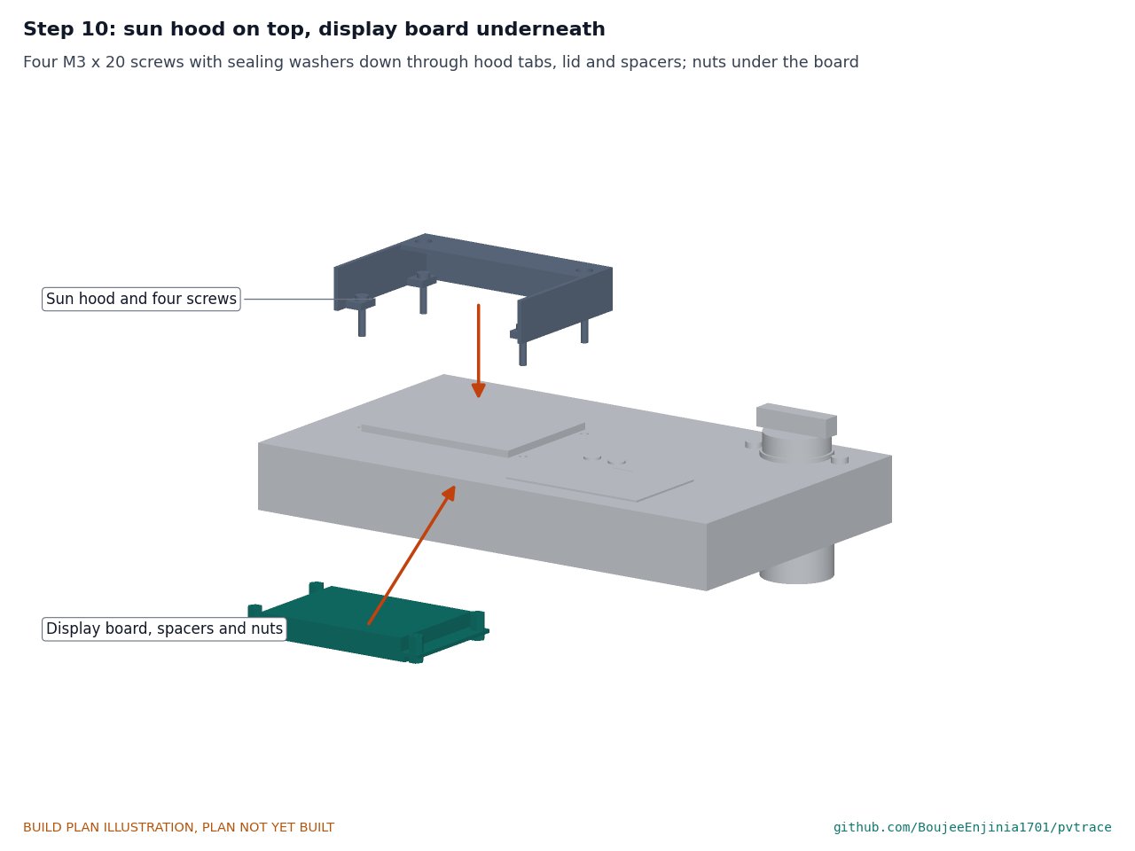
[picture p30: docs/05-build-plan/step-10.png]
Figure 20. Step 10 picture: the hood on top, the display board underneath


*Figure 20. Four M3 x 20 screws pass through the hood tabs, the lid and the spacers; nuts under the display board.*

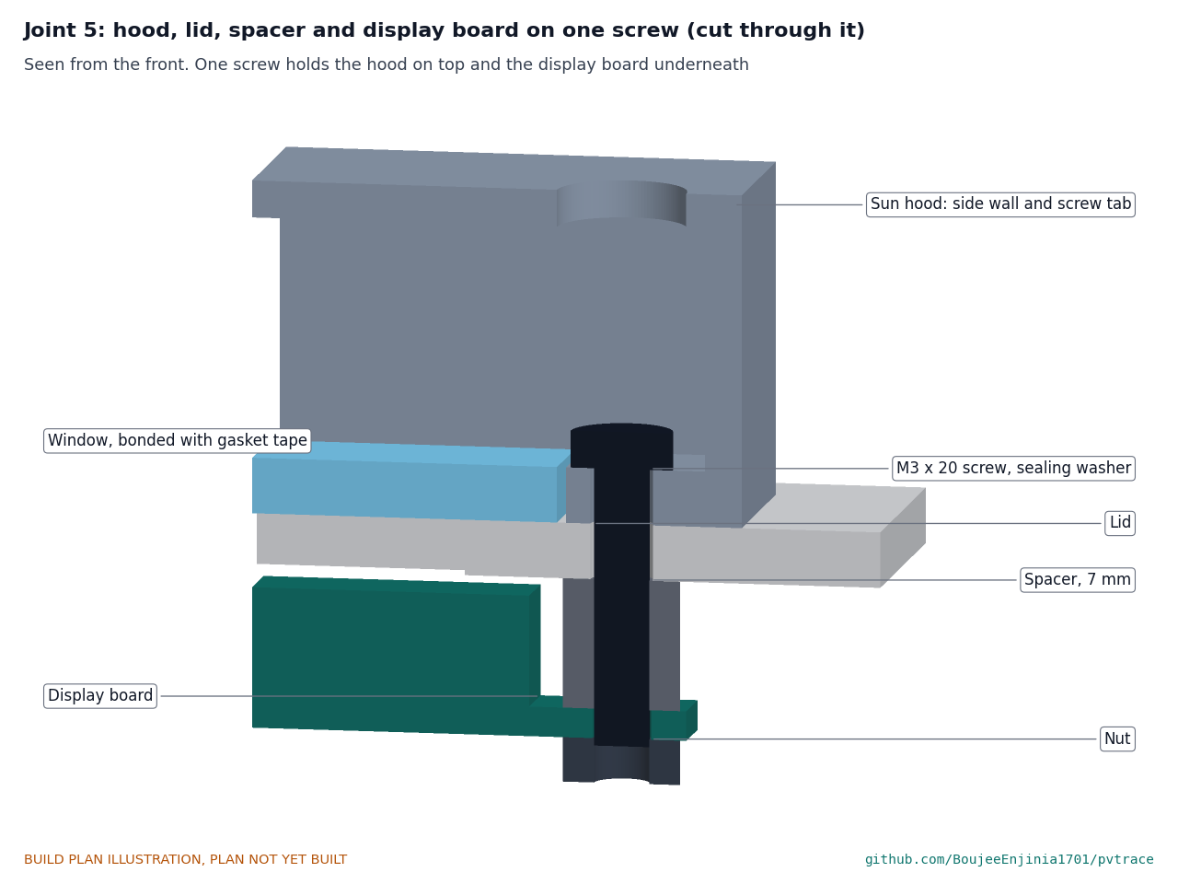
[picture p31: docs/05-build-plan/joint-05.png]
Figure 21. Joint 5: hood, lid, spacer and display board on one screw


*Figure 21. One screw, with a sealing washer under its head, holds the hood on top and the display board underneath.*

The hood stands on the lid round the window. The display board, an 86 x 50 mm ESP32 board with a 2.8 in screen, hangs under the lid on four 7 mm spacers, its screen 1 mm below the lid and centred under the opening. Measure your board's holes before drilling the lid; the model assumes 79 x 43 mm between centres.

**Check before moving on.** The hood's top is level with the isolator knob, 98 mm above the bottom of the case; the display reads through the window with no gap at its edges.

### 3.8 Sensor pod housing

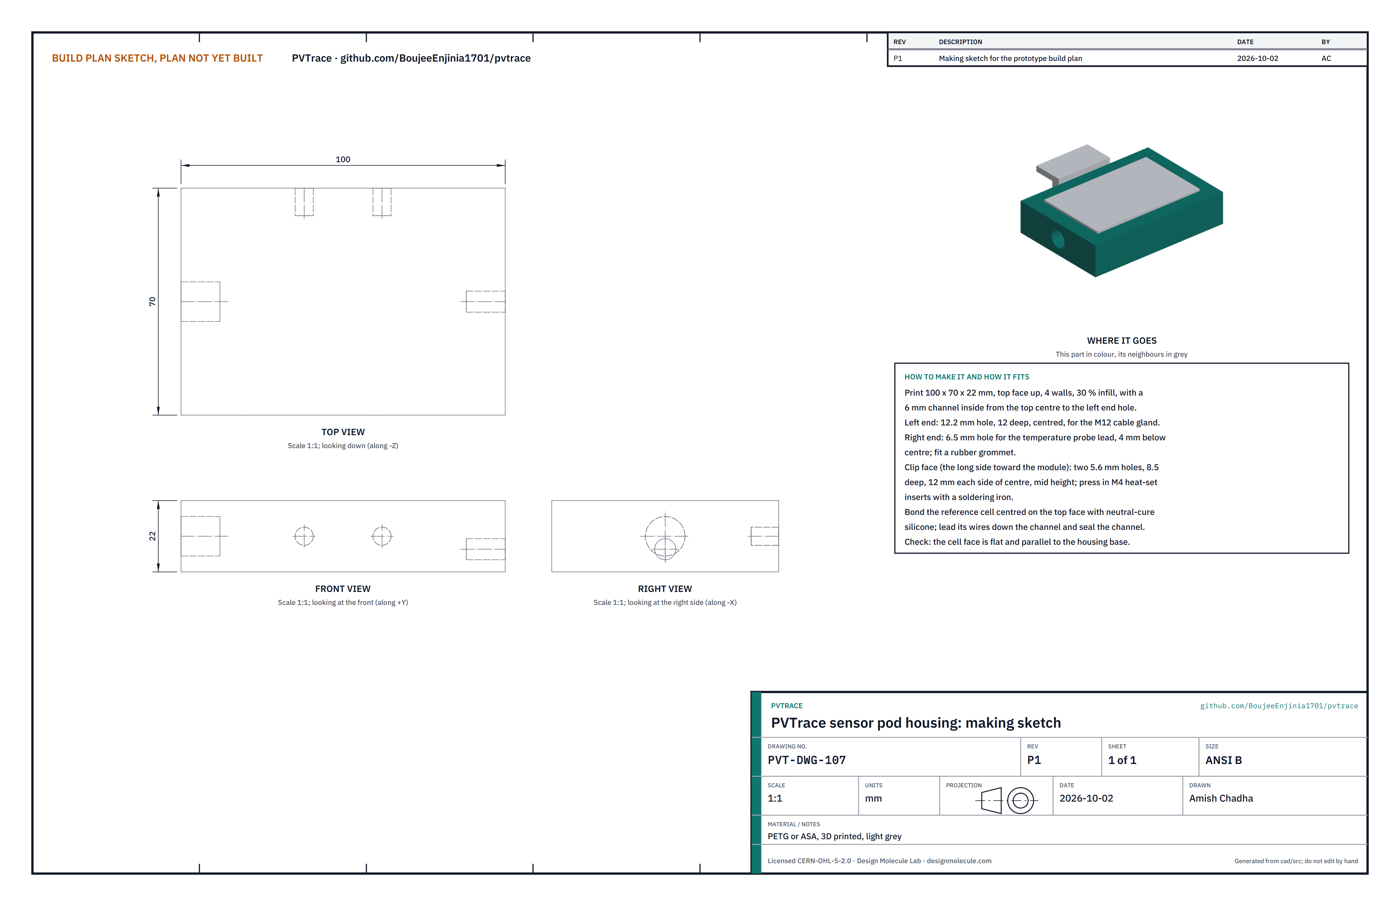
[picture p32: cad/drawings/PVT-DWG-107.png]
Figure 22. Making sketch of the sensor pod housing


*Figure 22. Sensor pod housing making sketch (PVT-DWG-107).*

**What it is and what it is made from.** The block that carries the reference cell on its top face and the cable gland at its left end. Light grey PETG or ASA, 3D printed.

**How to make it.**

1. Print 100 x 70 x 22 mm, top face up, 4 walls, 30 % infill, with a 6 mm wiring channel inside from the centre of the top face to the left end hole.
2. Left end: 12.2 mm hole, 12 mm deep, centred, for the M12 cable gland. Right end: 6.5 mm hole 4 mm below centre for the temperature probe lead; fit a rubber grommet.
3. Clip face (the long side toward the module): two 5.6 mm holes, 8.5 mm deep, 12 mm each side of centre at mid height. Press in M4 heat-set inserts with a soldering iron.
4. Bond the reference cell centred on the top face with neutral-cure silicone; lead its wires down the channel and seal the channel with silicone.

**How it fits the parts next to it.** The clip screws to the clip face (section 3.9). The cable runs through the gland to the left end of the case.

**Check before moving on.** The cell face is flat and parallel to the housing base; the inserts are square to the face.

### 3.9 Sensor pod clip

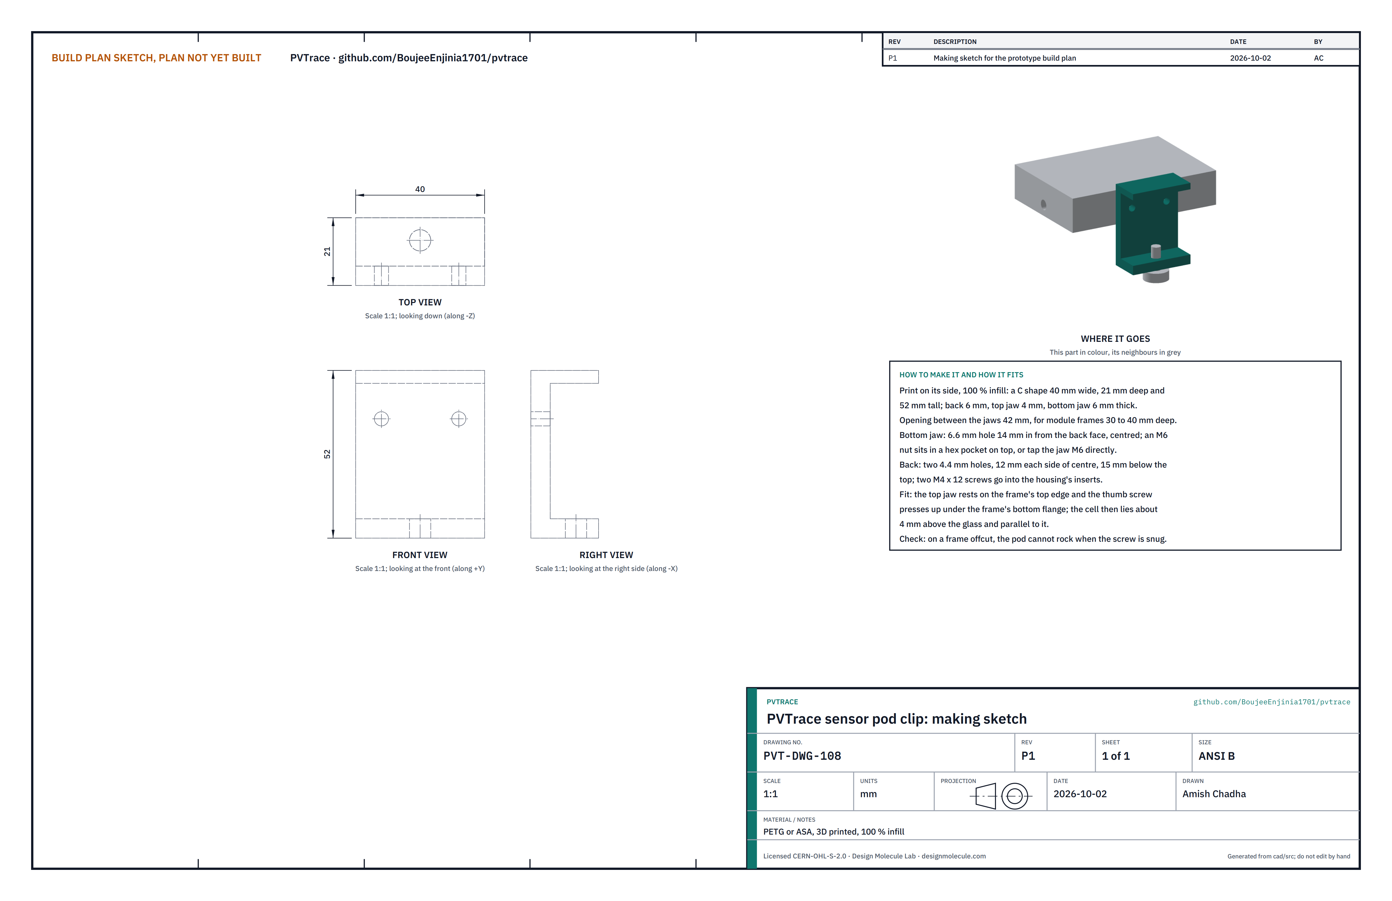
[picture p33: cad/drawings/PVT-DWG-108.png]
Figure 23. Making sketch of the sensor pod clip


*Figure 23. Sensor pod clip making sketch (PVT-DWG-108).*

**What it is and what it is made from.** A C-shaped clamp that grips the edge of the module frame. PETG or ASA, 3D printed at 100 % infill.

**How to make it.**

1. Print on its side: 40 mm wide, 21 mm deep and 52 mm tall; back 6 mm, top jaw 4 mm and bottom jaw 6 mm thick; 42 mm between the jaws.
2. Bottom jaw: a 6.6 mm hole 14 mm in from the back face, centred. Tap it M6, or fit an M6 nut in a hex pocket on its top face.
3. Back: two 4.4 mm holes 12 mm each side of centre, 15 mm below the top.

**How it fits the parts next to it.**

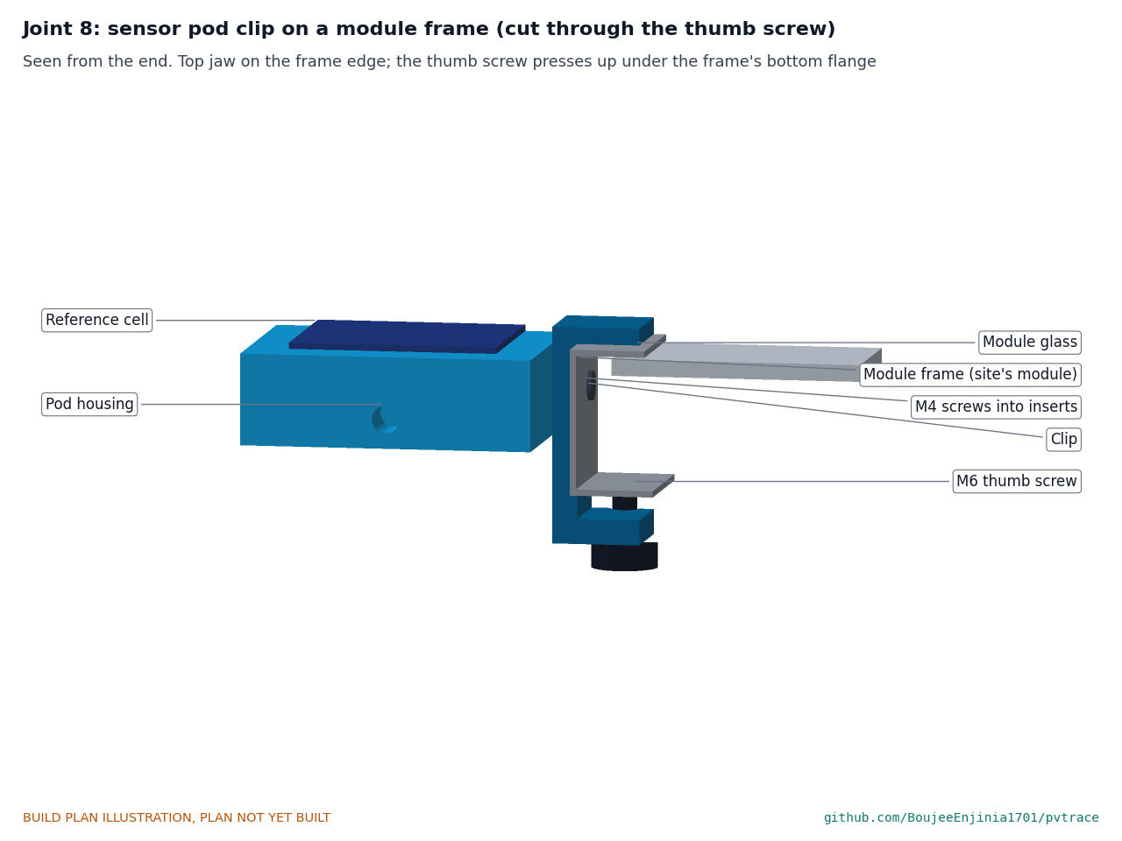
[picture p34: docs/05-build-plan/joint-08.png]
Figure 24. Joint 8: the sensor pod clip on a module frame


*Figure 24. The top jaw rests on the frame's top edge; the M6 thumb screw presses up under the frame's bottom flange.*

Two M4 x 12 screws hold the clip to the housing's inserts. On a frame 30 to 40 mm deep, the cell lies about 4 mm above the glass and parallel to it.

**Check before moving on.** On a frame offcut the pod cannot rock once the thumb screw is snug.

### 3.10 Sensor pod, assembled

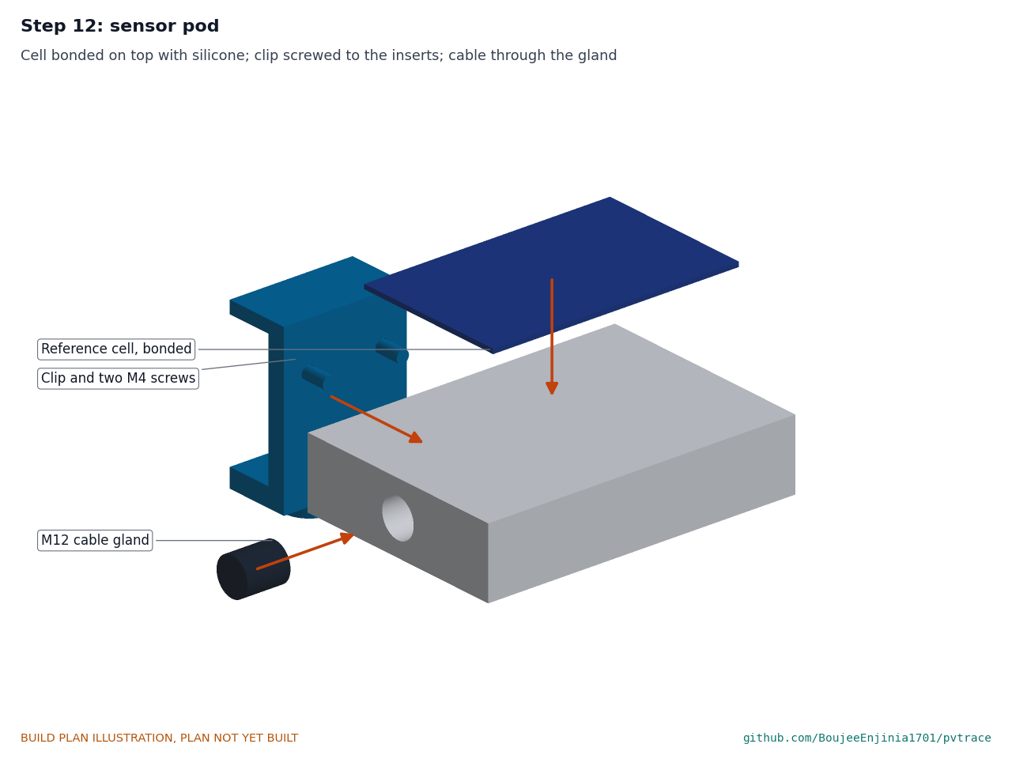
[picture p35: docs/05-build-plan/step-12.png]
Figure 25. Step 12 picture: the sensor pod


*Figure 25. Cell bonded on top, clip screwed to the inserts, cable through the gland.*

### 3.11 Bought components

Buy to specification, not brand. Line numbers are those of the bill of materials.

- **Case (line 1).** IP54 ABS, light grey, about 220 x 130 x 80 mm outside, lid on the large face screwing into four corner pillars, rubber corner bumpers, with two M16 and one M12 cable glands.
- **Display board (line 3).** ESP32 board 86 x 50 mm with a 2.8 in 320 x 240 screen and microSD socket (ESP32-2432S028 class), with an 8 GB card and a 16-bit I2C ADC module (ADS1115 class) for the reference cell.
- **Measurement board parts (line 4).** 4 milliohm 3 W four-terminal shunt, current-sense amplifier (INA240A2 class), 1 Mohm and 39 kohm 0.1 % divider, two-channel 12-bit 100 kS/s ADC (MCP3202 class), 4.096 V reference, protection diodes, perfboard 44 x 56 mm.
- **Load capacitors (line 5).** Three 2200 µF 160 V snap-in electrolytics, about 35 x 60 mm, 105 °C. Measure each one's capacitance with a meter before fitting and use a set that gives at least 6.45 mF together; buy four and fit the best three (one spare, about $6). If no three of the four reach 6.45 mF together, buy more from the same batch.
- **Switches (line 6).** Two 150 V N-channel MOSFETs, about 10 milliohm, TO-220, a gate driver, the 25 x 10 mm bar (section 3.3), insulating pads and bushings.
- **Resistors (line 7).** 22 ohm 50 W aluminium-clad resistor and a 10 kohm 3 W bleed resistor.
- **Fuse (line 8).** 20 A gPV 10 x 38 mm fuse rated 1,000 V DC, in a DC-rated holder no more than 44 x 20 mm on its base.
- **DC isolator (line 9).** Two-pole, 20 A at 250 V DC or more, panel mounting through a hole of about 24 mm with a flange under the panel, body no deeper than 47 mm below the lid.
- **Cell and charger (line 10).** Protected 18650 lithium-ion cell of about 3,000 mAh from a maker that publishes a datasheet; holder; USB-C charger with a temperature cut-off; 5 V boost; protection board.
- **Test leads (line 11).** Two 1 m lengths of 4 mm² double-insulated PV cable, red and black, with brand-matched MC4 connectors from one maker.
- **Sensor pod parts (line 12).** Encapsulated mono-Si reference cell about 80 x 50 mm with its shunt, waterproof DS18B20 probe with a foam shade, M12 cable gland, M6 thumb screw, two M4 heat-set inserts, 3 m cable with a connector.
- **Isolation barrier (line 14).** Four-channel digital isolator (ISO7741 or ADuM1401 class) and a 1 W isolated 5 V to 5 V converter on perfboard 30 x 24 mm.
- **Keypad and status lights (line 18).** A blank three-key membrane switch about 64 x 40 mm with a flat tail and a self-adhesive back, with a printed overlay label; two 3 mm LEDs (green for ready, amber for live DC) in 5.4 mm panel clips; a 6-way lead and header. About $8.
- **USB-C socket (line 17).** Panel mounting, IP65 or better, tethered cap, M16 thread with locknut, 0.3 m lead.
- **Fixings and consumables (line 13).** Five M3 x 5 mm hex nylon standoffs with five M3 x 5 countersunk and five M3 x 4 pan-head screws; four M3 x 20 pan-head screws with sealing washers and nuts, four 7 mm spacers; M3 x 8 screws and nuts for the holders and resistor; eight 6 mm nylon standoffs; two 200 mm cable ties; neutral-cure silicone; 4 mm closed-cell adhesive gasket tape; wire in 4, 2.5, 0.5 and 0.25 mm², ferrules, heat-shrink, labels.

## 4. Putting it together

In each picture the parts already fitted are grey and the part being fitted is in colour, with an arrow showing the way it goes in. Steps 3 to 6 are done on the bench with the plate out of the case.

### Step 1: standoffs into the case floor

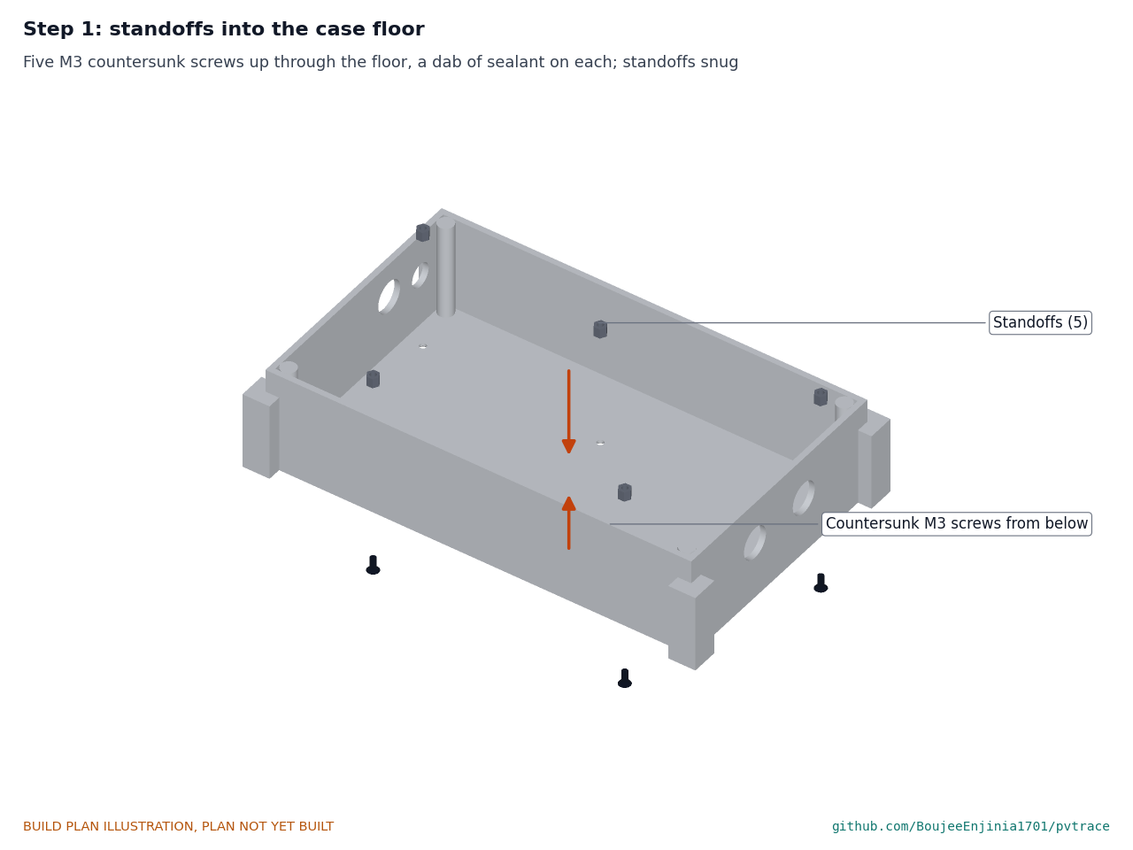
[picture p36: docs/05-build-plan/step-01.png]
Step 1


Five M3 countersunk screws up through the floor into the standoffs, with a dab of sealant on each screw. Snug, not tight; the floor is plastic.

### Step 2: glands and USB-C socket into the ends

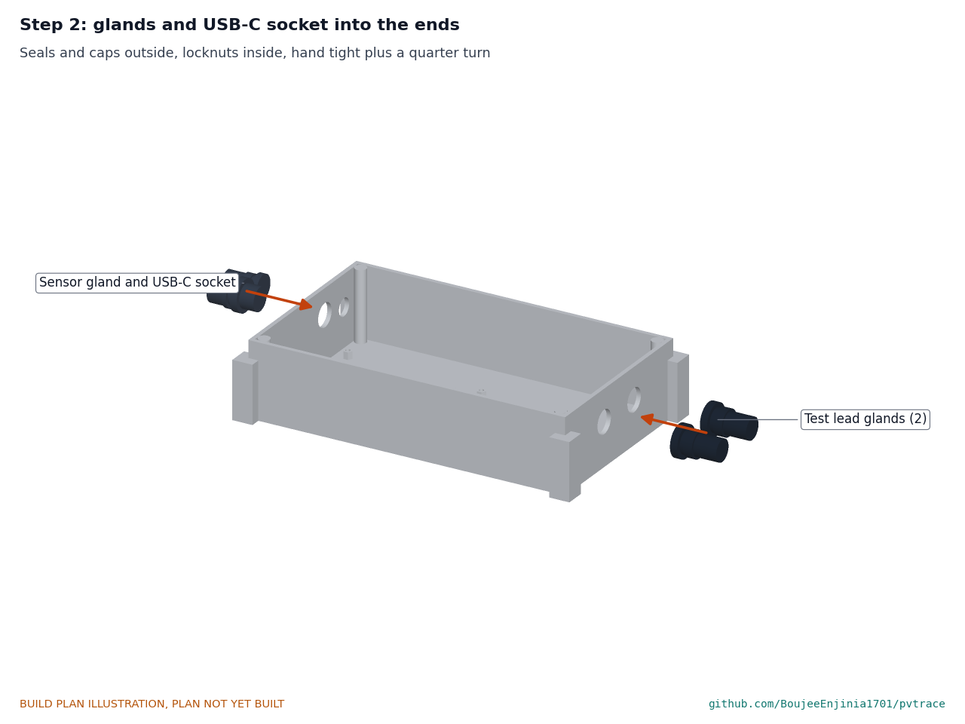
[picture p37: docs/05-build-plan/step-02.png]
Step 2


Seals and caps outside, locknuts inside, hand tight plus a quarter turn. Pass the test leads through their glands now and leave about 150 mm inside; do not tighten the gland caps yet.

### Step 3: MOSFETs onto the bar, bar onto the plate

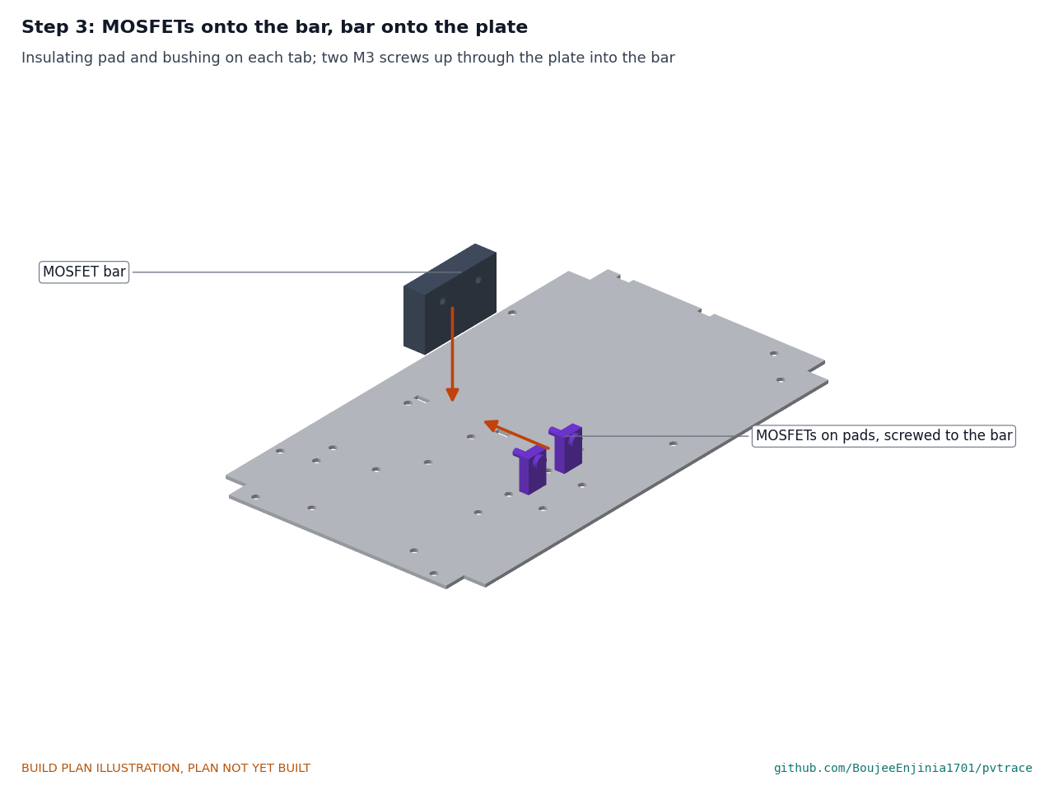
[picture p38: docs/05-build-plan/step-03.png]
Step 3


Each MOSFET on an insulating pad with an insulating bushing under its M3 screw. Then two M3 screws up through the plate into the bar. **Hold point:** each tab reads open circuit to the bar.

### Step 4: discharge resistor, fuse holder and cell holder

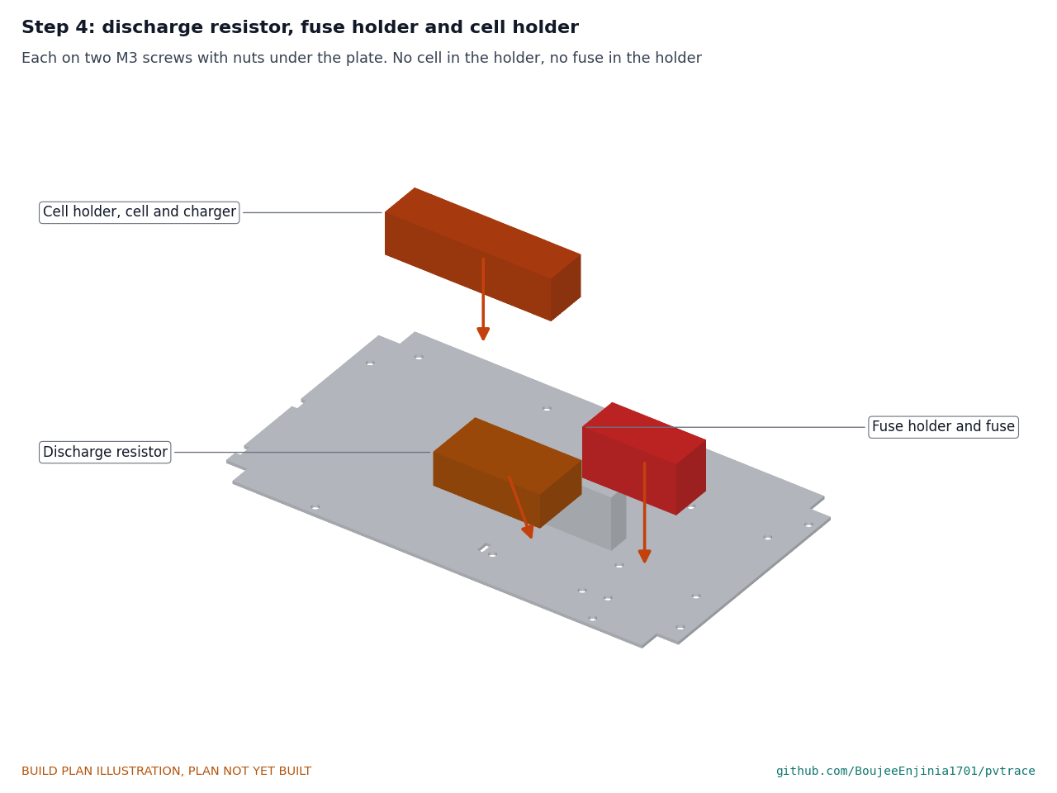
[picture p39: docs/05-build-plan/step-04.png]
Step 4


Two M3 screws each, nuts under the plate. Leave the fuse out of the fuse holder and the cell out of its holder.

### Step 5: measurement and isolation boards

Step 5

Each on four 6 mm nylon standoffs, M3 screws from under the plate.

### Step 6: capacitors and their ties

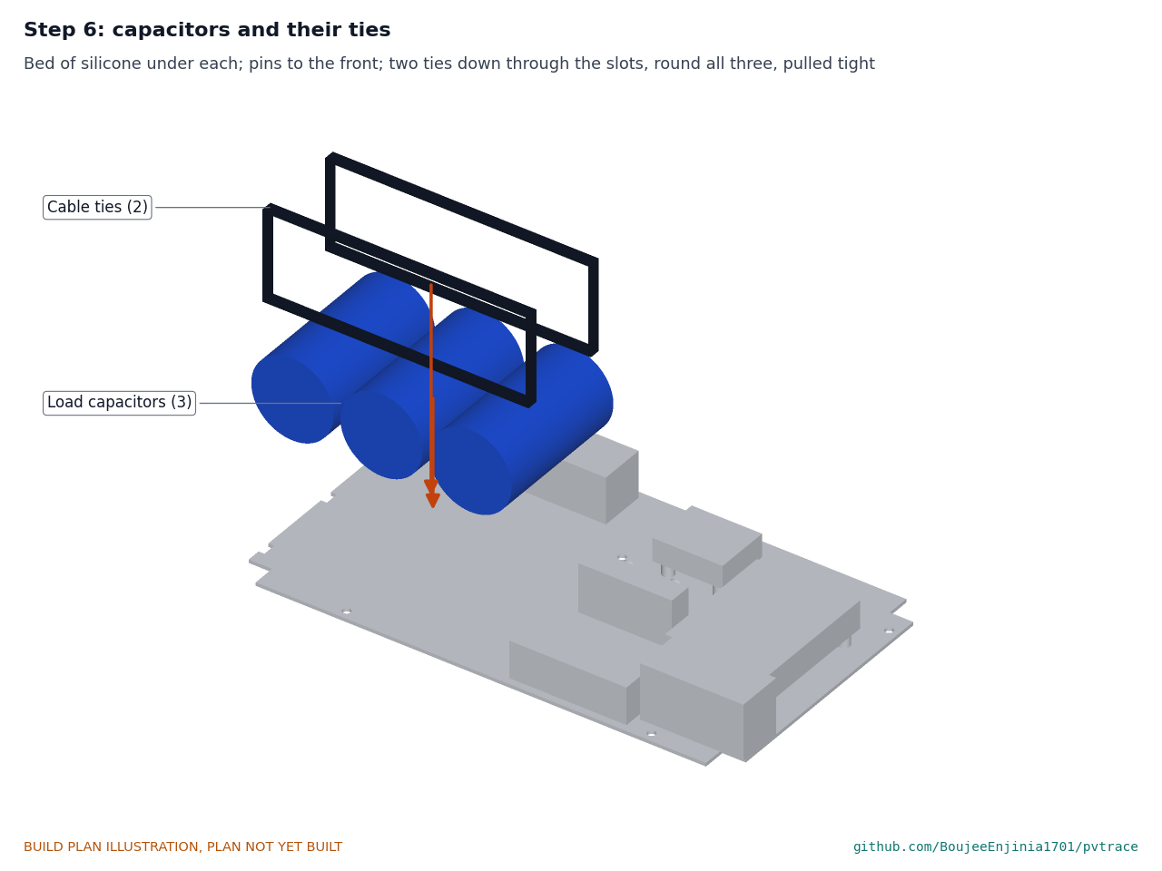
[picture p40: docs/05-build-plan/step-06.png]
Step 6


A bed of silicone under each capacitor, pins toward the front. Two cable ties down through the slots, under the plate and round all three, pulled tight. Let the silicone cure before moving the plate.

### Step 7: plate into the case

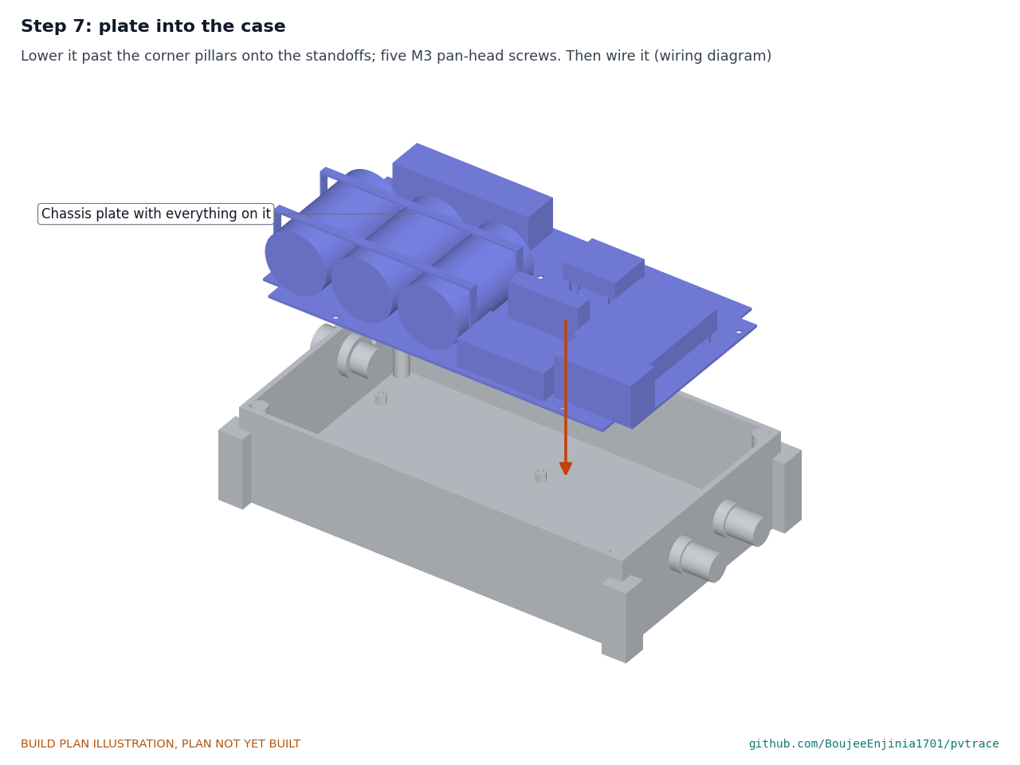
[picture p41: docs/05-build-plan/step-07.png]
Step 7


Lower the plate past the corner pillars onto the standoffs and fit the five M3 pan-head screws. Then wire everything in the body as section 3.4.1 says and tighten the gland caps on the leads and the sensor cable.

### Step 8: window onto the lid

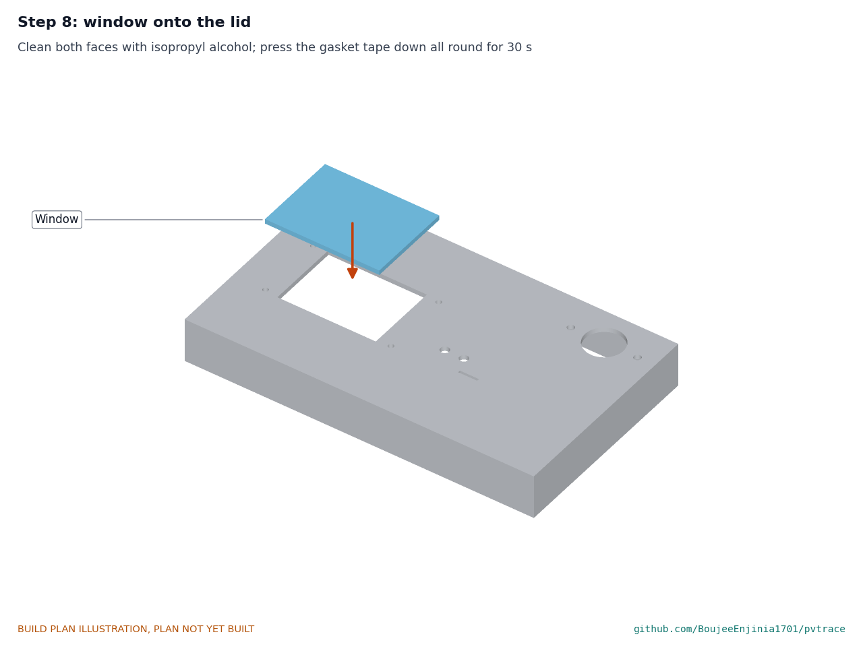
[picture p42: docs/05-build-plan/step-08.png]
Step 8


Clean the lid and the window with isopropyl alcohol. Peel the film from the underside, centre the window over the opening and press the gasket tape down all round for 30 seconds. Peel the top film last.

### Step 9: DC isolator, keypad and status lights into the lid

Step 9

The body up from below until its flange meets the lid; the maker's two screws down from above; then the knob and handle. Set it to open (OFF). Clip the two status lights into their holes with their nuts under the lid. Peel the backing from the keypad, pass its tail through the slot and press it flat for 30 seconds.

### Step 10: sun hood on top, display board underneath

Step 10

Hold the display board and its four spacers under the lid, screen up, and set the hood on top. Four M3 x 20 screws with sealing washers go down through the hood tabs, the lid and the spacers; nuts under the board. Use the holes in the roof lip for the two back screws.

### Step 11: close the case

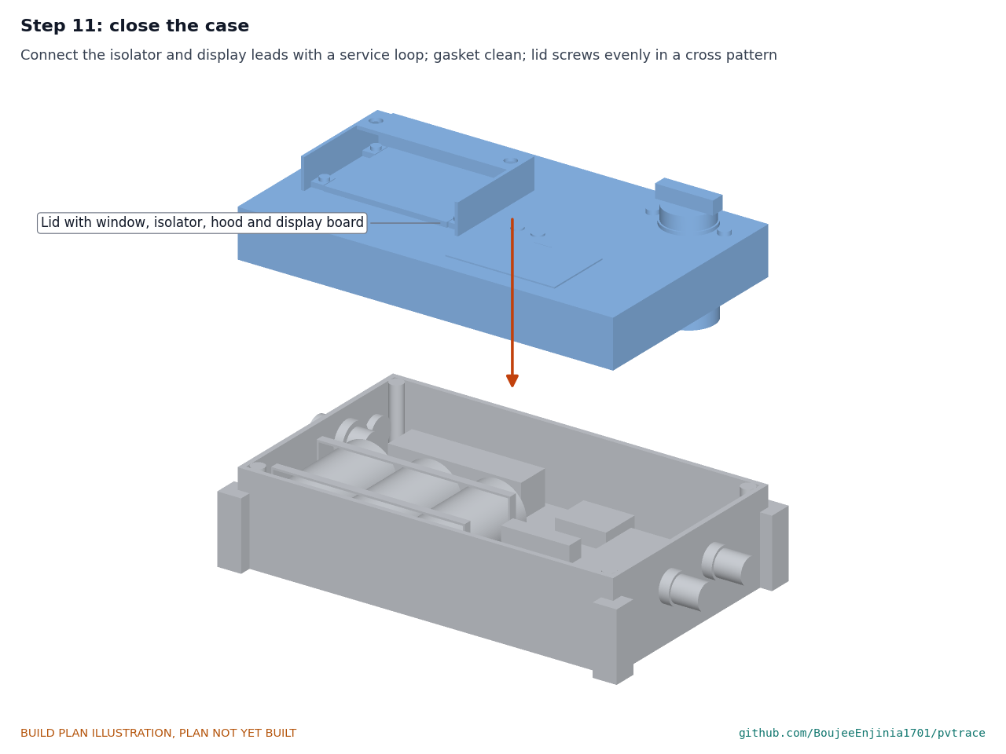
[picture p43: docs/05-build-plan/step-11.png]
Step 11


Connect the isolator and display board leads to the body with their service loops. Check the gasket is clean and no wire lies across it. Close the lid and tighten its screws evenly in a cross pattern. **Hold point:** safety stop S2 in section 6.

### Step 12: sensor pod

Step 12

Bond the cell on top with silicone and let it cure. Screw the clip to the inserts with two M4 x 12 screws, fit the thumb screw, and pass the cable through the gland. Plug the cable into the case's sensor lead.

## 5. First checks

These are the checks a TRL 4 test report would record; this plan only lists them. Requirement numbers are those of PVT-REQ-001.

*Table 2. First checks.*

| Check | Requirement | How | Pass when |
| --- | --- | --- | --- |
| Isolation | R11, isolation design | Insulation tester at 500 V DC between the two test leads joined together and the USB-C socket shell, isolator closed, no cell | Above 100 Mohm |
| MOSFET tabs | R11 | Meter from each MOSFET tab to the bar | Open circuit |
| Polarity and over-voltage refusal | R1, R11 | Bench supply, current limit 0.5 A: reversed leads, then 30 V, then a supply set above the over-voltage threshold in firmware | Refuses reversed polarity and over-voltage; the load never connects |
| Sweep on a bench | R3, R4 | Bench supply at 30 V, current limit 2 A, behind a 3 ohm 50 W resistor in place of a module | Sweep time and pair count match the calculation for that source |
| Discharge | R11 | Charge to 30 V on the bench supply, sweep, time the fall with a meter on the capacitor pins; then with the controller off, time the passive fall | Below 30 V within 2 s; passive fall follows the 10 kohm bleed |
| Opening current | R11 | Current trace at the end of a bench sweep | The load switch opens below 0.5 A |
| Charging | R14 | USB-C charger into the socket, case closed, isolator open | Charge current flows; the charger stops at full charge and below its temperature limit |
| Battery life | R14 | Sweep every 20 s from full charge | 8 h or 200 sweeps |
| Seal | R13 | Look at the window gasket, gland seals and lid gasket under a lamp | Every seal evenly squeezed, no gaps (the spray test comes later) |
| Mass and size | R12 | Weigh with leads and pod; measure over bumpers, knob and hood | 1.5 kg or less (1.49 kg estimated); 250 x 150 x 100 mm or less |
| Pod clip | R7 | Clip to frames 30 and 40 mm deep; angle finder on the cell and on the glass | No rocking; the cell within 1 degree of the glass |

## 6. Safety stops

Stop at each point. Carry on only when everything listed is true.

- **S1. Before the cell comes into the workshop.** Cell voltage about 3.0 to 4.2 V; no swelling, dents or leaks; a datasheet from its maker. A charging spot ready on a non-flammable surface (ceramic tile or steel tray) with a fire extinguisher for electrical fires within reach.
- **S2. Before the fuse goes in or the isolator is closed.** With no cell and the isolator open: the isolation check of section 5 passes; each MOSFET tab reads open to the bar; the 10 kohm bleed reads across the capacitor pins; the capacitors read below 1 V.
- **S3. Before the cell goes in.** The cell holder polarity matches the protection board, checked with a meter, not by wire colour; the charger's temperature cut-off is fitted and not bypassed.
- **S4. Before any source is connected to the test leads.** Bench supply only, current limit 2 A or less, voltage 30 V or less. The polarity, discharge and opening current checks of section 5 pass on the bench before the next stop.
- **S5. Before the first connection to a real module.** Use a small 36-cell module first (about 22 V). Mate and unmate the MC4 connectors only with the isolator open, never under load, and use brand-matched connectors from one maker. Gloves and eye protection.
- **S6. Before modules above 50 V or two modules in series.** The over-voltage refusal works at the bench; the string's cold open-circuit voltage is below 100 V. Never connect to a string of an installed system unless the owner has isolated it from the inverter.
- **S7. Before the case is opened.** Leads disconnected; isolator open; the display reads below 30 V; wait 60 s; a meter on the capacitor pins reads below 30 V before any hand goes inside.
- **S8. Charging.** Isolator open, in shade, on the charging spot, attended, between 0 and 45 °C. Never leave the tracer charging in a hot vehicle.

## 7. Tools, skills and workspace

**Tools.** Bench drill or a drill in a stand; drills 2 to 6.6 mm; step drill to 20 mm; countersink; M3 and M6 taps and tap wrench; hacksaw and fine-tooth saw; flat and needle files; deburring tool; steel rule, square, calipers and scriber; masking tape; 3D printer with a bed of at least 100 x 100 mm that prints PETG; soldering iron with a heat-set insert tip; wire strippers, ferrule crimper and heat gun; multimeter; bench power supply with an adjustable current limit (0 to 30 V, 0 to 3 A); a 3 ohm 50 W resistor for bench sweeps; an insulation tester with a 500 V range (borrowed is fine); scale to 2 kg; angle finder.

**Skills.** No certified trade is needed for the build. Basic drilling, tapping and filing; 3D printing; through-hole soldering and crimping; safe use of a bench supply; care with lithium cells. The first connection to a live module (stop S5) should be made by, or with, someone who has worked safely on PV systems before; modules are live in light and cannot be switched off.

**Workspace.** A bench about 1.2 x 0.6 m with good light; the drilling corner kept apart from the electronics so swarf stays off the boards; a ventilated place for the printer; the charging spot of S1; and for stop S5, a shaded outdoor bench next to the module, with the module flat on the ground or on a low stand.

**Personal protective equipment.** Safety glasses for drilling, cutting and soldering; gloves when handling module frames and glass; no gloves near a turning drill.

## 8. Where the numbers come from

- Model and constructability checks: `cad/src/model.py` (`python cad/src/model.py --check`, 206 checks); STEP and STL exports in `cad/step/` and `cad/stl/`.
- Pictures: `cad/src/build_plan_media.py`, using `.kit/build_views.py`; written to `docs/05-build-plan/` and `cad/drawings/PVT-DWG-101` to `PVT-DWG-108`.
- General arrangement: `cad/drawings/PVT-DWG-001.pdf`, Rev P4.
- Calculations: `docs/04-calcs/01-sizing.md` (PVT-CAL-001 v0.5) and `docs/04-calcs/sizing.py`: sweep, discharge, heat, battery, mass and cost.
- Bill of materials: `bom/bom.csv`.
- Decisions: `docs/decisions/0003-design-for-construction.md` (PVT-DDR-003), with PVT-DDR-001 and PVT-DDR-002; the design decisions register `docs/06-design-decisions.md` (PVT-DEC-001).
- Requirements: `docs/03-requirements.md` (PVT-REQ-001 v0.7).

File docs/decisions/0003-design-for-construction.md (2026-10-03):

---
doc_id: PVT-DDR-003
title: PVTrace design for construction
project: PVTrace
doc_type: Design decision record
version: "0.3"
status: Draft
date: '2026-10-02'
author: Amish Chadha
license: CERN-OHL-S-2.0
revisions:
- version: "0.1"
  date: '2026-10-01'
  author: Amish Chadha
  change: Changes that make the concept physically buildable, with the reason for each; made under Amish's 2026-09-30 instruction to make the design physically buildable; open for his review
- version: "0.2"
  date: '2026-10-02'
  author: Amish Chadha
  change: Accepted by Amish on 2026-10-02, including the recommendations for A1 and A2
- version: "0.3"
  date: '2026-10-02'
  author: Amish Chadha
  change: "Cost, mass margin and requirement counts updated for the decisions of 2026-10-02 (keypad, LEDs, capacitor selection)"
---

# 0003: Design for construction

- **Date:** 2026-10-01
- **Status:** accepted. Amish, 2026-10-02: "i approve your recommendations for all 555 open decisions." This covers every change in Tables 1 and 2, as made, and the recommendations for A1 and A2 in Table 3, which are now decided as recommended and recorded in the design decisions register (PVT-DEC-001).

## Context

On 2026-09-30 Amish asked for every repo to have an illustrated build plan and wrote: "If you are realising that the design cannot be built as per concept - fix the design assumptions to match and be physically feasible as you draw the illustrations." The TRL 3 model of PVT-DDR-001 and PVT-DDR-002 showed what PVTrace does, but it was a massing model: every internal part stood on the case floor with no fixing, the display board and window floated under and in the lid, the sun hood had nothing to screw into, and the cable glands sat outside the end walls with no holes or nuts. Checking the model with build123d, with the bought case's corner pillars and the glands' inside locknuts added, found the clashes listed below.

The changes keep what the instrument does: the same case, rating, load, isolation barrier, display, sun hood, sensor pod, leads and controls, in the same places. Nothing here changes the pitch. Every change is in `cad/src/model.py`, which now runs 183 constructability checks (`python cad/src/model.py --check`): no two parts overlap; every part touches what holds it; parts that must not touch keep their stated clearance; a screwdriver reaches every plate and hood screw from above; the lid lifts straight off with everything it carries; and the envelope stays inside R12. All 183 pass.

## Decision

*Table 1. Changes made to the model, the BOM and the calculations.*

| # | Problem in the concept | Change made | Why this way |
| --- | --- | --- | --- |
| C1 | The cable glands were drawn outside the end walls with no holes through the walls and no inside locknuts. With real M16 locknuts (about 22 mm across corners) the front lead gland's nut would have overlapped the fuse holder by 1 mm. | 16.2 mm holes for the two lead glands and 12.2 mm for the sensor gland, each with its locknut inside. The lead glands move from 20 to 18 mm each side of the centre line; the sensor gland moves from 35 to 45 mm toward the back. | Gives the 2 mm clearance from nut to fuse holder that a spanner needs, and leaves room on the left end for the USB-C socket (C10). |
| C2 | The window was the same size as the lid opening and sat in it with nothing to bond to. | A 72 x 54 x 3 mm polycarbonate window bonded on top of the lid with closed-cell adhesive gasket tape, over a smaller 62 x 46 mm opening. | A 4 to 5 mm bond land all round seals the opening (IP54) without machining a recess in a 3 mm lid. The opening still shows the whole 2.8 in display. |
| C3 | The sun hood had no fixing. The BOM named four M3 screws, but the hood's 2 mm walls cannot take a screw. | Four tabs, 7.5 x 10 x 3 mm, inside the side walls at the lid surface, each with a 3.4 mm hole. The hood is 4 mm wider inside (88 mm, 92 mm outside) so the screws clear the window, and the roof lip has two 7 mm holes so a screwdriver reaches the back screws. | The hood keeps its height (top at 98 mm, level with the isolator knob), its open front and its 20 mm roof lip. |
| C4 | The display board floated under the lid with no fixing, and its envelope (90 x 62 mm) did not match the ESP32-2432S028 class board (86 x 50 mm). | The board is modelled at its real size and hangs under the lid on four 7 mm spacers. The hood's four M3 x 20 screws pass through the hood tabs, the lid and the spacers and are nutted under the board. | One set of four screws holds the hood and the board, so the lid needs only four small holes near the window, sealed by washers under the screw heads. The display glass sits 1 mm below the lid. |
| C5 | Every internal part stood on the case floor with no fixing, and the boards had no standoffs. | A 1.5 mm polycarbonate chassis plate, 212 x 122 mm, on five 5 mm nylon standoffs held by countersunk M3 screws through the floor. Every internal part is screwed to the plate; the measurement and isolation boards stand on 6 mm nylon standoffs. New BOM line 16. | Only five holes in the IP54 floor; the plate is an insulator, so it adds no conductive path between the PV side and the controller side; and the whole electronics fit-out is built on the bench and lowered in as one unit. |
| C6 | A bought IP54 case of this size has its lid screws in four moulded corner pillars, which the concept did not show. The first capacitor overlapped the front left pillar. | Corner pillars added to the model. The capacitor bank moves 2 mm toward the left end and 6 mm toward the back; the plate has 10 x 10 mm corner notches; the fuse holder is specified at 44 mm long (was 46) and moves 2.5 mm toward the front. | Clears every pillar by at least 1 mm without changing the bank's place in the case. |
| C7 | The three capacitors (75 g each) lay on the floor with no hold-down. | A bed of neutral-cure silicone under each capacitor and two cable ties round the whole bank, passing down through 2.5 x 6 mm slots in the plate at both ends of the bank. Pins face the front, toward the discharge resistor. | Holds the bank without a printed cradle, which had no room beside the MOSFET bar; keeps the capacitor pins on the PV side, away from the USB-C socket. |
| C8 | The MOSFET bar, the DC isolator and the other parts had no fixings. | The MOSFET bar (25 x 10 mm aluminium flat bar, 40 mm long) is tapped M3 on its bottom and back faces; the MOSFETs sit on insulating pads with insulating bushings. The isolator is modelled with its maker's mounting flange under the lid and two screws from above. Resistor, fuse holder and cell holder each take two M3 screws through the plate. | Every fixing is one a maker can fit with hand tools; the MOSFET tabs, live at PV voltage, stay insulated from the bar. |
| C9 | Raised onto standoffs, the measurement board would have met the lead glands' locknuts and passed under the isolator body with no clearance check. | The board is turned 90 degrees (44 x 56 mm) and centred 76 mm right of centre, 2 mm toward the back. | Clears the locknuts by 1 mm, the MOSFET bar by 4 mm and the isolator body by 2.5 mm. |
| C10 | R14 calls for USB-C charging, but no port passed through the case, so the case would have to be opened to charge. | A panel-mount IP65 USB-C socket with a tethered cap and an M16 locknut in the left end, 87 mm from the front face and 34 mm up, wired to the charger on the controller side. New BOM line 17. | Charging with the case closed keeps the IP54 seal and the isolator open, as the safety notes require. The socket is on the controller side of the barrier, as the isolation design intends. |
| C11 | The sensor pod's frame clip was a solid block with no way to grip a module frame, and the pod had no cable entry. | A printed C-clip with a 42 mm opening and an M6 thumb screw in its lower jaw, for frames 30 to 40 mm deep, screwed to the housing by two M4 screws into heat-set inserts. An M12 cable gland on the housing's left end, a grommet for the probe lead. The reference cell is read by a 16-bit I2C ADC module on the controller side (BOM line 3). | The top jaw sits on the frame's top edge, so the cell lies about 4 mm above the glass and parallel to it. The concept did not say how the cell is read; see A1. |

*Table 2. Knock-on changes.*

| Item | Change | Reason |
| --- | --- | --- |
| Cost | BOM lines 1 to 4, 12, 13 and 15 respecified; lines 3, 12 and 13 repriced (+$6); new lines 16 (+$3) and 17 (+$5). Estimated cost USD 178 at the time of this record; USD 192 (USD 27 over the USD 165 target) after the keypad, LEDs and a spare capacitor added on 2026-10-02 (PVT-CAL-001 v0.5). | Parts added for construction. |
| Mass | 1.49 kg (was 1.43 kg): chassis plate 45 g, USB-C socket 8 g, window corrected to 16 g, hood 17 g. R12 (1.5 kg) is still met, with about 14 g to spare [PVT-CAL-001 section 7]; the keypad and LEDs (8 g) reduce the margin to about 6 g. | The plate is 1.5 mm, not 2 mm, to keep R12. |
| Drawing | PVT-DWG-001 Rev P3; making sketches PVT-DWG-101 to 108 added; concept blueprint PVT-DWG-010 Rev P4. | Follows the model. |
| Documents | PVT-CAL-001 v0.3 (mass, cost), PVT-REQ-001 v0.5 (R12, R17), PVT-PRC-001 v0.5 (components, key numbers). No requirement changed status except R17, now reported against the value-engineering target. | Follows the model. |
| Electrical and thermal | Unchanged: the sweep, discharge and heat calculations do not depend on how the parts are fixed. The discharge resistor now sits on a plastic plate rather than the floor; its free-air rating is to be confirmed when bought (design decisions register). | |

*Table 3. Items proposed, then accepted by Amish as recommended on 2026-10-02.*

| # | Question | Options | Recommendation |
| --- | --- | --- | --- |
| A1 | Which side of the isolation barrier reads the sensor pod. The pod is handled and clipped to a module frame that may be earthed. | (a) controller side, through its own 16-bit ADC module (+$3, as modelled); (b) PV side, through a second ADC on the measurement board, which would put the pod at PV potential. | (a): the pod stays at the safe, low-voltage side, as the USB port does. **Accepted 2026-10-02.** |
| A2 | The R12 mass margin is about 14 g on estimated masses. | (a) accept and weigh the prototype at TRL 4; (b) find mass now (for example a thinner pod housing or shorter leads). | (a). **Accepted 2026-10-02.** |

## Consequences

- `design_state: constructable` in `project.yaml`. The build plan PVT-BLD-001 shows every component and step in pictures generated from the model (`cad/src/build_plan_media.py`); open items are in the design decisions register PVT-DEC-001.
- With A1 and A2 accepted, the sensor pod is read on the controller side through its own 16-bit ADC, and the prototype is weighed at TRL 4 against R12.
- Requirement status: as recorded on 2026-10-01: three not met (R3, R13, R16), two at risk (R7, R8), two not verifiable at TRL 3 (R6, R9), nine met. On 2026-10-02, R3 became met on paper with the selected capacitor bank (two not met, ten met), and R17 is USD 27 over the value-engineering target.
- The photoreal renders (`media/render-*.png`), `media/card.png` and `media/social-preview.png` and the appearance model `cad/src/product_model.py` show the concept internals and the narrower hood. They need updating on Amish's Mac, where Blender is.
- The case, display board, isolator, fuse holder and USB-C socket are chosen at TRL 4; their sizes and fixing patterns must be checked then and the drawings moved to suit.

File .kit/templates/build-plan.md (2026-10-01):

---
doc_id: PRJ-BLD-001
title: Project prototype build plan
project: Project name
doc_type: Build plan
version: "0.1"
status: Draft
date: YYYY-MM-DD
author: Amish Chadha
license: CERN-OHL-S-2.0
revisions:
  - version: "0.1"
    date: YYYY-MM-DD
    author: Amish Chadha
    change: First build plan; design made constructable
---

# Project prototype build plan

**Plan, not yet built.** How to build the first proof-of-concept prototype, component by component. Building and testing to it is TRL 4 work. Decisions still to be made are kept in the design decisions register (`docs/06-design-decisions.md`), not here.

## 1. What you are building

Every component, pulled apart and numbered in build order

One short paragraph: what the prototype is, how many components, which are made and which are bought, and the main ways they are made.

## 2. What changed to make it buildable

| Component | The concept had | The buildable design has | Why |
| --- | --- | --- | --- |

## 3. Making the components

### 3.1 Component name

Making sketch

**What it is and what it is made from.**

**How to make it.**

1. Mark out ...
2. Cut ...

**How it fits the parts next to it.**

Close-up of the joint

**Check before moving on.**

## 4. Putting it together

### Step 1: ...

Step 1

## 5. First checks

| Check | Requirement | How | Pass when |
| --- | --- | --- | --- |

## 6. Safety stops

## 7. Tools, skills and workspace

## 8. Where the numbers come from

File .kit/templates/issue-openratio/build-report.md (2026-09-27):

---
name: Build report
about: Tell us what happened when you built, printed or tested part of this design
title: "Build report: "
labels: build-report
---

This is a research and educational prototype, not a medical device. It is a TRL 3 concept and is not released for fabrication. If you build any part of it, you do so at your own risk. Reports help everyone.

**What you built** (part, sub-assembly or test)

**Materials, tools and settings**

**What worked**

**What did not work, with photos or measurements if you have them**

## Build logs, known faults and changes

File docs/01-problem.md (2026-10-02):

---
doc_id: PVT-PRB-001
title: PVTrace problem statement
project: PVTrace
doc_type: Problem statement
version: "0.5"
status: Draft
date: '2026-10-02'
author: Amish Chadha
license: CERN-OHL-S-2.0
revisions:
- version: "0.1"
  date: '2026-09-25'
  author: Amish Chadha
  change: Initial scaffold
- version: "0.2"
  date: '2026-09-25'
  author: Amish Chadha
  change: Problem with cited evidence, users, context, constraints, prior work and co-design checklist for TRL 2
- version: "0.3"
  date: '2026-09-25'
  author: Amish Chadha
  change: Budget constraint notes the proposed $165 (PVT-DDR-001); WEEE coverage of PV panels confirmed against the directive text
- version: "0.4"
  date: '2026-09-25'
  author: Amish Chadha
  change: Recommendations accepted by Amish (DDR-002)
- version: "0.5"
  date: '2026-10-02'
  author: Amish Chadha
  change: First co-design partner type decided on 2026-10-02 (PVT-DEC-001, item 5)
---

# PVTrace problem statement

Installers and reuse programs judge solar modules by eye or by a single open-circuit voltage reading, which misses the faults an IV curve shows at once: a shaded or cracked substring, a failed bypass diode, high series resistance from corroded connections, or plain power loss. The instrument that shows these, a field IV curve tracer, is priced for utility-scale commissioning crews, so small installers, repair shops and second-life panel programs go without. A single-module commercial kit such as the Seaward PV210 lists at $3,799 ([Transcat](https://www.transcat.com/seaward-pv210-solar-kit-389a912)).

## Why it matters now

- **Volume.** Global PV capacity rose to nearly 3 TW at the end of 2025, with about 698 GW installed in that year alone ([IEA PVPS Snapshot 2026](https://iea-pvps.org/snapshot-reports/snapshot-2026/)). Panel waste could reach 78 million tonnes by 2050 ([IRENA and IEA PVPS, 2016](https://www.irena.org/publications/2016/Jun/End-of-life-management-Solar-Photovoltaic-Panels)).
- **Early removal.** About 70 % of modules are decommissioned before the end of their 25 to 30 year design life ([Huang and Long, *Nature Communications*, 2026](https://www.nature.com/articles/s41467-026-69171-z)), so many removed modules still work.
- **Slow degradation.** Across nearly 2,000 field measurements, the median power loss is about 0.5 % per year ([Jordan and Kurtz, 2013](https://onlinelibrary.wiley.com/doi/abs/10.1002/pip.1182)); a 10-year-old module in good condition typically keeps most of its rated power.
- **Unknown quality in second-hand trade.** Refurbished modules exported to secondary markets show 10 to 20 % power degradation and inconsistent quality, and most of the projected PV waste in Africa and the Middle East will come from imports ([Huang and Long, 2026](https://www.nature.com/articles/s41467-026-69171-z)). Australian researchers propose a resale certification with simple grades to build buyer confidence ([UniSA, 2025](https://unisa.edu.au/media-centre/Releases/2025/old-solar-panels-can-power-new-future/)); any such scheme needs a cheap, repeatable power measurement.

## Users and context

| User | Need | Context |
| --- | --- | --- |
| Second-life panel refurbisher or collector | Grade each module (A, B, C or reject) against its nameplate and record the result | Yard or warehouse, dozens to hundreds of modules a day, outdoor sun on a rack |
| Small installer or solar technician | Find why a rooftop or off-grid array underperforms: shading, a bad module, a hot connector | Rooftops and ground mounts, single modules or short strings, often in hot sun |
| Buyer of used panels (NGO, cooperative, household) | Check that a used module delivers what the seller claims before paying | Market stall or depot; little training |
| Trainer or TVET college | Teach how an IV curve reveals faults, with an instrument students can build | Classroom and outdoor bench |
| Researcher | Log curves over months for degradation studies at low cost | Outdoor test rack |

Typical modules under test are 36-cell (about 22 V open circuit) to 144 half-cell (about 50 V, 12 to 14 A short circuit). Two older modules in series reach about 75 V.

## Prior work

- **IV Swinger 2** by Chris Satterlee is an open-source tracer of about $50 in parts. It uses load capacitors switched by relays or SSRs and drained through a bleed resistor, and runs from a laptop over USB ([GitHub](https://github.com/csatt/IV_Swinger); [firmware comments](https://raw.githubusercontent.com/csatt/IV_Swinger/master/Arduino/IV_Swinger2/IV_Swinger2.ino)). PVTrace keeps the capacitive load and adds standalone field use, irradiance and temperature sensing, STC translation and grading.
- **Cáceres et al. (2020)** built a capacitive-load tracer for 0 to 100 V and 0 to 12 A for under 200 EUR in materials, aimed at training and research centers that cannot afford commercial tracers ([*Energies*](https://doi.org/10.3390/en13174320)).
- **González et al. (2021)** describe an open IoT tracer on a Raspberry Pi with a programmable electronic load, noting that commercial systems are "generally expensive and closed for modifications" ([*Sensors*](https://doi.org/10.3390/s21227650)).
- **Commercial tracers** cover strings to 1,000 V or more and are priced for professional crews ([Transcat listing](https://www.transcat.com/seaward-pv210-solar-kit-389a912)). Industry guidance is that curves converted to standard test conditions (STC) should be taken at 700 W/m² or more, per IEC 61829 ([Seaward](https://www.seaward.com/gb/support/solar/faqs/29495-curve-tracing-faq-s/)).

The gap PVTrace addresses is a handheld, battery-powered, open tracer that works without a laptop, measures irradiance and module temperature, translates to STC and applies a transparent grading rule.

## Constraints

- Garage-buildable prototype, about $165 USD in parts (`project.yaml` budget, raised from $150 by Amish on 2026-09-25, PVT-DDR-002). The TRL 3 design costs $164.
- Off-the-shelf parts and hand tools; no custom machining.
- Voltage kept below 120 V DC, the extra-low-voltage limit for ripple-free DC in IEC 61140 ([summary](https://en.wikipedia.org/wiki/Extra-low_voltage)). Full strings at 600 to 1,500 V are out of scope.
- Works in full sun at up to 45 °C ambient, with no mains power.
- Open data: every sweep saved as a plain CSV that anyone can reprocess.

## Out of scope

- Strings above 100 V open circuit and any work on live grid-connected arrays without isolation by the system owner.
- Insulation resistance, earth continuity and wet leakage tests (IEC 62446-1 commissioning tests beyond the IV curve).
- Electroluminescence or thermal imaging, which show cracks directly; PVTrace infers them from the curve only.
- Certifying modules for sale; PVTrace grades are indicative until a scheme owner adopts them.

## Co-design checklist

- [ ] Identify a second-life panel partner to agree grade thresholds and throughput. Decided by Amish, 2026-10-02 (PVT-DEC-001, item 5): the first candidate type to approach, not yet agreed, is a second-life panel refurbisher or recycler that tests used modules in volume, with a TVET solar course as a second partner for the teaching use.
- [ ] Interview two or more small installers on which faults they meet most and how they find them today.
- [ ] Confirm the module types in the partner's stock (cell count, Voc, Isc) to fix the voltage and current ranges.
- [ ] Agree what a buyer needs to see on a printed or phone grade label.
- [ ] Check local rules for handling and reselling used modules. In the EU, photovoltaic panels are category 4 equipment under the WEEE Directive ([Directive 2012/19/EU, Annex I and II](https://eur-lex.europa.eu/legal-content/EN/TXT/HTML/?uri=CELEX:32012L0019)).

## Open questions

- Which grade thresholds would a buyer or scheme trust, and must they match an emerging standard?
- Is a reference cell calibrated once against a pyranometer good enough, or does each unit need its own calibration?
- How many sweeps per module make a reliable grade under passing clouds?

> **Safety:** PV modules produce voltage whenever light falls on them and cannot be switched off. Short-circuit current flows as soon as the terminals are bridged, and a DC arc does not self-extinguish like an AC arc. Never break a DC circuit under load, and never connect the tracer to a string above its rating.

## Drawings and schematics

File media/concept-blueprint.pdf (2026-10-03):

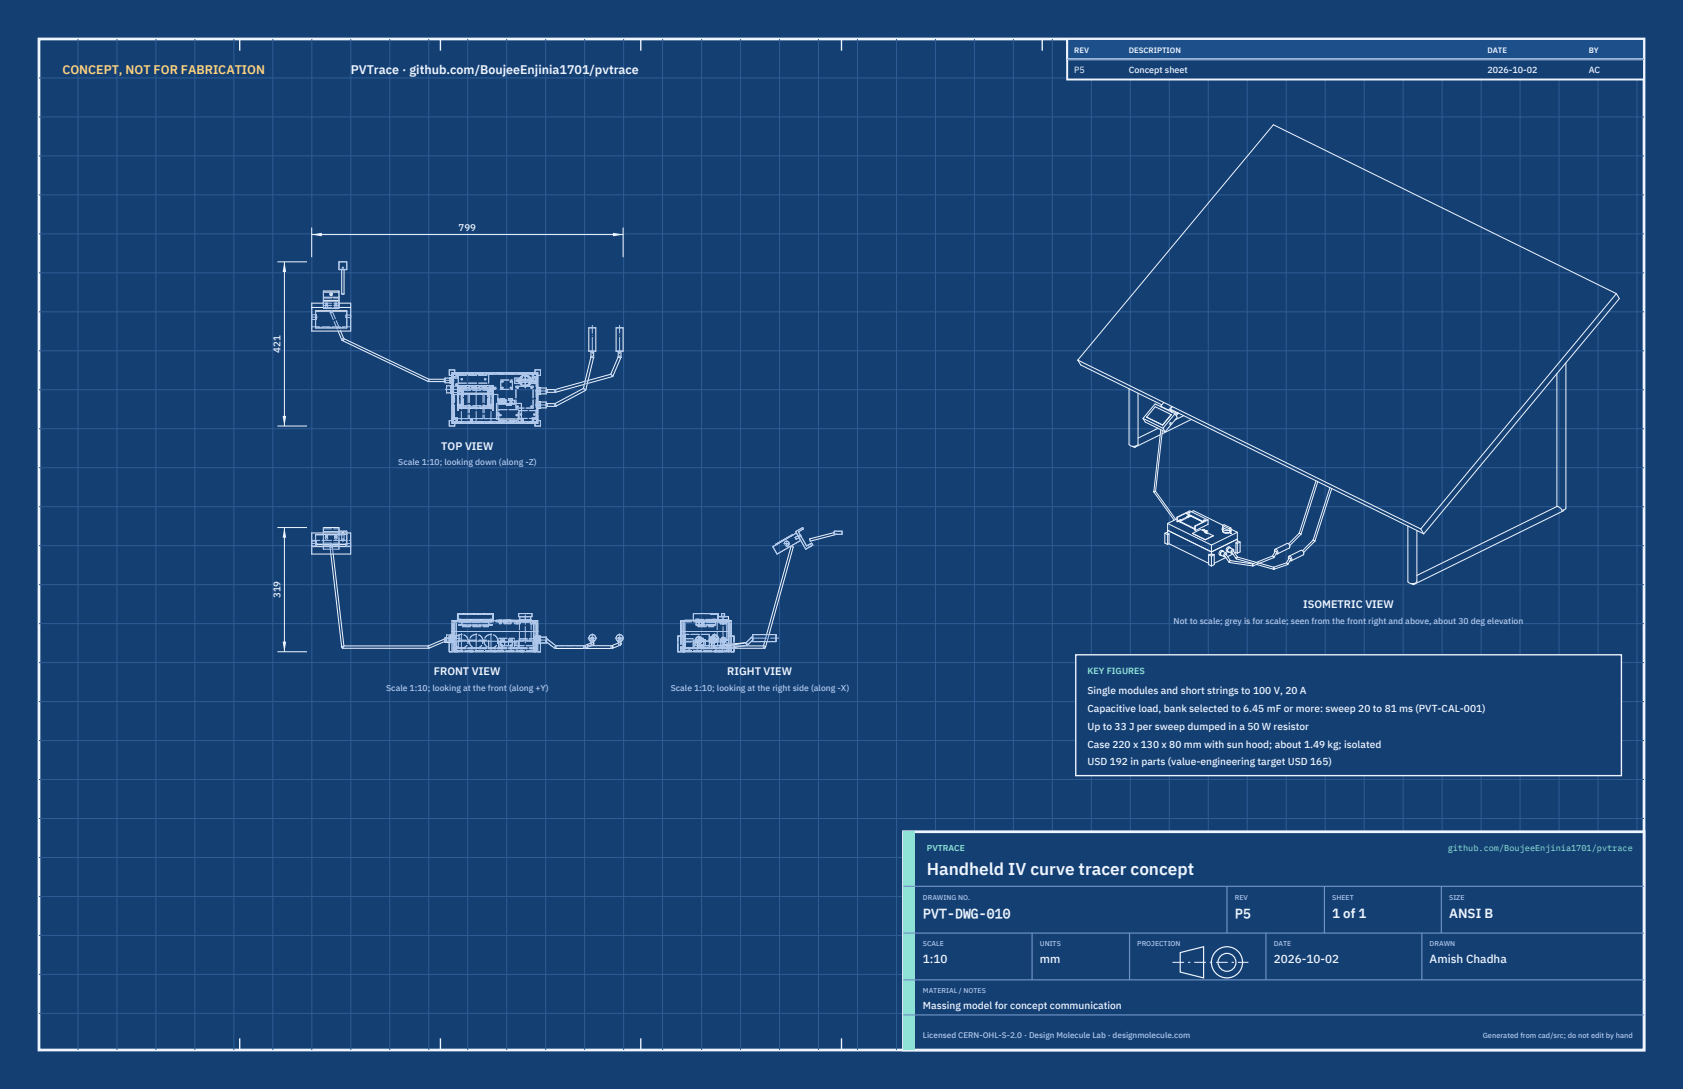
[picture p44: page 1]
CONCEPT, NOT FOR FABRICATION; PVTrace · github.com/BoujeeEnjinia1701/pvtrace; FRONT VIEW; TOP VIEW; RIGHT VIEW; ISOMETRIC VIEW; REV; DESCRIPTION; DATE; Concept sheet; PVTRACE; github.com/BoujeeEnjinia1701/pvtrace; DRAWING NO. PVT-DWG-010; REV P5; SHEET 1 of 1; SIZE ANSI B; SCALE 1:10; UNITS mm; PROJECTION; DRAWN Amish Chadha; Licensed CERN-OHL-S-2.0 · Design Molecule Lab · designmolecule.com; Generated from cad/src; do not edit by hand

Scale 1:10; looking down (along -Z)

Not to scale; grey is for scale; seen from the front right and above, about 30 deg elevation

KEY FIGURES
Single modules and short strings to 100 V, 20 A
Capacitive load, bank selected to 6.45 mF or more: sweep 20 to 81 ms (PVT-CAL-001)
Up to 33 J per sweep dumped in a 50 W resistor
Case 220 x 130 x 80 mm with sun hood; about 1.49 kg; isolated
USD 192 in parts (value-engineering target USD 165)

Scale 1:10; looking at the front (along +Y)

Scale 1:10; looking at the right side (along -X)

Handheld IV curve tracer concept

MATERIAL / NOTES
Massing model for concept communication

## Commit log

2026-09-25 Initial scaffold: standard open hardware layout, CERN-OHL-S v2 + MIT licenses
    Claude-Session: https://claude.ai/code/session_01XuhhSU4W6fYhgCfURbrkut
    [bom.csv]
2026-09-25 Populate to TRL 2: problem, requirements, precis, concept media, BOM and README use cases
    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
    [bom.csv]
2026-09-26 Advance to TRL 3: DDR-001, CAL-001 sizing, parametric model with STEP/STL, GA drawing, priced BOM; TRL 4 on hold
    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
    [bom.csv, pvtrace-assembly.step, pvtrace-assembly.stl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]
2026-09-26 Accept all recommendations (DDR-002), switch footer to designmolecule.com, add README write-up with new inspiration point
    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
    [bom.csv, pvtrace-assembly.step, pvtrace-assembly.stl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]
2026-09-27 Product appearance model and photoreal renders
    Adds cad/src/product_model.py (appearance model for renders only, all main
    dimensions from model.py) and Blender renders in media/render-*.png,
    captioned with the project, repository and viewing direction. README leads
    with the product render; trl stays 3.
    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
2026-10-01 Image quality pass: legible exploded views, flow diagrams and drawing sheets
    Kit 1.6.1 image layout: the parts list sits in its own column, number bubbles sit on visible parts and never overlap, small parts get a leader, pictures are cropped to the subject, flow labels keep numbers with their units, and sheet captions and the revision table no longer overprint. Concept images, blueprint and general arrangement sheet regenerated; repo-specific labels moved clear of other text and lines.
2026-10-01 Kit 1.7.0: constructable design, illustrated build plan and design decisions register
    The design is now constructable: every part can be made and fits its neighbours, with each change recorded in a Design for construction decision record (made under Amish's 2026-09-30 instruction; ope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
    FlexHand also credits Dr. Geeti Chadha as a contribut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
    [bom.csv, pvtrace-assembly.step, pvtrace-assembly.stl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]
2026-10-02 Record Amish's approval of the open-decision recommendations
    Amish approved the recommendation on every open decision in the design decisions register ("i approve your recommendations for all 555 open decisions.", 2026-10-02). Each decision is moved to Decisio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
2026-10-03 Carry approved follow-ups into the design and redo photoreal renders
    Amish approved the follow-up actions from the open-decision sign-off ("APPROVED CHANGES, COMPLETE THESE", 2026-10-02), the design-for-construction change tables in ten repos, the last wave's open dec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
    [bom.csv, pvtrace-assembly.step, pvtrace-assembly.stl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]
2026-10-03 Record Amish's 2026-10-03 decisions; FlatTrike fork and PotPress guard fixes
    Amish, 2026-10-03: "PalletPilot - i accept it"; "FlatTrike - i accept your design recommendation, proceed and execute the solution for fork direction or caster"; "PotPress - move forward with the four guard fixes. I accept the cost."; "GravitySort - i accept your recommendation"; "TIght Margins - i accept the margins"; "Cost over target - i accept all the cost variations and overruns". FlatTrike knuckle forks turned to trail (35 mm trail); PotPress finer mesh, small-hole plates, top beam and crank bracket covers, ISO 13857 desk check now met on paper. Registers, requirements, drawings, pictures, renders and PDFs upd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

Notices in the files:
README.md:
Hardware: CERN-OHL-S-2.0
